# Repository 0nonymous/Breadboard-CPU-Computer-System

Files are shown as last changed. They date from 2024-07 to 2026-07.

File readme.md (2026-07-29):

# 8-Bit Microcoded Breadboard CPU

## Overview

The CPU

This project is a fully microcoded 8-bit CPU designed from scratch and implemented using 100+ 74LS-series ICs across 40+ breadboards.

The system includes:

- Custom 8-bit CISC-style instruction set (0x00–0x45 implemented)
- 8-bit data bus
- 16-bit address bus (64KB address space)
- Fully horizontal microcoded control unit (48-bit control word)
- 6 × AT28C16 EEPROM control store
- Memory-mapped I/O
- 6522 VIA interface (32 GPIO)
- Dual-port shared memory VGA subsystem
- Custom Python two-pass assembler and ROM flashing pipeline
- Working assembly programs including Snake

This is the third architectural iteration. Earlier versions exposed architectural limitations. The current version runs reliably at approximately ~0.25 MHz.

---

## Assembly Syntax

The assembler uses suffix symbols to indicate addressing modes:

- `$` = Immediate
- `@` = Absolute
- `#` = Indirect (pointer-based)
- `&` = Absolute + X offset
- No suffix = Implied

Example:
```
lda $10
lda @2000
lda #3000
lda &4000
inx
```

---

## Complete Instruction Encoding Table

```
0x00  lda $
0x01  lda @
0x02  lda #
0x03  lda &

0x04  ldx $
0x05  ldx @
0x06  ldx #
0x07  ldx &

0x08  inx
0x09  dex
0x0A  txa
0x0B  tax

0x0C  add $
0x0D  add @
0x0E  add #
0x0F  add &

0x10  sub $
0x11  sub @
0x12  sub #
0x13  sub &

0x14  adc $
0x15  adc @
0x16  adc #
0x17  adc &

0x18  sbc $
0x19  sbc @
0x1A  sbc #
0x1B  sbc &

0x1C  and $
0x1D  and @
0x1E  and #
0x1F  and &

0x20  orr $
0x21  orr @
0x22  orr #
0x23  orr &

0x24  shr
0x25  shl
0x26  ror
0x27  rol

0x28  sta @
0x29  sta #
0x2A  sta &

0x2B  stx @
0x2C  stx #
0x2D  stx &

0x2E  pla
0x2F  pha
0x30  plx
0x31  phx
0x32  plf
0x33  phf

0x34  xla
0x35  xlx

0x36  jsr @
0x37  rsr

0x38  clf
0x39  msk
0x3A  umk

0x3B  jmp @
0x3C  beq @
0x3D  bne @
0x3E  bmi @
0x3F  bpl @
0x40  bcs @
0x41  bcc @

0x42  ila
0x43  ilx
0x44  isa
0x45  isx
```

---

## CPU Architecture

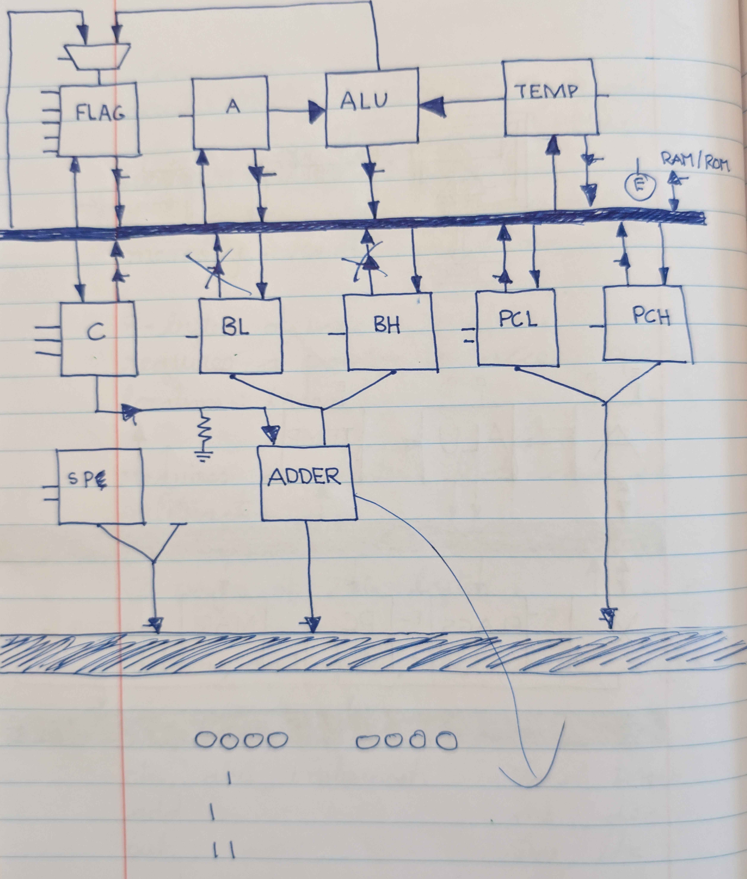
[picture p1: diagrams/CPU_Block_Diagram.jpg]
Block Diagrams


### Registers

- A — 8-bit accumulator
- B — 8-bit helper register
- X — 8-bit index register
- SP — 8-bit stack pointer (descending from 0xFF)
- PC — 16-bit program counter
- MAR — 16-bit memory address register
- IR — 8-bit instruction register
- Flags (3-bit):
  - Zero
  - Carry
  - Negative

---

## Buses and Datapath

- 8-bit internal data bus
- 16-bit address bus
- Shared bus architecture with gated register in/out signals
- MAR handles memory addressing
- PC high/low bytes independently gated

---

## ALU Implementation

The ALU is implemented using discrete TTL logic:

- 74LS283 — Addition core
- 74LS86 — 2's Complement
- 74LS08 — AND
- 74LS32 — OR
- Shift/rotate implemented via combinational wiring and arithmetic reuse
- Flag updates controlled via microcode signals (C SET, SZ SET, etc.)

---

## Microcoded Control Unit

Control Signals

The CPU uses a horizontal microcode architecture.

- Microinstruction width: 48 bits
- Control store: 6 × AT28C16 EEPROMs
- Microaddress width: 11 bits
- Microaddress formation:
  opcode[7:0] || microstep[2:0]
- Maximum microsteps per instruction: 7 (+ fetch cycle)

The microstep counter increments sequentially and overflows to reset.

Conditional branches do not alter microcode sequencing.  
Instead, discrete logic gates PC load signals based on flag conditions (Z, C, S).

Each microinstruction directly drives register enables, ALU operations, bus drivers, PC control, memory read/write, and flag updates.

---

## Memory Map

Total address space: 64KB

Current configuration includes:

- 2KB ROM
- 6522 VIA (32 GPIO)
- Memory-mapped I/O
- ~512B dual-port shared RAM (VGA subsystem)

Stack resides in a dedicated page and grows downward.

---

## VGA Subsystem

The CPU integrates with a separate VGA driver module.

Features:

- Text mode output
- 25 columns × 16 rows
- Hardware-assisted scrolling
- Dual-port shared memory interface between CPU and VGA driver
- Polling-based communication

The CPU writes character data into shared dual-port memory.  
The VGA module independently reads this memory to generate video timing and pixel output.

VGA signal generation approach was inspired by Ben Eater’s methodology and adapted for this architecture.

---

## Toolchain

Custom Python-based programming pipeline:

Two-pass assembler:
- Pass 1: label resolution
- Pass 2: opcode and operand encoding

Outputs a hex array representation of machine code.

A secondary Python script converts the output into binary format for ROM flashing via XGPro.

---

## Programs Written

- Instruction verification programs
- Fibonacci sequence
- Calculator utilities
- Keypad-driven applications
- VGA name/text rendering
- Snake (fully playable)

---

## Hardware Engineering and Debugging

Major issue encountered:
- Race condition causing unintended PC double-increment due to propagation delay

Debugging involved:

- Oscilloscope-based timing analysis
- Star power distribution layout
- Extensive decoupling capacitors
- Signal integrity stabilization

System runs reliably at approximately ~1 MHz.  
Estimated current draw: ~1.2–1.6A under load.

---

## Design Influences

- Instruction set loosely inspired by 6502 concepts
- Breadboard methodology and VGA experimentation influenced by Ben Eater
- Control logic, ISA structure, microcode, and integration independently designed

---

## Future Work

- Implement machine code monitor
- Potential RISC-style redesign
- FPGA implementation exploration
- Pipelining experimentation

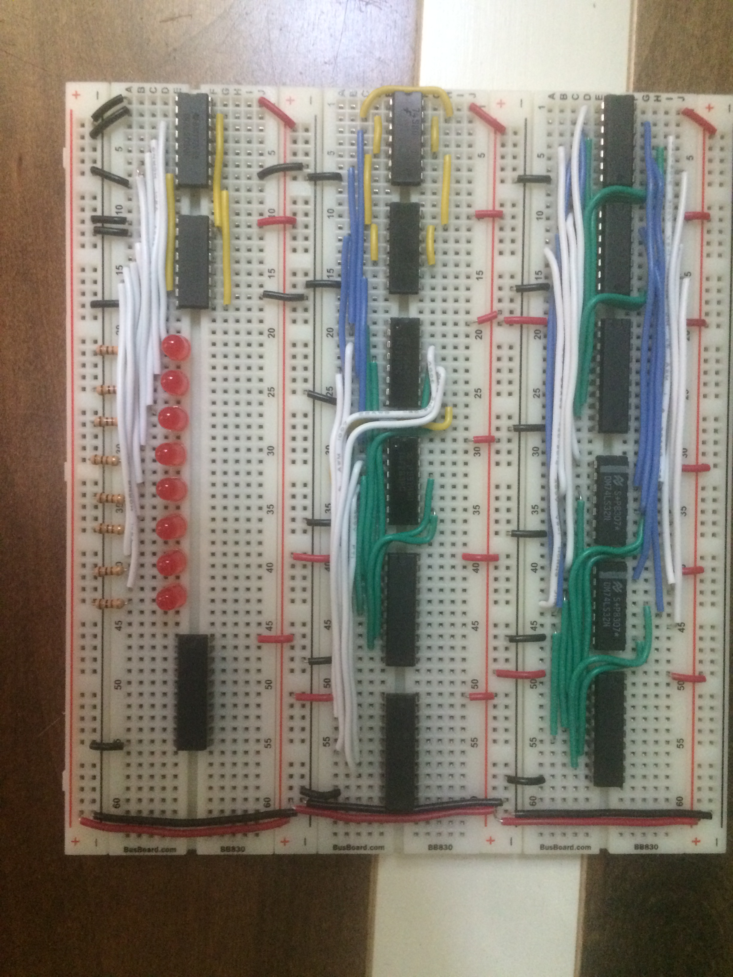
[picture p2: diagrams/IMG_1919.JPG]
A Register and ALU

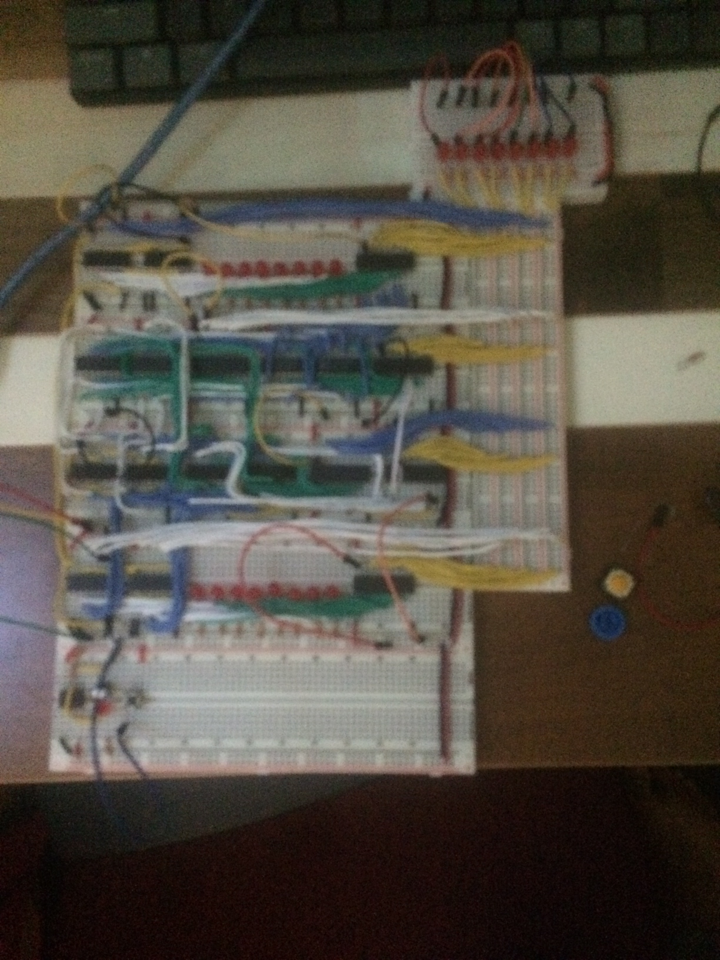
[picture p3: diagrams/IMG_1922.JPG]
A Registers, B Register, ALU, Data Bus, and Clock

Power Distribution
Decoupling Capacitors

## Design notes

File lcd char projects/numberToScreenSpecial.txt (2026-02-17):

; keypad = port b

; port initialization - set port b to half input and half output
  lda $0f
  sta @fee3

; port initialization - set port a to full output
  lda $ff
  sta @fee2

; functions: initalize screen
; functions: shift data
; functions: send to screen
; variables: index
; addresses: fef3 ddra, fef2 ddrb 
; addresses: fef1 ra, fef0 rb

; create some space: 0801, 0802, 0803, 0804 msb to lsb for digit 1; 0806, 0807, 0808, 0809
; pointer 0800 val of 01
  lda $00
  sta @0800

; set ports to output
  lda $ff
  sta @fef2
  sta @fef3

; initalize
  lda $38
  sta @fef1
  lda $02
  sta @fef0
  lda $00
  sta @fef0

; set parameters
  lda $0f
  sta @fef1
  lda $02
  sta @fef0
  lda $00
  sta @fef0

; increment lcd
  lda $06 ;26
  sta @fef1
  lda $02
  sta @fef0
  lda $00
  sta @fef0

; main loop
mainLoop:
  jsr @readKeypad
  jsr @encodeKeypad

; experimental: check if new key is pressed
  pha  ; save a copy of 'A'
  sub @fee0  ; check how it compares to a previous state
  pla  ; return 'A' to its original state
  sta @fee0
  beq @theTrueNextStep

ifUnique:
  pha  
  sub $10
  pla  
  beq @theTrueNextStep

ifReadyToPrint:
; save an incremenet
  ldx @0800
  sta &0801
  inx  
  stx @0800
  jsr @printer

theNextStep:
  lda @0800
  tax  
  sub $04
  beq @recall
  txa  
  sub $09
  beq @operate
  jmp @theTrueNextStep

recall:
  ldx @0800
  inx  
  stx @0800
  lda $fb
  jsr @printer
  jmp @theTrueNextStep

operate:
  ldx @0800
  inx  
  stx @0800
  lda $0d
  jsr @printer
  add $00

  ldx $03
  jsr @addDigit
  dex  
  jsr @addDigit
  dex  
  jsr @addDigit
  dex  
  jsr @addDigit

  lda @0801
  jsr @printer
  lda @0802
  jsr @printer
  lda @0803
  jsr @printer
  lda @0804
  jsr @printer

theTrueNextStep:
  jmp @mainLoop

printer:
  pha  
  add $30  ; offset to ASCII
  phx  
  pha  
  jsr @print
  pla  
  plx  
  pla  
  rsr  

; read keypad function - return value in a register
readKeypad:
; push everything to stack
  phx  
  phf  

; create an iterator
  lda $01

readKeypadLoop:
  tax  
  sta @fee1
  sub @fee1
  bne @readKeypadBreak
  txa  
  sub $08
  beq @readKeypadBreak
  txa  
  shl  
  jmp @readKeypadLoop

readKeypadBreak:
  lda @fee1

; pull everything from stack
  plf  
  plx  
  rsr  

encodeKeypad:
  phx  
  phf  

  ldx $00 ; create an iterator

encodeKeypadLoop:
  pha  ; preserve value in a register
  sub &encodingArray
  pla  
  beq @encodeKeypadBreak
  pha  
  inx  
  txa  
  sub $10
  pla  
  bne @encodeKeypadLoop

encodeKeypadBreak:
  txa  
  plf  
  plx  
  rsr  

print:
  ldx $03
  xla  
  sta @fef1
  lda $03
  sta @fef0
  lda $00
  sta @fef0 
  rsr  

addDigit:
; take number from 0801 + x where x is preserved
; use flags
  pha  

  lda &0801
  adc &0806

  sub $0a
  bpl @greaterThan9
  jmp @lessThan10

greaterThan9:
  sta &0801
  lda $ff
  add $01
  jmp @addDigitConverge

lessThan10:
  add $0a
  sta &0801
  add $00
  jmp @addDigitConverge

addDigitConverge:
  pla  
  rsr  

encodingArray:
  byt $28
  byt $11
  byt $21
  byt $41

  byt $12
  byt $22
  byt $42
  byt $14

  byt $24
  byt $44
  byt $81
  byt $82

  byt $84
  byt $88
  byt $18
  byt $48

  end

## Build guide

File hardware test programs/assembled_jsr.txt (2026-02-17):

[0x3b,0x1,0x5,0x0,0x0,0x0,0x0,0x0,0x0,0x0,0x0,0x0,0x0,0x0,0x0,0x0,0x0,0x0,0x0,0x0,0x0,0x0,0x0,0x0,0x0,0x0,0x0,0x0,0x0,0x0,0x0,0x0,0x0,0x0,0x0,0x0,0x0,0x0,0x0,0x0,0x0,0x0,0x0,0x0,0x0,0x0,0x0,0x0,0x0,0x0,0x0,0x0,0x0,0x0,0x0,0x0,0x0,0x0,0x0,0x0,0x0,0x0,0x0,0x0,0x0,0x0,0x0,0x0,0x0,0x0,0x0,0x0,0x0,0x0,0x0,0x0,0x0,0x0,0x0,0x0,0x0,0x0,0x0,0x0,0x0,0x0,0x0,0x0,0x0,0x0,0x0,0x0,0x0,0x0,0x0,0x0,0x0,0x0,0x0,0x0,0x0,0x0,0x0,0x0,0x0,0x0,0x0,0x0,0x0,0x0,0x0,0x0,0x0,0x0,0x0,0x0,0x0,0x0,0x0,0x0,0x0,0x0,0x0,0x0,0x0,0x0,0x0,0x0,0x0,0x0,0x0,0x0,0x0,0x0,0x0,0x0,0x0,0x0,0x0,0x0,0x0,0x0,0x0,0x0,0x0,0x0,0x0,0x0,0x0,0x0,0x0,0x0,0x0,0x0,0x0,0x0,0x0,0x0,0x0,0x0,0x0,0x0,0x0,0x0,0x0,0x0,0x0,0x0,0x0,0x0,0x0,0x0,0x0,0x0,0x0,0x0,0x0,0x0,0x0,0x0,0x0,0x0,0x0,0x0,0x0,0x0,0x0,0x0,0x0,0x0,0x0,0x0,0x0,0x0,0x0,0x0,0x0,0x0,0x0,0x0,0x0,0x0,0x0,0x0,0x0,0x0,0x0,0x0,0x0,0x0,0x0,0x0,0x0,0x0,0x0,0x0,0x0,0x0,0x0,0x0,0x0,0x0,0x0,0x0,0x0,0x0,0x0,0x0,0x0,0x0,0x0,0x0,0x0,0x0,0x0,0x0,0x0,0x0,0x0,0x0,0x0,0x0,0x0,0x0,0x0,0x0,0x0,0x0,0x0,0x0,0x0,0x0,0x0,0x0,0x0,0x0,0x0,0x0,0x0,0x0,0x0,0x0,0x0,0x0,0x0,0x0,0x0,0x0,0x0,0x0,0x0,0x0,0x0,0x0,0x0,0x0,0x0,0x0,0x0,0x0,0x0,0x0,0x0,0x0,0x0,0x0,0x0,0x0,0x0,0x0,0x0,0x0,0x0,0x0,0x0,0x0,0x0,0x0,0x0,0x0,0x0,0x0,0x0,0x0,0x0,0x0,0x0,0x0,0x0,0x0,0x0,0x0,0x0,0x0,0x0,0x0,0x0,0x0,0x0,0x0,0x0,0x0,0x0,0x0,0x0,0x0,0x0,0x0,0x0,0x0,0x0,0x0,0x0,0x0,0x0,0x0,0x0,0x0,0x0,0x0,0x0,0x0,0x0,0x0,0x0,0x0,0x0,0x0,0x0,0x0,0x0,0x0,0x0,0x0,0x0,0x0,0x0,0x0,0x0,0x0,0x0,0x0,0x0,0x0,0x0,0x0,0x0,0x0,0x0,0x0,0x0,0x0,0x0,0x0,0x0,0x0,0x0,0x0,0x0,0x0,0x0,0x0,0x0,0x0,0x0,0x0,0x0,0x0,0x0,0x0,0x0,0x0,0x0,0x0,0x0,0x0,0x0,0x0,0x0,0x0,0x0,0x0,0x0,0x0,0x0,0x0,0x0,0x0,0x0,0x0,0x0,0x0,0x0,0x0,0x0,0x0,0x0,0x0,0x0,0x0,0x0,0x0,0x0,0x0,0x0,0x0,0x0,0x0,0x0,0x0,0x0,0x0,0x0,0x0,0x0,0x0,0x0,0x0,0x0,0x0,0x0,0x0,0x0,0x0,0x0,0x0,0x0,0x0,0x0,0x0,0x0,0x0,0x0,0x0,0x0,0x0,0x0,0x0,0x0,0x0,0x0,0x0,0x0,0x0,0x0,0x0,0x0,0x0,0x0,0x0,0x0,0x0,0x0,0x0,0x0,0x0,0x0,0x0,0x0,0x0,0x0,0x0,0x0,0x0,0x0,0x0,0x0,0x0,0x0,0x0,0x0,0x0,0x0,0x0,0x0,0x0,0x0,0x0,0x0,0x0,0x0,0x0,0x0,0x0,0x0,0x0,0x0,0x0,0x0,0x0,0x0,0x0,0x0,0x0,0x0,0x0,0x0,0x0,0x0,0x0,0x0,0x0,0x0,0x0,0x0,0x0,0x0,0x0,0x0,0x0,0x0,0x0,0x0,0x0,0x0,0x0,0x0,0x0,0x0,0x0,0x0,0x0,0x0,0x0,0x0,0x0,0x0,0x0,0x0,0x0,0x0,0x0,0x0,0x0,0x0,0x0,0x0,0x0,0x0,0x0,0x0,0x0,0x0,0x0,0x0,0x0,0x0,0x0,0x0,0x0,0x0,0x0,0x0,0x0,0x0,0x0,0x0,0x0,0x0,0x0,0x0,0x0,0x0,0x0,0x0,0x0,0x0,0x0,0x0,0x0,0x0,0x0,0x0,0x0,0x0,0x0,0x0,0x0,0x0,0x0,0x0,0x0,0x0,0x0,0x0,0x0,0x0,0x0,0x0,0x0,0x0,0x0,0x0,0x0,0x0,0x0,0x0,0x0,0x0,0x0,0x0,0x0,0x0,0x0,0x0,0x0,0x0,0x0,0x0,0x0,0x0,0x0,0x0,0x0,0x0,0x0,0x0,0x0,0x0,0x0,0x0,0x0,0x0,0x0,0x0,0x0,0x0,0x0,0x0,0x0,0x0,0x0,0x0,0x0,0x0,0x0,0x0,0x0,0x0,0x0,0x0,0x0,0x0,0x0,0x0,0x0,0x0,0x0,0x0,0x0,0x0,0x0,0x0,0x0,0x0,0x0,0x0,0x0,0x0,0x0,0x0,0x0,0x0,0x0,0x0,0x0,0x0,0x0,0x0,0x0,0x0,0x0,0x0,0x0,0x0,0x0,0x0,0x0,0x0,0x0,0x0,0x0,0x0,0x0,0x0,0x0,0x0,0x0,0x0,0x0,0x0,0x0,0x0,0x0,0x0,0x0,0x0,0x0,0x0,0x0,0x0,0x0,0x0,0x0,0x0,0x0,0x0,0x0,0x0,0x0,0x0,0x0,0x0,0x0,0x0,0x0,0x0,0x0,0x0,0x0,0x0,0x0,0x0,0x0,0x0,0x0,0x0,0x0,0x0,0x0,0x0,0x0,0x0,0x0,0x0,0x0,0x0,0x0,0x0,0x0,0x0,0x0,0x0,0x0,0x0,0x0,0x0,0x0,0x0,0x0,0x0,0x0,0x0,0x0,0x0,0x0,0x0,0x0,0x0,0x0,0x0,0x0,0x0,0x0,0x0,0x0,0x0,0x0,0x0,0x0,0x0,0x0,0x0,0x0,0x0,0x0,0x0,0x0,0x0,0x0,0x0,0x0,0x0,0x0,0x0,0x0,0x0,0x0,0x0,0x0,0x0,0x0,0x0,0x0,0x0,0x0,0x0,0x0,0x0,0x0,0x0,0x0,0x0,0x0,0x0,0x0,0x0,0x0,0x0,0x0,0x0,0x0,0x0,0x0,0x0,0x0,0x0,0x0,0x0,0x0,0x0,0x0,0x0,0x0,0x0,0x0,0x0,0x0,0x0,0x0,0x0,0x0,0x0,0x0,0x0,0x0,0x0,0x0,0x0,0x0,0x0,0x0,0x0,0x0,0x0,0x0,0x0,0x0,0x0,0x0,0x0,0x0,0x0,0x0,0x0,0x0,0x0,0x0,0x0,0x0,0x0,0x0,0x0,0x0,0x0,0x0,0x0,0x0,0x0,0x0,0x0,0x0,0x0,0x0,0x0,0x0,0x0,0x0,0x0,0x0,0x0,0x0,0x0,0x0,0x0,0x0,0x0,0x0,0x0,0x0,0x0,0x0,0x0,0x0,0x0,0x0,0x0,0x0,0x0,0x0,0x0,0x0,0x0,0x0,0x0,0x0,0x0,0x0,0x0,0x0,0x0,0x0,0x0,0x0,0x0,0x0,0x0,0x0,0x0,0x0,0x0,0x0,0x0,0x0,0x0,0x0,0x0,0x0,0x0,0x0,0x0,0x0,0x0,0x0,0x0,0x0,0x0,0x0,0x0,0x0,0x0,0x0,0x0,0x0,0x0,0x0,0x0,0x0,0x0,0x0,0x0,0x0,0x0,0x0,0x0,0x0,0x0,0x0,0x0,0x0,0x0,0x0,0x0,0x0,0x0,0x0,0x0,0x0,0x0,0x0,0x0,0x0,0x0,0x0,0x0,0x0,0x0,0x0,0x0,0x0,0x0,0x0,0x0,0x0,0x0,0x0,0x0,0x0,0x0,0x0,0x0,0x0,0x0,0x0,0x0,0x0,0x0,0x0,0x0,0x0,0x0,0x0,0x0,0x0,0x0,0x0,0x0,0x0,0x0,0x0,0x0,0x0,0x0,0x0,0x0,0x0,0x0,0x0,0x0,0x0,0x0,0x0,0x0,0x0,0x0,0x0,0x0,0x0,0x0,0x0,0x0,0x0,0x0,0x0,0x0,0x0,0x0,0x0,0x0,0x0,0x0,0x0,0x0,0x0,0x0,0x0,0x0,0x0,0x0,0x0,0x0,0x0,0x0,0x0,0x0,0x0,0x0,0x0,0x0,0x0,0x0,0x0,0x0,0x0,0x0,0x0,0x0,0x0,0x0,0x0,0x0,0x0,0x0,0x0,0x0,0x0,0x0,0x0,0x0,0x0,0x0,0x0,0x0,0x0,0x0,0x0,0x0,0x0,0x0,0x0,0x0,0x0,0x0,0x0,0x0,0x0,0x0,0x0,0x0,0x0,0x0,0x0,0x0,0x0,0x0,0x0,0x0,0x0,0x0,0x0,0x0,0x0,0x0,0x0,0x0,0x0,0x0,0x0,0x0,0x0,0x0,0x0,0x0,0x0,0x0,0x0,0x0,0x0,0x0,0x0,0x0,0x0,0x0,0x0,0x0,0x0,0x0,0x0,0x0,0x0,0x0,0x0,0x0,0x0,0x0,0x0,0x0,0x0,0x0,0x0,0x0,0x0,0x0,0x0,0x0,0x0,0x0,0x0,0x0,0x0,0x0,0x0,0x0,0x0,0x0,0x0,0x0,0x0,0x0,0x0,0x0,0x0,0x0,0x0,0x0,0x0,0x0,0x0,0x0,0x0,0x0,0x0,0x0,0x0,0x0,0x0,0x0,0x0,0x0,0x0,0x0,0x0,0x0,0x0,0x0,0x0,0x0,0x0,0x0,0x0,0x0,0x0,0x0,0x0,0x0,0x0,0x0,0x0,0x0,0x0,0x0,0x0,0x0,0x0,0x0,0x0,0x0,0x0,0x0,0x0,0x0,0x0,0x0,0x0,0x0,0x0,0x0,0x0,0x0,0x0,0x0,0x0,0x0,0x0,0x0,0x0,0x0,0x0,0x0,0x0,0x0,0x0,0x0,0x0,0x0,0x0,0x0,0x0,0x0,0x0,0x0,0x0,0x0,0x0,0x0,0x0,0x0,0x0,0x0,0x0,0x0,0x36,0xa,0x6,0x3b,0x1,0x5,0x0,0x0,0x0,0x0,0x0,0x0,0x0,0x0,0x0,0x0,0x0,0x0,0x0,0x0,0x0,0x0,0x0,0x0,0x0,0x0,0x0,0x0,0x0,0x0,0x0,0x0,0x0,0x0,0x0,0x0,0x0,0x0,0x0,0x0,0x0,0x0,0x0,0x0,0x0,0x0,0x0,0x0,0x0,0x0,0x0,0x0,0x0,0x0,0x0,0x0,0x0,0x0,0x0,0x0,0x0,0x0,0x0,0x0,0x0,0x0,0x0,0x0,0x0,0x0,0x0,0x0,0x0,0x0,0x0,0x0,0x0,0x0,0x0,0x0,0x0,0x0,0x0,0x0,0x0,0x0,0x0,0x0,0x0,0x0,0x0,0x0,0x0,0x0,0x0,0x0,0x0,0x0,0x0,0x0,0x0,0x0,0x0,0x0,0x0,0x0,0x0,0x0,0x0,0x0,0x0,0x0,0x0,0x0,0x0,0x0,0x0,0x0,0x0,0x0,0x0,0x0,0x0,0x0,0x0,0x0,0x0,0x0,0x0,0x0,0x0,0x0,0x0,0x0,0x0,0x0,0x0,0x0,0x0,0x0,0x0,0x0,0x0,0x0,0x0,0x0,0x0,0x0,0x0,0x0,0x0,0x0,0x0,0x0,0x0,0x0,0x0,0x0,0x0,0x0,0x0,0x0,0x0,0x0,0x0,0x0,0x0,0x0,0x0,0x0,0x0,0x0,0x0,0x0,0x0,0x0,0x0,0x0,0x0,0x0,0x0,0x0,0x0,0x0,0x0,0x0,0x0,0x0,0x0,0x0,0x0,0x0,0x0,0x0,0x0,0x0,0x0,0x0,0x0,0x0,0x0,0x0,0x0,0x0,0x0,0x0,0x0,0x0,0x0,0x0,0x0,0x0,0x0,0x0,0x0,0x0,0x0,0x0,0x0,0x0,0x0,0x0,0x0,0x0,0x0,0x0,0x0,0x0,0x0,0x0,0x0,0x0,0x0,0x0,0x0,0x0,0x0,0x0,0x0,0x0,0x0,0x0,0x0,0x0,0x0,0x0,0x0,0x0,0x0,0x0,0x0,0x0,0x0,0x0,0x0,0x0,0x0,0x0,0x0,0x0,0x0,0x0,0x0,0x0,0x0,0x37,0x0,0x0,0x0,0x0,0x0,0x0,0x0,0x0,0x0,0x0,0x0,0x0,0x0,0x0,0x0,0x0,0x0,0x0,0x0,0x0,0x0,0x0,0x0,0x0,0x0,0x0,0x0,0x0,0x0,0x0,0x0,0x0,0x0,0x0,0x0,0x0,0x0,0x0,0x0,0x0,0x0,0x0,0x0,0x0,0x0,0x0,0x0,0x0,0x0,0x0,0x0,0x0,0x0,0x0,0x0,0x0,0x0,0x0,0x0,0x0,0x0,0x0,0x0,0x0,0x0,0x0,0x0,0x0,0x0,0x0,0x0,0x0,0x0,0x0,0x0,0x0,0x0,0x0,0x0,0x0,0x0,0x0,0x0,0x0,0x0,0x0,0x0,0x0,0x0,0x0,0x0,0x0,0x0,0x0,0x0,0x0,0x0,0x0,0x0,0x0,0x0,0x0,0x0,0x0,0x0,0x0,0x0,0x0,0x0,0x0,0x0,0x0,0x0,0x0,0x0,0x0,0x0,0x0,0x0,0x0,0x0,0x0,0x0,0x0,0x0,0x0,0x0,0x0,0x0,0x0,0x0,0x0,0x0,0x0,0x0,0x0,0x0,0x0,0x0,0x0,0x0,0x0,0x0,0x0,0x0,0x0,0x0,0x0,0x0,0x0,0x0,0x0,0x0,0x0,0x0,0x0,0x0,0x0,0x0,0x0,0x0,0x0,0x0,0x0,0x0,0x0,0x0,0x0,0x0,0x0,0x0,0x0,0x0,0x0,0x0,0x0,0x0,0x0,0x0,0x0,0x0,0x0,0x0,0x0,0x0,0x0,0x0,0x0,0x0,0x0,0x0,0x0,0x0,0x0,0x0,0x0,0x0,0x0,0x0,0x0,0x0,0x0,0x0,0x0,0x0,0x0,0x0,0x0,0x0,0x0,0x0,0x0,0x0,0x0,0x0,0x0,0x0,0x0,0x0,0x0,0x0,0x0,0x0,0x0,0x0,0x0,0x0,0x0,0x0,0x0,0x0,0x0,0x0,0x0,0x0,0x0,0x0,0x0,0x0,0x0,0x0,0x0,0x0,0x0,0x0,0x0,0x0,0x0,0x0,0x0,0x0,0x0,0x0,0x0,0x0,0x0,0x0,0x0,0x0,0x0,0x0,0x0,0x0,0x0,0x0,0x0,0x0,0x0,0x0,0x0,0x0,0x0,0x0,0x0,0x0,0x0,0x0,0x0,0x0,0x0,0x0,0x0,0x0,0x0,0x0,0x0,0x0,0x0,0x0,0x0,0x0,0x0,0x0,0x0,0x0,0x0,0x0,0x0,0x0,0x0,0x0,0x0,0x0,0x0,0x0,0x0,0x0,0x0,0x0,0x0,0x0,0x0,0x0,0x0,0x0,0x0,0x0,0x0,0x0,0x0,0x0,0x0,0x0,0x0,0x0,0x0,0x0,0x0,0x0,0x0,0x0,0x0,0x0,0x0,0x0,0x0,0x0,0x0,0x0,0x0,0x0,0x0,0x0,0x0,0x0,0x0,0x0,0x0,0x0,0x0,0x0,0x0,0x0,0x0,0x0,0x0,0x0,0x0,0x0,0x0,0x0,0x0,0x0,0x0,0x0,0x0,0x0,0x0,0x0,0x0,0x0,0x0,0x0,0x0,0x0,0x0,0x0,0x0,0x0,0x0,0x0,0x0,0x0,0x0,0x0,0x0,0x0,0x0,0x0,0x0,0x0,0x0,0x0,0x0,0x0,0x0,0x0,0x0,0x0,0x0,0x0,0x0,0x0,0x0,0x0,0x0,0x0,0x0,0x0,0x0,0x0,0x0,0x0,0x0,0x0,0x0,0x0,0x0,0x0,0x0,0x0,0x0,0x0,0x0,0x0,0x0,0x0,0x0,0x0,0x0,0x0,0x0,0x0,0x0,0x0,0x0,0x0,0x0,0x0,0x0,0x0,0x0,0x0,0x0,0x0,0x0,0x0,0x0,0x0,0x0,0x0,0x0,0x0,0x0,0x0,0x0,0x0,0x0,0x0,0x0,0x0,0x0,0x0,0x0,0x0,0x0,0x0,0x0,0x0,0x0,0x0,0x0,0x0,0x0,0x0,0x0,0x0,0x0,0x0,0x0,0x0,0x0,0x0,0x0,0x0,0x0,0x0,0x0,0x0,0x0,0x0,0x0,0x0,0x0,0x0,0x0,0x0,0x0,0x0,0x0,0x0,]

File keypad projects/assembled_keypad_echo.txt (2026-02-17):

[0x0,0xff,0x28,0xf2,0xfe,0x0,0x3,0x4,0x23,0x28,0xf0,0xfe,0x2b,0xf0,0xfe,0x28,0xf0,0xfe,0x2b,0xf0,0xfe,0x28,0xf0,0xfe,0x2b,0xf0,0xfe,0x28,0xf0,0xfe,0x0,0x2,0x4,0x22,0x28,0xf0,0xfe,0x2b,0xf0,0xfe,0x28,0xf0,0xfe,0x2b,0xf0,0xfe,0x28,0xf0,0xfe,0x0,0x8,0x4,0x28,0x28,0xf0,0xfe,0x2b,0xf0,0xfe,0x28,0xf0,0xfe,0x0,0x0,0x4,0x20,0x28,0xf0,0xfe,0x2b,0xf0,0xfe,0x28,0xf0,0xfe,0x0,0xc,0x4,0x2c,0x28,0xf0,0xfe,0x2b,0xf0,0xfe,0x28,0xf0,0xfe,0x0,0x0,0x4,0x20,0x28,0xf0,0xfe,0x2b,0xf0,0xfe,0x28,0xf0,0xfe,0x0,0x2,0x4,0x22,0x28,0xf0,0xfe,0x2b,0xf0,0xfe,0x28,0xf0,0xfe,0x0,0x0,0x4,0x20,0x28,0xf0,0xfe,0x2b,0xf0,0xfe,0x28,0xf0,0xfe,0x0,0x6,0x4,0x26,0x28,0xf0,0xfe,0x2b,0xf0,0xfe,0x28,0xf0,0xfe,0x0,0x14,0x4,0x34,0x28,0xf0,0xfe,0x2b,0xf0,0xfe,0x28,0xf0,0xfe,0x0,0x18,0x4,0x38,0x28,0xf0,0xfe,0x2b,0xf0,0xfe,0x28,0xf0,0xfe,0x3b,0xa6,0x0,0x0,0x0,0x0,0x0,0x0,0x0,0x0,0x0,0x0,0x0,0x0,0x0,0x0,0x0,0x0,0x0,0x0,0x0,0x0,0x0,0x0,0x0,0x0,0x0,0x0,0x0,0x0,0x0,0x0,0x0,0x0,0x0,0x0,0x0,0x0,0x0,0x0,0x0,0x0,0x0,0x0,0x0,0x0,0x0,0x0,0x0,0x0,0x0,0x0,0x0,0x0,0x0,0x0,0x0,0x0,0x0,0x0,0x0,0x0,0x0,0x0,0x0,0x0,0x0,0x0,0x0,0x0,0x0,0x0,0x0,0x0,0x0,0x0,0x0,0x0,0x0,0x0,0x0,0x0,0x0,0x0,0x0,0x0,0x0,0x0,0x0,0x0,0x0,0x0,0x0,0x0,0x0,0x0,0x0,0x0,0x0,0x0,0x0,0x0,0x0,0x0,0x0,0x0,0x0,0x0,0x0,0x0,0x0,0x0,0x0,0x0,0x0,0x0,0x0,0x0,0x0,0x0,0x0,0x0,0x0,0x0,0x0,0x0,0x0,0x0,0x0,0x0,0x0,0x0,0x0,0x0,0x0,0x0,0x0,0x0,0x0,0x0,0x0,0x0,0x0,0x0,0x0,0x0,0x0,0x0,0x0,0x0,0x0,0x0,0x0,0x0,0x0,0x0,0x0,0x0,0x0,0x0,0x0,0x0,0x0,0x0,0x0,0x0,0x0,0x0,0x0,0x0,0x0,0x0,0x0,0x0,0x0,0x0,0x0,0x0,0x0,0x0,0x0,0x0,0x0,0x0,0x0,0x0,0x0,0x0,0x0,0x0,0x0,0x0,0x0,0x0,0x0,0x0,0x0,0x0,0x0,0x0,0x0,0x0,0x0,0x0,0x0,0x0,0x0,0x0,0x0,0x0,0x0,0x0,0x0,0x0,0x0,0x0,0x0,0x0,0x0,0x0,0x0,0x0,0x0,0x0,0x0,0x0,0x0,0x0,0x0,0x0,0x0,0x0,0x0,0x0,0x0,0x0,0x0,0x0,0x0,0x0,0x0,0x0,0x0,0x0,0x0,0x0,0x0,0x0,0x0,0x0,0x0,0x0,0x0,0x0,0x0,0x0,0x0,0x0,0x0,0x0,0x0,0x0,0x0,0x0,0x0,0x0,0x0,0x0,0x0,0x0,0x0,0x0,0x0,0x0,0x0,0x0,0x0,0x0,0x0,0x0,0x0,0x0,0x0,0x0,0x0,0x0,0x0,0x0,0x0,0x0,0x0,0x0,0x0,0x0,0x0,0x0,0x0,0x0,0x0,0x0,0x0,0x0,0x0,0x0,0x0,0x0,0x0,0x0,0x0,0x0,0x0,0x0,0x0,0x0,0x0,0x0,0x0,0x0,0x0,0x0,0x0,0x0,0x0,0x0,0x0,0x0,0x0,0x0,0x0,0x0,0x0,0x0,0x0,0x0,0x0,0x0,0x0,0x0,0x0,0x0,0x0,0x0,0x0,0x0,0x0,0x0,0x0,0x0,0x0,0x0,0x0,0x0,0x0,0x0,0x0,0x0,0x0,0x0,0x0,0x0,0x0,0x0,0x0,0x0,0x0,0x0,0x0,0x0,0x0,0x0,0x0,0x0,0x0,0x0,0x0,0x0,0x0,0x0,0x0,0x0,0x0,0x0,0x0,0x0,0x0,0x0,0x0,0x0,0x0,0x0,0x0,0x0,0x0,0x0,0x0,0x0,0x0,0x0,0x0,0x0,0x0,0x0,0x0,0x0,0x0,0x0,0x0,0x0,0x0,0x0,0x0,0x0,0x0,0x0,0x0,0x0,0x0,0x0,0x0,0x0,0x0,0x0,0x0,0x0,0x0,0x0,0x0,0x0,0x0,0x0,0x0,0x0,0x0,0x0,0x0,0x0,0x0,0x0,0x0,0x0,0x0,0x0,0x0,0x0,0x0,0x0,0x0,0x0,0x0,0x0,0x0,0x0,0x0,0x0,0x0,0x0,0x0,0x0,0x0,0x0,0x0,0x0,0x0,0x0,0x0,0x0,0x0,0x0,0x0,0x0,0x0,0x0,0x0,0x0,0x0,0x0,0x0,0x0,0x0,0x0,0x0,0x0,0x0,0x0,0x0,0x0,0x0,0x0,0x0,0x0,0x0,0x0,0x0,0x0,0x0,0x0,0x0,0x0,0x0,0x0,0x0,0x0,0x0,0x0,0x0,0x0,0x0,0x0,0x0,0x0,0x0,0x0,0x0,0x0,0x0,0x0,0x0,0x0,0x0,0x0,0x0,0x0,0x0,0x0,0x0,0x0,0x0,0x0,0x0,0x0,0x0,0x0,0x0,0x0,0x0,0x0,0x0,0x0,0x0,0x0,0x0,0x0,0x0,0x0,0x0,0x0,0x0,0x0,0x0,0x0,0x0,0x0,0x0,0x0,0x0,0x0,0x0,0x0,0x0,0x0,0x0,0x0,0x0,0x0,0x0,0x0,0x0,0x0,0x0,0x0,0x0,0x0,0x0,0x0,0x0,0x0,0x0,0x0,0x0,0x0,0x0,0x0,0x0,0x0,0x0,0x0,0x0,0x0,0x0,0x0,0x0,0x0,0x0,0x0,0x0,0x0,0x0,0x0,0x0,0x0,0x0,0x0,0x0,0x0,0x0,0x0,0x0,0x0,0x0,0x0,0x0,0x0,0x0,0x0,0x0,0x0,0x0,0x0,0x0,0x0,0x0,0x0,0x0,0x0,0x0,0x0,0x0,0x0,0x0,0x0,0x0,0x0,0x0,0x0,0x0,0x0,0x0,0x0,0x0,0x0,0x0,0x0,0x0,0x0,0x0,0x0,0x0,0x0,0x0,0x0,0x0,0x0,0x0,0x0,0x0,0x0,0x0,0x0,0x0,0x0,0x0,0x0,0x0,0x0,0x0,0x0,0x0,0x0,0x0,0x0,0x0,0x0,0x0,0x0,0x0,0x0,0x0,0x0,0x0,0x0,0x0,0x0,0x0,0x0,0x0,0x0,0x0,0x0,0x0,0x0,0x0,0x0,0x0,0x0,0x0,0x0,0x0,0x0,0x0,0x0,0x0,0x0,0x0,0x0,0x0,0x0,0x0,0x0,0x0,0x0,0x0,0x0,0x0,0x0,0x0,0x0,0x0,0x0,0x0,0x0,0x0,0x0,0x0,0x0,0x0,0x0,0x0,0x0,0x0,0x0,0x0,0x0,0x0,0x0,0x0,0x0,0x0,0x0,0x0,0x0,0x0,0x0,0x0,0x0,0x0,0x0,0x0,0x0,0x0,0x0,0x0,0x0,0x0,0x0,0x0,0x0,0x0,0x0,0x0,0x0,0x0,0x0,0x0,0x0,0x0,0x0,0x0,0x0,0x0,0x0,0x0,0x0,0x0,0x0,0x0,0x0,0x0,0x0,0x0,0x0,0x0,0x0,0x0,0x0,0x0,0x0,0x0,0x0,0x0,0x0,0x0,0x0,0x0,0x0,0x0,0x0,0x0,0x0,0x0,0x0,0x0,0x0,0x0,0x0,0x0,0x0,0x0,0x0,0x0,0x0,0x0,0x0,0x0,0x0,0x0,0x0,0x0,0x0,0x0,0x0,0x0,0x0,0x0,0x0,0x0,0x0,0x0,0x0,0x0,0x0,0x0,0x0,0x0,0x0,0x0,0x0,0x0,0x0,0x0,0x0,0x0,0x0,0x0,0x0,0x0,0x0,0x0,0x0,0x0,0x0,0x0,0x0,0x0,0x0,0x0,0x0,0x0,0x0,0x0,0x0,0x0,0x0,0x0,0x0,0x0,0x0,0x0,0x0,0x0,0x0,0x0,0x0,0x0,0x0,0x0,0x0,0x0,0x0,0x0,0x0,0x0,0x0,0x0,0x0,0x0,0x0,0x0,0x0,0x0,0x0,0x0,0x0,0x0,0x0,0x0,0x0,0x0,0x0,0x0,0x0,0x0,0x0,0x0,0x0,0x0,0x0,0x0,0x0,0x0,0x0,0x0,0x0,0x0,0x0,0x0,0x0,0x0,0x0,0x0,0x0,0x0,0x0,0x0,0x0,0x0,0x0,0x0,0x0,0x0,0x0,0x0,0x0,0x0,0x0,0x0,0x0,0x0,0x0,0x0,0x0,0x0,0x0,0x0,0x0,0x0,0x0,0x0,0x0,0x0,0x0,0x0,0x0,0x0,0x0,0x0,0x0,0x0,0x0,0x0,0x0,0x0,0x0,0x0,0x0,0x0,0x0,0x0,0x0,0x0,0x0,0x0,0x0,0x0,0x0,0x0,0x0,0x0,0x0,0x0,0x0,0x0,0x0,0x0,0x0,0x0,0x0,0x0,0x0,0x0,0x0,0x0,0x0,0x0,0x0,0x0,0x0,0x0,0x0,0x0,0x0,0x0,0x0,0x0,0x0,0x0,0x0,0x0,0x0,0x0,0x0,0x0,0x0,0x0,0x0,0x0,0x0,0x0,0x0,0x0,0x0,0x0,0x0,0x0,0x0,0x0,0x0,0x0,0x0,0x0,0x0,0x0,0x0,0x0,0x0,0x0,0x0,0x0,0x0,0x0,0x0,0x0,0x0,0x0,0x0,0x0,0x0,0x0,0x0,0x0,0x0,0x0,0x0,0x0,0x0,0x0,0x0,0x0,0x0,0x0,0x0,0x0,0x0,0x0,0x0,0x0,0x0,0x0,0x0,0x0,0x0,0x0,0x0,0x0,0x0,0x0,0x0,0x0,0x0,0x0,0x0,0x0,0x0,0x0,0x0,0x0,0x0,0x0,0x0,0x0,0x0,0x0,0x0,0x0,0x0,0x0,0x0,0x0,0x0,0x0,0x0,0x0,0x0,0x0,0x0,0x0,0x0,0x0,0x0,0x0,0x0,0x0,0x0,0x0,0x0,0x0,0x0,0x0,0x0,0x0,0x0,0x0,0x0,0x0,0x0,0x0,0x0,0x0,0x0,0x0,0x0,0x0,0x0,0x0,0x0,0x0,0x0,0x0,0x0,0x0,0x0,0x0,0x0,0x0,0x0,0x0,0x0,0x0,0x0,0x0,0x0,0x0,0x0,0x0,0x0,0x0,0x0,0x0,0x0,0x0,0x0,0x0,0x0,0x0,0x0,0x0,0x0,0x0,0x0,0x0,0x0,0x0,0x0,0x0,0x0,0x0,0x0,0x0,0x0,0x0,0x0,0x0,0x0,0x0,0x0,0x0,0x0,0x0,0x0,0x0,0x0,0x0,0x0,0x0,0x0,0x0,0x0,0x0,0x0,0x0,0x0,0x0,0x0,0x0,0x0,0x0,0x0,0x0,0x0,0x0,0x0,0x0,0x0,0x0,0x0,0x0,0x0,0x0,0x0,0x0,0x0,0x0,0x0,0x0,0x0,0x0,0x0,0x0,0x0,0x0,0x0,0x0,0x0,0x0,0x0,0x0,0x0,0x0,0x0,0x0,0x0,0x0,0x0,0x0,0x0,0x0,0x0,0x0,0x0,0x0,0x0,0x0,0x0,0x0,0x0,0x0,0x0,0x0,0x0,0x0,0x0,0x0,0x0,0x0,0x0,0x0,0x0,0x0,0x0,0x0,0x0,0x0,0x0,0x0,0x0,0x0,0x0,0x0,0x0,0x0,0x0,0x0,0x0,0x0,0x0,0x0,0x0,0x0,0x0,0x0,0x0,0x0,0x0,0x0,0x0,0x0,0x0,0x0,0x0,0x0,0x0,0x0,0x0,0x0,0x0,0x0,0x0,0x0,0x0,0x0,0x0,0x0,0x0,0x0,0x0,0x0,0x0,0x0,0x0,0x0,0x0,0x0,0x0,0x0,0x0,0x0,0x0,0x0,0x0,0x0,0x0,0x0,0x0,0x0,0x0,0x0,0x0,0x0,0x0,0x0,0x0,0x0,0x0,0x0,0x0,0x0,0x0,0x0,0x0,0x0,0x0,0x0,0x0,0x0,0x0,0x0,0x0,0x0,0x0,0x0,0x0,0x0,0x0,0x0,0x0,0x0,0x0,0x0,0x0,0x0,0x0,0x0,0x0,0x0,0x0,0x0,0x0,0x0,0x0,0x0,0x0,0x0,0x0,0x0,0x0,0x0,0x0,0x0,0x0,0x0,0x0,0x0,0x0,0x0,0x0,0x0,0x0,0x0,0x0,0x0,0x0,0x0,0x0,0x0,0x0,0x0,0x0,0x0,0x0,0x0,0x0,0x0,0x0,0x0,0x0,0x0,0x0,0x0,0x0,0x0,0x0,0x0,0x0,0x0,0x0,0x0,0x0,0x0,0x0,0x0,0x0,0x0,0x0,0x0,0x0,0x0,0x0,0x0,0x0,0x0,0x0,0x0,0x0,0x0,0x0,0x0,0x0,0x0,0x0,0x0,0x0,0x0,0x0,0x0,0x0,0x0,0x0,0x0,0x0,0x0,0x0,0x0,0x0,0x0,0x0,0x0,0x0,0x0,0x0,0x0,0x0,0x0,0x0,0x0,0x0,0x0,0x0,0x0,0x0,0x0,0x0,0x0,0x0,0x0,0x0,0x0,0x0,0x0,0x0,0x0,0x0,0x0,0x0,0x0,0x0,0x0,0x0,0x0,0x0,0x0,0x0,0x0,0x0,0x0,0x0,0x0,0x0,0x0,0x0,0x0,0x0,0x0,0x0,0x0,0x0,0x0,0x0,0x0,0x0,0x0,0x0,0x0,0x0,0x0,0x0,0x0,0x0,0x0,0x0,0x0,0x0,0x0,0x0,0x0,0x0,0x0,0x0,0x0,0x0,0x0,0x0,0x0,0x0,0x0,0x0,0x0,0x0,0x0,0x0,0x0,0x0,0x0,0x0,0x0,0x0,0x0,0x0,0x0,0x0,0x0,0x0,0x0,0x0,0x0,0x0,0x0,0x0,0x0,0x0,0x0,0x0,0x0,0x0,0x0,0x0,0x0,0x0,0x0,0x0,0x0,0x0,0x0,0x0,0x0,0x0,0x0,0x0,0x0,0x0,0x0,0x0,0x0,0x0,0x0,0x0,0x0,0x0,0x0,0x0,0x0,0x0,0x0,0x0,0x0,0x0,0x0,0x0,0x0,0x0,0x0,0x0,0x0,0x0,0x0,0x0,0x0,0x0,0x0,0x0,0x0,0x0,0x0,0x0,0x0,0x0,0x0,0x0,0x0,0x0,0x0,0x0,0x0,0x0,0x0,0x0,0x0,0x0,0x0,0x0,0x0,0x0,0x0,0x0,0x0,0x0,0x0,0x0,0x0,0x0,0x0,0x0,0x0,0x0,0x0,0x0,0x0,0x0,0x0,0x0,0x0,0x0,0x0,0x0,0x0,0x0,0x0,0x0,0x0,0x0,0x0,0x0,0x0,0x0,0x0,0x0,0x0,0x0,0x0,0x0,0x0,0x0,0x0,0x0,0x0,0x0,0x0,0x0,0x0,0x0,0x0,0x0,0x0,0x0,0x0,0x0,0x0,0x0,0x0,0x0,0x0,0x0,0x0,0x0,0x0,0x0,0x0,0x0,0x0,0x0,0x0,0x0,0x0,0x0,0x0,0x0,0x0,0x0,0x0,0x0,0x0,0x0,0x0,0x0,0x0,0x0,0x0,0x0,0x0,0x0,0x0,0x0,0x0,0x0,0x0,0x0,0x0,0x0,0x0,0x0,0x0,0x0,0x0,0x0,0x0,0x0,0x0,0x0,0x0,0x0,0x0,0x0,0x0,0x0,0x0,0x0,0x0,0x0,0x0,0x0,0x0,0x0,0x0,0x0,0x0,0x0,0x0,0x0,0x0,0x0,0x0,0x0,0x0,0x0,0x0,0x0,0x0,0x0,0x0,0x0,0x0,0x0,0x0,0x0,0x0,0x0,0x0,0x0,0x0,0x0,0x0,0x0,0x0,0x0,0x0,0x0,0x0,0x0,0x0,0x0,0x0,0x0,0x0,0x0,0x0,0x0,0x0,0x0,0x0,0x0,0x0,0x0,0x0,0x0,0x0,0x0,0x0,0x0,0x0,0x0,0x0,0x0,0x0,0x0,0x0,0x0,0x0,0x0,0x0,0x0,0x0,0x0,0x0,0x0,0x0,0x0,0x0,0x0,0x0,0x0,0x0,0x0,0x0,0x0,0x0,0x0,0x0,0x0,0x0,0x0,0x0,0x0,0x0,0x0,0x0,0x0,0x0,0x0,0x0,0x0,0x0,0x0,0x0,0x0,0x0,0x0,0x0,0x0,0x0,0x0,0x0,0x0,0x0,0x0,0x0,0x0,0x0,0x0,0x0,0x0,0x0,0x0,0x0,0x0,]

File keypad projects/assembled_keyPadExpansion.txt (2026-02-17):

[0x0,0xf,0x28,0xe3,0xfe,0x0,0xff,0x28,0xe2,0xfe,0x36,0x16,0x0,0x36,0x35,0x0,0x28,0xe0,0xfe,0x3b,0xa,0x0,0x31,0x33,0x0,0x1,0xb,0x28,0xe1,0xfe,0x11,0xe1,0xfe,0x3d,0x2f,0x0,0xa,0x10,0x8,0x3c,0x2f,0x0,0xa,0x25,0x3b,0x1a,0x0,0x1,0xe1,0xfe,0x30,0x30,0x37,0x31,0x33,0x4,0x0,0x2f,0x13,0x4e,0x0,0x2e,0x3c,0x4a,0x0,0x2f,0x8,0xa,0x10,0x10,0x2e,0x3d,0x39,0x0,0xa,0x32,0x30,0x37,40,17,33,65,18,34,66,20,36,68,129,130,132,136,24,72,0x0,0x0,0x0,0x0,0x0,0x0,0x0,0x0,0x0,0x0,0x0,0x0,0x0,0x0,0x0,0x0,0x0,0x0,0x0,0x0,0x0,0x0,0x0,0x0,0x0,0x0,0x0,0x0,0x0,0x0,0x0,0x0,0x0,0x0,0x0,0x0,0x0,0x0,0x0,0x0,0x0,0x0,0x0,0x0,0x0,0x0,0x0,0x0,0x0,0x0,0x0,0x0,0x0,0x0,0x0,0x0,0x0,0x0,0x0,0x0,0x0,0x0,0x0,0x0,0x0,0x0,0x0,0x0,0x0,0x0,0x0,0x0,0x0,0x0,0x0,0x0,0x0,0x0,0x0,0x0,0x0,0x0,0x0,0x0,0x0,0x0,0x0,0x0,0x0,0x0,0x0,0x0,0x0,0x0,0x0,0x0,0x0,0x0,0x0,0x0,0x0,0x0,0x0,0x0,0x0,0x0,0x0,0x0,0x0,0x0,0x0,0x0,0x0,0x0,0x0,0x0,0x0,0x0,0x0,0x0,0x0,0x0,0x0,0x0,0x0,0x0,0x0,0x0,0x0,0x0,0x0,0x0,0x0,0x0,0x0,0x0,0x0,0x0,0x0,0x0,0x0,0x0,0x0,0x0,0x0,0x0,0x0,0x0,0x0,0x0,0x0,0x0,0x0,0x0,0x0,0x0,0x0,0x0,0x0,0x0,0x0,0x0,0x0,0x0,0x0,0x0,0x0,0x0,0x0,0x0,0x0,0x0,0x0,0x0,0x0,0x0,0x0,0x0,0x0,0x0,0x0,0x0,0x0,0x0,0x0,0x0,0x0,0x0,0x0,0x0,0x0,0x0,0x0,0x0,0x0,0x0,0x0,0x0,0x0,0x0,0x0,0x0,0x0,0x0,0x0,0x0,0x0,0x0,0x0,0x0,0x0,0x0,0x0,0x0,0x0,0x0,0x0,0x0,0x0,0x0,0x0,0x0,0x0,0x0,0x0,0x0,0x0,0x0,0x0,0x0,0x0,0x0,0x0,0x0,0x0,0x0,0x0,0x0,0x0,0x0,0x0,0x0,0x0,0x0,0x0,0x0,0x0,0x0,0x0,0x0,0x0,0x0,0x0,0x0,0x0,0x0,0x0,0x0,0x0,0x0,0x0,0x0,0x0,0x0,0x0,0x0,0x0,0x0,0x0,0x0,0x0,0x0,0x0,0x0,0x0,0x0,0x0,0x0,0x0,0x0,0x0,0x0,0x0,0x0,0x0,0x0,0x0,0x0,0x0,0x0,0x0,0x0,0x0,0x0,0x0,0x0,0x0,0x0,0x0,0x0,0x0,0x0,0x0,0x0,0x0,0x0,0x0,0x0,0x0,0x0,0x0,0x0,0x0,0x0,0x0,0x0,0x0,0x0,0x0,0x0,0x0,0x0,0x0,0x0,0x0,0x0,0x0,0x0,0x0,0x0,0x0,0x0,0x0,0x0,0x0,0x0,0x0,0x0,0x0,0x0,0x0,0x0,0x0,0x0,0x0,0x0,0x0,0x0,0x0,0x0,0x0,0x0,0x0,0x0,0x0,0x0,0x0,0x0,0x0,0x0,0x0,0x0,0x0,0x0,0x0,0x0,0x0,0x0,0x0,0x0,0x0,0x0,0x0,0x0,0x0,0x0,0x0,0x0,0x0,0x0,0x0,0x0,0x0,0x0,0x0,0x0,0x0,0x0,0x0,0x0,0x0,0x0,0x0,0x0,0x0,0x0,0x0,0x0,0x0,0x0,0x0,0x0,0x0,0x0,0x0,0x0,0x0,0x0,0x0,0x0,0x0,0x0,0x0,0x0,0x0,0x0,0x0,0x0,0x0,0x0,0x0,0x0,0x0,0x0,0x0,0x0,0x0,0x0,0x0,0x0,0x0,0x0,0x0,0x0,0x0,0x0,0x0,0x0,0x0,0x0,0x0,0x0,0x0,0x0,0x0,0x0,0x0,0x0,0x0,0x0,0x0,0x0,0x0,0x0,0x0,0x0,0x0,0x0,0x0,0x0,0x0,0x0,0x0,0x0,0x0,0x0,0x0,0x0,0x0,0x0,0x0,0x0,0x0,0x0,0x0,0x0,0x0,0x0,0x0,0x0,0x0,0x0,0x0,0x0,0x0,0x0,0x0,0x0,0x0,0x0,0x0,0x0,0x0,0x0,0x0,0x0,0x0,0x0,0x0,0x0,0x0,0x0,0x0,0x0,0x0,0x0,0x0,0x0,0x0,0x0,0x0,0x0,0x0,0x0,0x0,0x0,0x0,0x0,0x0,0x0,0x0,0x0,0x0,0x0,0x0,0x0,0x0,0x0,0x0,0x0,0x0,0x0,0x0,0x0,0x0,0x0,0x0,0x0,0x0,0x0,0x0,0x0,0x0,0x0,0x0,0x0,0x0,0x0,0x0,0x0,0x0,0x0,0x0,0x0,0x0,0x0,0x0,0x0,0x0,0x0,0x0,0x0,0x0,0x0,0x0,0x0,0x0,0x0,0x0,0x0,0x0,0x0,0x0,0x0,0x0,0x0,0x0,0x0,0x0,0x0,0x0,0x0,0x0,0x0,0x0,0x0,0x0,0x0,0x0,0x0,0x0,0x0,0x0,0x0,0x0,0x0,0x0,0x0,0x0,0x0,0x0,0x0,0x0,0x0,0x0,0x0,0x0,0x0,0x0,0x0,0x0,0x0,0x0,0x0,0x0,0x0,0x0,0x0,0x0,0x0,0x0,0x0,0x0,0x0,0x0,0x0,0x0,0x0,0x0,0x0,0x0,0x0,0x0,0x0,0x0,0x0,0x0,0x0,0x0,0x0,0x0,0x0,0x0,0x0,0x0,0x0,0x0,0x0,0x0,0x0,0x0,0x0,0x0,0x0,0x0,0x0,0x0,0x0,0x0,0x0,0x0,0x0,0x0,0x0,0x0,0x0,0x0,0x0,0x0,0x0,0x0,0x0,0x0,0x0,0x0,0x0,0x0,0x0,0x0,0x0,0x0,0x0,0x0,0x0,0x0,0x0,0x0,0x0,0x0,0x0,0x0,0x0,0x0,0x0,0x0,0x0,0x0,0x0,0x0,0x0,0x0,0x0,0x0,0x0,0x0,0x0,0x0,0x0,0x0,0x0,0x0,0x0,0x0,0x0,0x0,0x0,0x0,0x0,0x0,0x0,0x0,0x0,0x0,0x0,0x0,0x0,0x0,0x0,0x0,0x0,0x0,0x0,0x0,0x0,0x0,0x0,0x0,0x0,0x0,0x0,0x0,0x0,0x0,0x0,0x0,0x0,0x0,0x0,0x0,0x0,0x0,0x0,0x0,0x0,0x0,0x0,0x0,0x0,0x0,0x0,0x0,0x0,0x0,0x0,0x0,0x0,0x0,0x0,0x0,0x0,0x0,0x0,0x0,0x0,0x0,0x0,0x0,0x0,0x0,0x0,0x0,0x0,0x0,0x0,0x0,0x0,0x0,0x0,0x0,0x0,0x0,0x0,0x0,0x0,0x0,0x0,0x0,0x0,0x0,0x0,0x0,0x0,0x0,0x0,0x0,0x0,0x0,0x0,0x0,0x0,0x0,0x0,0x0,0x0,0x0,0x0,0x0,0x0,0x0,0x0,0x0,0x0,0x0,0x0,0x0,0x0,0x0,0x0,0x0,0x0,0x0,0x0,0x0,0x0,0x0,0x0,0x0,0x0,0x0,0x0,0x0,0x0,0x0,0x0,0x0,0x0,0x0,0x0,0x0,0x0,0x0,0x0,0x0,0x0,0x0,0x0,0x0,0x0,0x0,0x0,0x0,0x0,0x0,0x0,0x0,0x0,0x0,0x0,0x0,0x0,0x0,0x0,0x0,0x0,0x0,0x0,0x0,0x0,0x0,0x0,0x0,0x0,0x0,0x0,0x0,0x0,0x0,0x0,0x0,0x0,0x0,0x0,0x0,0x0,0x0,0x0,0x0,0x0,0x0,0x0,0x0,0x0,0x0,0x0,0x0,0x0,0x0,0x0,0x0,0x0,0x0,0x0,0x0,0x0,0x0,0x0,0x0,0x0,0x0,0x0,0x0,0x0,0x0,0x0,0x0,0x0,0x0,0x0,0x0,0x0,0x0,0x0,0x0,0x0,0x0,0x0,0x0,0x0,0x0,0x0,0x0,0x0,0x0,0x0,0x0,0x0,0x0,0x0,0x0,0x0,0x0,0x0,0x0,0x0,0x0,0x0,0x0,0x0,0x0,0x0,0x0,0x0,0x0,0x0,0x0,0x0,0x0,0x0,0x0,0x0,0x0,0x0,0x0,0x0,0x0,0x0,0x0,0x0,0x0,0x0,0x0,0x0,0x0,0x0,0x0,0x0,0x0,0x0,0x0,0x0,0x0,0x0,0x0,0x0,0x0,0x0,0x0,0x0,0x0,0x0,0x0,0x0,0x0,0x0,0x0,0x0,0x0,0x0,0x0,0x0,0x0,0x0,0x0,0x0,0x0,0x0,0x0,0x0,0x0,0x0,0x0,0x0,0x0,0x0,0x0,0x0,0x0,0x0,0x0,0x0,0x0,0x0,0x0,0x0,0x0,0x0,0x0,0x0,0x0,0x0,0x0,0x0,0x0,0x0,0x0,0x0,0x0,0x0,0x0,0x0,0x0,0x0,0x0,0x0,0x0,0x0,0x0,0x0,0x0,0x0,0x0,0x0,0x0,0x0,0x0,0x0,0x0,0x0,0x0,0x0,0x0,0x0,0x0,0x0,0x0,0x0,0x0,0x0,0x0,0x0,0x0,0x0,0x0,0x0,0x0,0x0,0x0,0x0,0x0,0x0,0x0,0x0,0x0,0x0,0x0,0x0,0x0,0x0,0x0,0x0,0x0,0x0,0x0,0x0,0x0,0x0,0x0,0x0,0x0,0x0,0x0,0x0,0x0,0x0,0x0,0x0,0x0,0x0,0x0,0x0,0x0,0x0,0x0,0x0,0x0,0x0,0x0,0x0,0x0,0x0,0x0,0x0,0x0,0x0,0x0,0x0,0x0,0x0,0x0,0x0,0x0,0x0,0x0,0x0,0x0,0x0,0x0,0x0,0x0,0x0,0x0,0x0,0x0,0x0,0x0,0x0,0x0,0x0,0x0,0x0,0x0,0x0,0x0,0x0,0x0,0x0,0x0,0x0,0x0,0x0,0x0,0x0,0x0,0x0,0x0,0x0,0x0,0x0,0x0,0x0,0x0,0x0,0x0,0x0,0x0,0x0,0x0,0x0,0x0,0x0,0x0,0x0,0x0,0x0,0x0,0x0,0x0,0x0,0x0,0x0,0x0,0x0,0x0,0x0,0x0,0x0,0x0,0x0,0x0,0x0,0x0,0x0,0x0,0x0,0x0,0x0,0x0,0x0,0x0,0x0,0x0,0x0,0x0,0x0,0x0,0x0,0x0,0x0,0x0,0x0,0x0,0x0,0x0,0x0,0x0,0x0,0x0,0x0,0x0,0x0,0x0,0x0,0x0,0x0,0x0,0x0,0x0,0x0,0x0,0x0,0x0,0x0,0x0,0x0,0x0,0x0,0x0,0x0,0x0,0x0,0x0,0x0,0x0,0x0,0x0,0x0,0x0,0x0,0x0,0x0,0x0,0x0,0x0,0x0,0x0,0x0,0x0,0x0,0x0,0x0,0x0,0x0,0x0,0x0,0x0,0x0,0x0,0x0,0x0,0x0,0x0,0x0,0x0,0x0,0x0,0x0,0x0,0x0,0x0,0x0,0x0,0x0,0x0,0x0,0x0,0x0,0x0,0x0,0x0,0x0,0x0,0x0,0x0,0x0,0x0,0x0,0x0,0x0,0x0,0x0,0x0,0x0,0x0,0x0,0x0,0x0,0x0,0x0,0x0,0x0,0x0,0x0,0x0,0x0,0x0,0x0,0x0,0x0,0x0,0x0,0x0,0x0,0x0,0x0,0x0,0x0,0x0,0x0,0x0,0x0,0x0,0x0,0x0,0x0,0x0,0x0,0x0,0x0,0x0,0x0,0x0,0x0,0x0,0x0,0x0,0x0,0x0,0x0,0x0,0x0,0x0,0x0,0x0,0x0,0x0,0x0,0x0,0x0,0x0,0x0,0x0,0x0,0x0,0x0,0x0,0x0,0x0,0x0,0x0,0x0,0x0,0x0,0x0,0x0,0x0,0x0,0x0,0x0,0x0,0x0,0x0,0x0,0x0,0x0,0x0,0x0,0x0,0x0,0x0,0x0,0x0,0x0,0x0,0x0,0x0,0x0,0x0,0x0,0x0,0x0,0x0,0x0,0x0,0x0,0x0,0x0,0x0,0x0,0x0,0x0,0x0,0x0,0x0,0x0,0x0,0x0,0x0,0x0,0x0,0x0,0x0,0x0,0x0,0x0,0x0,0x0,0x0,0x0,0x0,0x0,0x0,0x0,0x0,0x0,0x0,0x0,0x0,0x0,0x0,0x0,0x0,0x0,0x0,0x0,0x0,0x0,0x0,0x0,0x0,0x0,0x0,0x0,0x0,0x0,0x0,0x0,0x0,0x0,0x0,0x0,0x0,0x0,0x0,0x0,0x0,0x0,0x0,0x0,0x0,0x0,0x0,0x0,0x0,0x0,0x0,0x0,0x0,0x0,0x0,0x0,0x0,0x0,0x0,0x0,0x0,0x0,0x0,0x0,0x0,0x0,0x0,0x0,0x0,0x0,0x0,0x0,0x0,0x0,0x0,0x0,0x0,0x0,0x0,0x0,0x0,0x0,0x0,0x0,0x0,0x0,0x0,0x0,0x0,0x0,0x0,0x0,0x0,0x0,0x0,0x0,0x0,0x0,0x0,0x0,0x0,0x0,0x0,0x0,0x0,0x0,0x0,0x0,0x0,0x0,0x0,0x0,0x0,0x0,0x0,0x0,0x0,0x0,0x0,0x0,0x0,0x0,0x0,0x0,0x0,0x0,0x0,0x0,0x0,0x0,0x0,0x0,0x0,0x0,0x0,0x0,0x0,0x0,0x0,0x0,0x0,0x0,0x0,0x0,0x0,0x0,0x0,0x0,0x0,0x0,0x0,0x0,0x0,0x0,0x0,0x0,0x0,0x0,0x0,0x0,0x0,0x0,0x0,0x0,0x0,0x0,0x0,0x0,0x0,0x0,0x0,0x0,0x0,0x0,0x0,0x0,0x0,0x0,0x0,0x0,0x0,0x0,0x0,0x0,0x0,0x0,0x0,0x0,0x0,0x0,0x0,0x0,0x0,0x0,0x0,0x0,0x0,0x0,0x0,0x0,0x0,0x0,0x0,0x0,0x0,0x0,0x0,0x0,0x0,0x0,0x0,0x0,0x0,0x0,0x0,0x0,0x0,0x0,0x0,0x0,0x0,0x0,0x0,0x0,0x0,0x0,0x0,0x0,0x0,0x0,0x0,0x0,0x0,0x0,0x0,0x0,0x0,0x0,0x0,0x0,0x0,0x0,0x0,0x0,0x0,0x0,0x0,0x0,0x0,0x0,0x0,0x0,0x0,0x0,0x0,0x0,0x0,0x0,0x0,0x0,0x0,0x0,0x0,0x0,0x0,0x0,0x0,0x0,0x0,0x0,0x0,0x0,0x0,0x0,0x0,0x0,0x0,0x0,0x0,0x0,0x0,0x0,0x0,0x0,0x0,0x0,0x0,0x0,0x0,0x0,0x0,0x0,0x0,0x0,0x0,0x0,0x0,0x0,0x0,0x0,0x0,0x0,0x0,0x0,0x0,0x0,0x0,0x0,0x0,0x0,0x0,0x0,0x0,0x0,0x0,0x0,0x0,0x0,0x0,0x0,0x0,0x0,0x0,0x0,0x0,0x0,0x0,0x0,0x0,0x0,0x0,0x0,0x0,0x0,0x0,0x0,0x0,0x0,0x0,0x0,0x0,0x0,0x0,0x0,0x0,0x0,0x0,0x0,0x0,0x0,0x0,0x0,0x0,0x0,0x0,0x0,0x0,0x0,0x0,0x0,0x0,0x0,0x0,0x0,0x0,0x0,0x0,0x0,0x0,0x0,0x0,0x0,0x0,0x0,0x0,0x0,0x0,0x0,0x0,0x0,0x0,0x0,0x0,0x0,0x0,0x0,0x0,0x0,0x0,0x0,0x0,0x0,0x0,0x0,0x0,0x0,0x0,0x0,0x0,0x0,0x0,0x0,0x0,0x0,0x0,0x0,0x0,0x0,0x0,0x0,0x0,0x0,0x0,0x0,0x0,0x0,0x0,0x0,0x0,0x0,0x0,0x0,0x0,0x0,0x0,0x0,0x0,0x0,0x0,0x0,0x0,0x0,0x0,0x0,0x0,0x0,0x0,0x0,0x0,0x0,0x0,0x0,0x0,0x0,0x0,0x0,0x0,0x0,0x0,0x0,0x0,0x0,0x0,0x0,0x0,0x0,0x0,0x0,0x0,0x0,0x0,0x0,0x0,0x0,0x0,0x0,0x0,0x0,0x0,0x0,0x0,0x0,0x0,0x0,0x0,0x0,0x0,0x0,0x0,0x0,0x0,0x0,0x0,0x0,0x0,0x0,0x0,0x0,0x0,0x0,0x0,0x0,0x0,0x0,0x0,0x0,0x0,0x0,0x0,0x0,0x0,0x0,0x0,0x0,0x0,0x0,0x0,0x0,0x0,0x0,]

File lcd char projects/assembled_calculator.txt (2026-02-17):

[0x0,0xf,0x28,0xe3,0xfe,0x0,0xff,0x28,0xe2,0xfe,0x0,0xff,0x28,0xf2,0xfe,0x28,0xf3,0xfe,0x0,0x38,0x28,0xf1,0xfe,0x0,0x2,0x28,0xf0,0xfe,0x0,0x0,0x28,0xf0,0xfe,0x0,0xf,0x28,0xf1,0xfe,0x0,0x2,0x28,0xf0,0xfe,0x0,0x0,0x28,0xf0,0xfe,0x0,0x6,0x28,0xf1,0xfe,0x0,0x2,0x28,0xf0,0xfe,0x0,0x0,0x28,0xf0,0xfe,0x0,0x0,0x28,0xfd,0x0,0x28,0xfd,0x0,0x28,0xfd,0x0,0x28,0xfd,0x0,0x36,0x74,0x0,0x36,0x93,0x0,0x36,0xbd,0x0,0x2f,0x11,0xe0,0xfe,0x2e,0x28,0xe0,0xfe,0x3c,0x71,0x0,0x2f,0x10,0x10,0x2e,0x3c,0x71,0x0,0xc,0x30,0x31,0x2f,0x36,0xac,0x0,0x2e,0x30,0x3b,0x4d,0x0,0x31,0x33,0x0,0x1,0xb,0x28,0xe1,0xfe,0x11,0xe1,0xfe,0x3d,0x8d,0x0,0xa,0x10,0x8,0x3c,0x8d,0x0,0xa,0x25,0x3b,0x78,0x0,0x1,0xe1,0xfe,0x30,0x30,0x37,0x31,0x33,0x4,0x0,0x2f,0x13,0xbd,0x0,0x2e,0x3c,0xa8,0x0,0x2f,0x8,0xa,0x10,0x10,0x2e,0x3d,0x97,0x0,0xa,0x32,0x30,0x37,0x4,0x3,0x34,0x28,0xf1,0xfe,0x0,0x3,0x28,0xf0,0xfe,0x0,0x0,0x28,0xf0,0xfe,0x37,40,17,33,65,18,34,66,20,36,68,129,130,132,136,24,72,0x31,0x33,0x2f,0x10,0xa,0xb,0x2e,0x3e,0xca,0x0,0x3,0xcd,0x0,0x32,0x30,0x37,43,45,42,47,61,46,0x2f,0x31,0x33,0x1,0xfd,0x0,0xd,0xfd,0x0,0x28,0xfd,0x0,0x1,0xfd,0x0,0x15,0xfd,0x0,0x28,0xfd,0x0,0x32,0x30,0x2e,0x2f,0x31,0x33,0x1,0xfd,0x0,0x11,0xfd,0x0,0x28,0xfd,0x0,0x1,0xfd,0x0,0x19,0xfd,0x0,0x28,0xfd,0x0,0x32,0x30,0x2e,0x0,0x0,0x0,0x0,0x0,0x0,0x0,0x0,0x0,0x0,0x0,0x0,0x0,0x0,0x0,0x0,0x0,0x0,0x0,0x0,0x0,0x0,0x0,0x0,0x0,0x0,0x0,0x0,0x0,0x0,0x0,0x0,0x0,0x0,0x0,0x0,0x0,0x0,0x0,0x0,0x0,0x0,0x0,0x0,0x0,0x0,0x0,0x0,0x0,0x0,0x0,0x0,0x0,0x0,0x0,0x0,0x0,0x0,0x0,0x0,0x0,0x0,0x0,0x0,0x0,0x0,0x0,0x0,0x0,0x0,0x0,0x0,0x0,0x0,0x0,0x0,0x0,0x0,0x0,0x0,0x0,0x0,0x0,0x0,0x0,0x0,0x0,0x0,0x0,0x0,0x0,0x0,0x0,0x0,0x0,0x0,0x0,0x0,0x0,0x0,0x0,0x0,0x0,0x0,0x0,0x0,0x0,0x0,0x0,0x0,0x0,0x0,0x0,0x0,0x0,0x0,0x0,0x0,0x0,0x0,0x0,0x0,0x0,0x0,0x0,0x0,0x0,0x0,0x0,0x0,0x0,0x0,0x0,0x0,0x0,0x0,0x0,0x0,0x0,0x0,0x0,0x0,0x0,0x0,0x0,0x0,0x0,0x0,0x0,0x0,0x0,0x0,0x0,0x0,0x0,0x0,0x0,0x0,0x0,0x0,0x0,0x0,0x0,0x0,0x0,0x0,0x0,0x0,0x0,0x0,0x0,0x0,0x0,0x0,0x0,0x0,0x0,0x0,0x0,0x0,0x0,0x0,0x0,0x0,0x0,0x0,0x0,0x0,0x0,0x0,0x0,0x0,0x0,0x0,0x0,0x0,0x0,0x0,0x0,0x0,0x0,0x0,0x0,0x0,0x0,0x0,0x0,0x0,0x0,0x0,0x0,0x0,0x0,0x0,0x0,0x0,0x0,0x0,0x0,0x0,0x0,0x0,0x0,0x0,0x0,0x0,0x0,0x0,0x0,0x0,0x0,0x0,0x0,0x0,0x0,0x0,0x0,0x0,0x0,0x0,0x0,0x0,0x0,0x0,0x0,0x0,0x0,0x0,0x0,0x0,0x0,0x0,0x0,0x0,0x0,0x0,0x0,0x0,0x0,0x0,0x0,0x0,0x0,0x0,0x0,0x0,0x0,0x0,0x0,0x0,0x0,0x0,0x0,0x0,0x0,0x0,0x0,0x0,0x0,0x0,0x0,0x0,0x0,0x0,0x0,0x0,0x0,0x0,0x0,0x0,0x0,0x0,0x0,0x0,0x0,0x0,0x0,0x0,0x0,0x0,0x0,0x0,0x0,0x0,0x0,0x0,0x0,0x0,0x0,0x0,0x0,0x0,0x0,0x0,0x0,0x0,0x0,0x0,0x0,0x0,0x0,0x0,0x0,0x0,0x0,0x0,0x0,0x0,0x0,0x0,0x0,0x0,0x0,0x0,0x0,0x0,0x0,0x0,0x0,0x0,0x0,0x0,0x0,0x0,0x0,0x0,0x0,0x0,0x0,0x0,0x0,0x0,0x0,0x0,0x0,0x0,0x0,0x0,0x0,0x0,0x0,0x0,0x0,0x0,0x0,0x0,0x0,0x0,0x0,0x0,0x0,0x0,0x0,0x0,0x0,0x0,0x0,0x0,0x0,0x0,0x0,0x0,0x0,0x0,0x0,0x0,0x0,0x0,0x0,0x0,0x0,0x0,0x0,0x0,0x0,0x0,0x0,0x0,0x0,0x0,0x0,0x0,0x0,0x0,0x0,0x0,0x0,0x0,0x0,0x0,0x0,0x0,0x0,0x0,0x0,0x0,0x0,0x0,0x0,0x0,0x0,0x0,0x0,0x0,0x0,0x0,0x0,0x0,0x0,0x0,0x0,0x0,0x0,0x0,0x0,0x0,0x0,0x0,0x0,0x0,0x0,0x0,0x0,0x0,0x0,0x0,0x0,0x0,0x0,0x0,0x0,0x0,0x0,0x0,0x0,0x0,0x0,0x0,0x0,0x0,0x0,0x0,0x0,0x0,0x0,0x0,0x0,0x0,0x0,0x0,0x0,0x0,0x0,0x0,0x0,0x0,0x0,0x0,0x0,0x0,0x0,0x0,0x0,0x0,0x0,0x0,0x0,0x0,0x0,0x0,0x0,0x0,0x0,0x0,0x0,0x0,0x0,0x0,0x0,0x0,0x0,0x0,0x0,0x0,0x0,0x0,0x0,0x0,0x0,0x0,0x0,0x0,0x0,0x0,0x0,0x0,0x0,0x0,0x0,0x0,0x0,0x0,0x0,0x0,0x0,0x0,0x0,0x0,0x0,0x0,0x0,0x0,0x0,0x0,0x0,0x0,0x0,0x0,0x0,0x0,0x0,0x0,0x0,0x0,0x0,0x0,0x0,0x0,0x0,0x0,0x0,0x0,0x0,0x0,0x0,0x0,0x0,0x0,0x0,0x0,0x0,0x0,0x0,0x0,0x0,0x0,0x0,0x0,0x0,0x0,0x0,0x0,0x0,0x0,0x0,0x0,0x0,0x0,0x0,0x0,0x0,0x0,0x0,0x0,0x0,0x0,0x0,0x0,0x0,0x0,0x0,0x0,0x0,0x0,0x0,0x0,0x0,0x0,0x0,0x0,0x0,0x0,0x0,0x0,0x0,0x0,0x0,0x0,0x0,0x0,0x0,0x0,0x0,0x0,0x0,0x0,0x0,0x0,0x0,0x0,0x0,0x0,0x0,0x0,0x0,0x0,0x0,0x0,0x0,0x0,0x0,0x0,0x0,0x0,0x0,0x0,0x0,0x0,0x0,0x0,0x0,0x0,0x0,0x0,0x0,0x0,0x0,0x0,0x0,0x0,0x0,0x0,0x0,0x0,0x0,0x0,0x0,0x0,0x0,0x0,0x0,0x0,0x0,0x0,0x0,0x0,0x0,0x0,0x0,0x0,0x0,0x0,0x0,0x0,0x0,0x0,0x0,0x0,0x0,0x0,0x0,0x0,0x0,0x0,0x0,0x0,0x0,0x0,0x0,0x0,0x0,0x0,0x0,0x0,0x0,0x0,0x0,0x0,0x0,0x0,0x0,0x0,0x0,0x0,0x0,0x0,0x0,0x0,0x0,0x0,0x0,0x0,0x0,0x0,0x0,0x0,0x0,0x0,0x0,0x0,0x0,0x0,0x0,0x0,0x0,0x0,0x0,0x0,0x0,0x0,0x0,0x0,0x0,0x0,0x0,0x0,0x0,0x0,0x0,0x0,0x0,0x0,0x0,0x0,0x0,0x0,0x0,0x0,0x0,0x0,0x0,0x0,0x0,0x0,0x0,0x0,0x0,0x0,0x0,0x0,0x0,0x0,0x0,0x0,0x0,0x0,0x0,0x0,0x0,0x0,0x0,0x0,0x0,0x0,0x0,0x0,0x0,0x0,0x0,0x0,0x0,0x0,0x0,0x0,0x0,0x0,0x0,0x0,0x0,0x0,0x0,0x0,0x0,0x0,0x0,0x0,0x0,0x0,0x0,0x0,0x0,0x0,0x0,0x0,0x0,0x0,0x0,0x0,0x0,0x0,0x0,0x0,0x0,0x0,0x0,0x0,0x0,0x0,0x0,0x0,0x0,0x0,0x0,0x0,0x0,0x0,0x0,0x0,0x0,0x0,0x0,0x0,0x0,0x0,0x0,0x0,0x0,0x0,0x0,0x0,0x0,0x0,0x0,0x0,0x0,0x0,0x0,0x0,0x0,0x0,0x0,0x0,0x0,0x0,0x0,0x0,0x0,0x0,0x0,0x0,0x0,0x0,0x0,0x0,0x0,0x0,0x0,0x0,0x0,0x0,0x0,0x0,0x0,0x0,0x0,0x0,0x0,0x0,0x0,0x0,0x0,0x0,0x0,0x0,0x0,0x0,0x0,0x0,0x0,0x0,0x0,0x0,0x0,0x0,0x0,0x0,0x0,0x0,0x0,0x0,0x0,0x0,0x0,0x0,0x0,0x0,0x0,0x0,0x0,0x0,0x0,0x0,0x0,0x0,0x0,0x0,0x0,0x0,0x0,0x0,0x0,0x0,0x0,0x0,0x0,0x0,0x0,0x0,0x0,0x0,0x0,0x0,0x0,0x0,0x0,0x0,0x0,0x0,0x0,0x0,0x0,0x0,0x0,0x0,0x0,0x0,0x0,0x0,0x0,0x0,0x0,0x0,0x0,0x0,0x0,0x0,0x0,0x0,0x0,0x0,0x0,0x0,0x0,0x0,0x0,0x0,0x0,0x0,0x0,0x0,0x0,0x0,0x0,0x0,0x0,0x0,0x0,0x0,0x0,0x0,0x0,0x0,0x0,0x0,0x0,0x0,0x0,0x0,0x0,0x0,0x0,0x0,0x0,0x0,0x0,0x0,0x0,0x0,0x0,0x0,0x0,0x0,0x0,0x0,0x0,0x0,0x0,0x0,0x0,0x0,0x0,0x0,0x0,0x0,0x0,0x0,0x0,0x0,0x0,0x0,0x0,0x0,0x0,0x0,0x0,0x0,0x0,0x0,0x0,0x0,0x0,0x0,0x0,0x0,0x0,0x0,0x0,0x0,0x0,0x0,0x0,0x0,0x0,0x0,0x0,0x0,0x0,0x0,0x0,0x0,0x0,0x0,0x0,0x0,0x0,0x0,0x0,0x0,0x0,0x0,0x0,0x0,0x0,0x0,0x0,0x0,0x0,0x0,0x0,0x0,0x0,0x0,0x0,0x0,0x0,0x0,0x0,0x0,0x0,0x0,0x0,0x0,0x0,0x0,0x0,0x0,0x0,0x0,0x0,0x0,0x0,0x0,0x0,0x0,0x0,0x0,0x0,0x0,0x0,0x0,0x0,0x0,0x0,0x0,0x0,0x0,0x0,0x0,0x0,0x0,0x0,0x0,0x0,0x0,0x0,0x0,0x0,0x0,0x0,0x0,0x0,0x0,0x0,0x0,0x0,0x0,0x0,0x0,0x0,0x0,0x0,0x0,0x0,0x0,0x0,0x0,0x0,0x0,0x0,0x0,0x0,0x0,0x0,0x0,0x0,0x0,0x0,0x0,0x0,0x0,0x0,0x0,0x0,0x0,0x0,0x0,0x0,0x0,0x0,0x0,0x0,0x0,0x0,0x0,0x0,0x0,0x0,0x0,0x0,0x0,0x0,0x0,0x0,0x0,0x0,0x0,0x0,0x0,0x0,0x0,0x0,0x0,0x0,0x0,0x0,0x0,0x0,0x0,0x0,0x0,0x0,0x0,0x0,0x0,0x0,0x0,0x0,0x0,0x0,0x0,0x0,0x0,0x0,0x0,0x0,0x0,0x0,0x0,0x0,0x0,0x0,0x0,0x0,0x0,0x0,0x0,0x0,0x0,0x0,0x0,0x0,0x0,0x0,0x0,0x0,0x0,0x0,0x0,0x0,0x0,0x0,0x0,0x0,0x0,0x0,0x0,0x0,0x0,0x0,0x0,0x0,0x0,0x0,0x0,0x0,0x0,0x0,0x0,0x0,0x0,0x0,0x0,0x0,0x0,0x0,0x0,0x0,0x0,0x0,0x0,0x0,0x0,0x0,0x0,0x0,0x0,0x0,0x0,0x0,0x0,0x0,0x0,0x0,0x0,0x0,0x0,0x0,0x0,0x0,0x0,0x0,0x0,0x0,0x0,0x0,0x0,0x0,0x0,0x0,0x0,0x0,0x0,0x0,0x0,0x0,0x0,0x0,0x0,0x0,0x0,0x0,0x0,0x0,0x0,0x0,0x0,0x0,0x0,0x0,0x0,0x0,0x0,0x0,0x0,0x0,0x0,0x0,0x0,0x0,0x0,0x0,0x0,0x0,0x0,0x0,0x0,0x0,0x0,0x0,0x0,0x0,0x0,0x0,0x0,0x0,0x0,0x0,0x0,0x0,0x0,0x0,0x0,0x0,0x0,0x0,0x0,0x0,0x0,0x0,0x0,0x0,0x0,0x0,0x0,0x0,0x0,0x0,0x0,0x0,0x0,0x0,0x0,0x0,0x0,0x0,0x0,0x0,0x0,0x0,0x0,0x0,0x0,0x0,0x0,0x0,0x0,0x0,0x0,0x0,0x0,0x0,0x0,0x0,0x0,0x0,0x0,0x0,0x0,0x0,0x0,0x0,0x0,0x0,0x0,0x0,0x0,0x0,0x0,0x0,0x0,0x0,0x0,0x0,0x0,0x0,0x0,0x0,0x0,0x0,0x0,0x0,0x0,0x0,0x0,0x0,0x0,0x0,0x0,0x0,0x0,0x0,0x0,0x0,0x0,0x0,0x0,0x0,0x0,0x0,0x0,0x0,0x0,0x0,0x0,0x0,0x0,0x0,0x0,0x0,0x0,0x0,0x0,0x0,0x0,0x0,0x0,0x0,0x0,0x0,0x0,0x0,0x0,0x0,0x0,0x0,0x0,0x0,0x0,0x0,0x0,0x0,0x0,0x0,0x0,0x0,0x0,0x0,0x0,0x0,0x0,0x0,0x0,0x0,0x0,0x0,0x0,0x0,0x0,0x0,0x0,0x0,0x0,0x0,0x0,0x0,0x0,0x0,0x0,0x0,0x0,0x0,0x0,0x0,0x0,0x0,0x0,0x0,0x0,0x0,0x0,0x0,0x0,0x0,0x0,0x0,0x0,0x0,0x0,0x0,0x0,0x0,0x0,0x0,0x0,0x0,0x0,0x0,0x0,0x0,0x0,0x0,0x0,0x0,0x0,0x0,0x0,0x0,0x0,0x0,0x0,0x0,0x0,0x0,0x0,0x0,0x0,0x0,0x0,0x0,0x0,0x0,0x0,0x0,0x0,0x0,0x0,0x0,0x0,0x0,0x0,0x0,0x0,0x0,0x0,0x0,0x0,0x0,0x0,0x0,0x0,0x0,0x0,0x0,0x0,0x0,0x0,0x0,0x0,0x0,0x0,0x0,0x0,0x0,0x0,0x0,0x0,0x0,0x0,0x0,0x0,0x0,0x0,0x0,0x0,0x0,0x0,0x0,0x0,0x0,0x0,0x0,0x0,0x0,0x0,0x0,0x0,0x0,0x0,0x0,0x0,0x0,0x0,0x0,0x0,0x0,0x0,0x0,0x0,0x0,0x0,0x0,0x0,0x0,0x0,0x0,0x0,0x0,0x0,0x0,0x0,0x0,0x0,0x0,0x0,0x0,0x0,0x0,0x0,0x0,0x0,0x0,0x0,0x0,0x0,0x0,0x0,0x0,0x0,0x0,0x0,0x0,0x0,0x0,0x0,0x0,0x0,0x0,0x0,0x0,0x0,0x0,0x0,0x0,0x0,0x0,0x0,0x0,0x0,0x0,0x0,0x0,0x0,0x0,0x0,0x0,0x0,0x0,0x0,0x0,0x0,0x0,0x0,0x0,0x0,0x0,0x0,0x0,0x0,0x0,0x0,0x0,0x0,0x0,0x0,0x0,0x0,0x0,0x0,0x0,0x0,0x0,0x0,0x0,0x0,0x0,0x0,0x0,0x0,0x0,0x0,0x0,0x0,0x0,0x0,0x0,0x0,0x0,0x0,0x0,0x0,0x0,0x0,0x0,0x0,0x0,0x0,0x0,0x0,0x0,0x0,0x0,0x0,0x0,0x0,0x0,0x0,0x0,0x0,0x0,0x0,0x0,0x0,0x0,0x0,0x0,0x0,0x0,0x0,0x0,0x0,0x0,0x0,0x0,0x0,0x0,0x0,0x0,0x0,0x0,0x0,0x0,0x0,0x0,0x0,0x0,0x0,0x0,0x0,0x0,0x0,0x0,0x0,0x0,0x0,0x0,0x0,0x0,0x0,0x0,0x0,0x0,0x0,0x0,]

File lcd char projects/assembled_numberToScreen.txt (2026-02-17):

[0x0,0xf,0x28,0xe3,0xfe,0x0,0xff,0x28,0xe2,0xfe,0x0,0xff,0x28,0xf2,0xfe,0x28,0xf3,0xfe,0x0,0x38,0x28,0xf1,0xfe,0x0,0x2,0x28,0xf0,0xfe,0x0,0x0,0x28,0xf0,0xfe,0x0,0xf,0x28,0xf1,0xfe,0x0,0x2,0x28,0xf0,0xfe,0x0,0x0,0x28,0xf0,0xfe,0x0,0x6,0x28,0xf1,0xfe,0x0,0x2,0x28,0xf0,0xfe,0x0,0x0,0x28,0xf0,0xfe,0x36,0x63,0x0,0x36,0x82,0x0,0x2f,0x11,0xe0,0xfe,0x2e,0x28,0xe0,0xfe,0x3c,0x60,0x0,0x2f,0x10,0x10,0x2e,0x3c,0x60,0x0,0xc,0x30,0x31,0x2f,0x36,0x9b,0x0,0x2e,0x30,0x3b,0x3f,0x0,0x31,0x33,0x0,0x1,0xb,0x28,0xe1,0xfe,0x11,0xe1,0xfe,0x3d,0x7c,0x0,0xa,0x10,0x8,0x3c,0x7c,0x0,0xa,0x25,0x3b,0x67,0x0,0x1,0xe1,0xfe,0x30,0x30,0x37,0x31,0x33,0x4,0x0,0x2f,0x13,0xac,0x0,0x2e,0x3c,0x97,0x0,0x2f,0x8,0xa,0x10,0x10,0x2e,0x3d,0x86,0x0,0xa,0x32,0x30,0x37,0x4,0x3,0x34,0x28,0xf1,0xfe,0x0,0x3,0x28,0xf0,0xfe,0x0,0x0,0x28,0xf0,0xfe,0x37,40,17,33,65,18,34,66,20,36,68,129,130,132,136,24,72,0x0,0x0,0x0,0x0,0x0,0x0,0x0,0x0,0x0,0x0,0x0,0x0,0x0,0x0,0x0,0x0,0x0,0x0,0x0,0x0,0x0,0x0,0x0,0x0,0x0,0x0,0x0,0x0,0x0,0x0,0x0,0x0,0x0,0x0,0x0,0x0,0x0,0x0,0x0,0x0,0x0,0x0,0x0,0x0,0x0,0x0,0x0,0x0,0x0,0x0,0x0,0x0,0x0,0x0,0x0,0x0,0x0,0x0,0x0,0x0,0x0,0x0,0x0,0x0,0x0,0x0,0x0,0x0,0x0,0x0,0x0,0x0,0x0,0x0,0x0,0x0,0x0,0x0,0x0,0x0,0x0,0x0,0x0,0x0,0x0,0x0,0x0,0x0,0x0,0x0,0x0,0x0,0x0,0x0,0x0,0x0,0x0,0x0,0x0,0x0,0x0,0x0,0x0,0x0,0x0,0x0,0x0,0x0,0x0,0x0,0x0,0x0,0x0,0x0,0x0,0x0,0x0,0x0,0x0,0x0,0x0,0x0,0x0,0x0,0x0,0x0,0x0,0x0,0x0,0x0,0x0,0x0,0x0,0x0,0x0,0x0,0x0,0x0,0x0,0x0,0x0,0x0,0x0,0x0,0x0,0x0,0x0,0x0,0x0,0x0,0x0,0x0,0x0,0x0,0x0,0x0,0x0,0x0,0x0,0x0,0x0,0x0,0x0,0x0,0x0,0x0,0x0,0x0,0x0,0x0,0x0,0x0,0x0,0x0,0x0,0x0,0x0,0x0,0x0,0x0,0x0,0x0,0x0,0x0,0x0,0x0,0x0,0x0,0x0,0x0,0x0,0x0,0x0,0x0,0x0,0x0,0x0,0x0,0x0,0x0,0x0,0x0,0x0,0x0,0x0,0x0,0x0,0x0,0x0,0x0,0x0,0x0,0x0,0x0,0x0,0x0,0x0,0x0,0x0,0x0,0x0,0x0,0x0,0x0,0x0,0x0,0x0,0x0,0x0,0x0,0x0,0x0,0x0,0x0,0x0,0x0,0x0,0x0,0x0,0x0,0x0,0x0,0x0,0x0,0x0,0x0,0x0,0x0,0x0,0x0,0x0,0x0,0x0,0x0,0x0,0x0,0x0,0x0,0x0,0x0,0x0,0x0,0x0,0x0,0x0,0x0,0x0,0x0,0x0,0x0,0x0,0x0,0x0,0x0,0x0,0x0,0x0,0x0,0x0,0x0,0x0,0x0,0x0,0x0,0x0,0x0,0x0,0x0,0x0,0x0,0x0,0x0,0x0,0x0,0x0,0x0,0x0,0x0,0x0,0x0,0x0,0x0,0x0,0x0,0x0,0x0,0x0,0x0,0x0,0x0,0x0,0x0,0x0,0x0,0x0,0x0,0x0,0x0,0x0,0x0,0x0,0x0,0x0,0x0,0x0,0x0,0x0,0x0,0x0,0x0,0x0,0x0,0x0,0x0,0x0,0x0,0x0,0x0,0x0,0x0,0x0,0x0,0x0,0x0,0x0,0x0,0x0,0x0,0x0,0x0,0x0,0x0,0x0,0x0,0x0,0x0,0x0,0x0,0x0,0x0,0x0,0x0,0x0,0x0,0x0,0x0,0x0,0x0,0x0,0x0,0x0,0x0,0x0,0x0,0x0,0x0,0x0,0x0,0x0,0x0,0x0,0x0,0x0,0x0,0x0,0x0,0x0,0x0,0x0,0x0,0x0,0x0,0x0,0x0,0x0,0x0,0x0,0x0,0x0,0x0,0x0,0x0,0x0,0x0,0x0,0x0,0x0,0x0,0x0,0x0,0x0,0x0,0x0,0x0,0x0,0x0,0x0,0x0,0x0,0x0,0x0,0x0,0x0,0x0,0x0,0x0,0x0,0x0,0x0,0x0,0x0,0x0,0x0,0x0,0x0,0x0,0x0,0x0,0x0,0x0,0x0,0x0,0x0,0x0,0x0,0x0,0x0,0x0,0x0,0x0,0x0,0x0,0x0,0x0,0x0,0x0,0x0,0x0,0x0,0x0,0x0,0x0,0x0,0x0,0x0,0x0,0x0,0x0,0x0,0x0,0x0,0x0,0x0,0x0,0x0,0x0,0x0,0x0,0x0,0x0,0x0,0x0,0x0,0x0,0x0,0x0,0x0,0x0,0x0,0x0,0x0,0x0,0x0,0x0,0x0,0x0,0x0,0x0,0x0,0x0,0x0,0x0,0x0,0x0,0x0,0x0,0x0,0x0,0x0,0x0,0x0,0x0,0x0,0x0,0x0,0x0,0x0,0x0,0x0,0x0,0x0,0x0,0x0,0x0,0x0,0x0,0x0,0x0,0x0,0x0,0x0,0x0,0x0,0x0,0x0,0x0,0x0,0x0,0x0,0x0,0x0,0x0,0x0,0x0,0x0,0x0,0x0,0x0,0x0,0x0,0x0,0x0,0x0,0x0,0x0,0x0,0x0,0x0,0x0,0x0,0x0,0x0,0x0,0x0,0x0,0x0,0x0,0x0,0x0,0x0,0x0,0x0,0x0,0x0,0x0,0x0,0x0,0x0,0x0,0x0,0x0,0x0,0x0,0x0,0x0,0x0,0x0,0x0,0x0,0x0,0x0,0x0,0x0,0x0,0x0,0x0,0x0,0x0,0x0,0x0,0x0,0x0,0x0,0x0,0x0,0x0,0x0,0x0,0x0,0x0,0x0,0x0,0x0,0x0,0x0,0x0,0x0,0x0,0x0,0x0,0x0,0x0,0x0,0x0,0x0,0x0,0x0,0x0,0x0,0x0,0x0,0x0,0x0,0x0,0x0,0x0,0x0,0x0,0x0,0x0,0x0,0x0,0x0,0x0,0x0,0x0,0x0,0x0,0x0,0x0,0x0,0x0,0x0,0x0,0x0,0x0,0x0,0x0,0x0,0x0,0x0,0x0,0x0,0x0,0x0,0x0,0x0,0x0,0x0,0x0,0x0,0x0,0x0,0x0,0x0,0x0,0x0,0x0,0x0,0x0,0x0,0x0,0x0,0x0,0x0,0x0,0x0,0x0,0x0,0x0,0x0,0x0,0x0,0x0,0x0,0x0,0x0,0x0,0x0,0x0,0x0,0x0,0x0,0x0,0x0,0x0,0x0,0x0,0x0,0x0,0x0,0x0,0x0,0x0,0x0,0x0,0x0,0x0,0x0,0x0,0x0,0x0,0x0,0x0,0x0,0x0,0x0,0x0,0x0,0x0,0x0,0x0,0x0,0x0,0x0,0x0,0x0,0x0,0x0,0x0,0x0,0x0,0x0,0x0,0x0,0x0,0x0,0x0,0x0,0x0,0x0,0x0,0x0,0x0,0x0,0x0,0x0,0x0,0x0,0x0,0x0,0x0,0x0,0x0,0x0,0x0,0x0,0x0,0x0,0x0,0x0,0x0,0x0,0x0,0x0,0x0,0x0,0x0,0x0,0x0,0x0,0x0,0x0,0x0,0x0,0x0,0x0,0x0,0x0,0x0,0x0,0x0,0x0,0x0,0x0,0x0,0x0,0x0,0x0,0x0,0x0,0x0,0x0,0x0,0x0,0x0,0x0,0x0,0x0,0x0,0x0,0x0,0x0,0x0,0x0,0x0,0x0,0x0,0x0,0x0,0x0,0x0,0x0,0x0,0x0,0x0,0x0,0x0,0x0,0x0,0x0,0x0,0x0,0x0,0x0,0x0,0x0,0x0,0x0,0x0,0x0,0x0,0x0,0x0,0x0,0x0,0x0,0x0,0x0,0x0,0x0,0x0,0x0,0x0,0x0,0x0,0x0,0x0,0x0,0x0,0x0,0x0,0x0,0x0,0x0,0x0,0x0,0x0,0x0,0x0,0x0,0x0,0x0,0x0,0x0,0x0,0x0,0x0,0x0,0x0,0x0,0x0,0x0,0x0,0x0,0x0,0x0,0x0,0x0,0x0,0x0,0x0,0x0,0x0,0x0,0x0,0x0,0x0,0x0,0x0,0x0,0x0,0x0,0x0,0x0,0x0,0x0,0x0,0x0,0x0,0x0,0x0,0x0,0x0,0x0,0x0,0x0,0x0,0x0,0x0,0x0,0x0,0x0,0x0,0x0,0x0,0x0,0x0,0x0,0x0,0x0,0x0,0x0,0x0,0x0,0x0,0x0,0x0,0x0,0x0,0x0,0x0,0x0,0x0,0x0,0x0,0x0,0x0,0x0,0x0,0x0,0x0,0x0,0x0,0x0,0x0,0x0,0x0,0x0,0x0,0x0,0x0,0x0,0x0,0x0,0x0,0x0,0x0,0x0,0x0,0x0,0x0,0x0,0x0,0x0,0x0,0x0,0x0,0x0,0x0,0x0,0x0,0x0,0x0,0x0,0x0,0x0,0x0,0x0,0x0,0x0,0x0,0x0,0x0,0x0,0x0,0x0,0x0,0x0,0x0,0x0,0x0,0x0,0x0,0x0,0x0,0x0,0x0,0x0,0x0,0x0,0x0,0x0,0x0,0x0,0x0,0x0,0x0,0x0,0x0,0x0,0x0,0x0,0x0,0x0,0x0,0x0,0x0,0x0,0x0,0x0,0x0,0x0,0x0,0x0,0x0,0x0,0x0,0x0,0x0,0x0,0x0,0x0,0x0,0x0,0x0,0x0,0x0,0x0,0x0,0x0,0x0,0x0,0x0,0x0,0x0,0x0,0x0,0x0,0x0,0x0,0x0,0x0,0x0,0x0,0x0,0x0,0x0,0x0,0x0,0x0,0x0,0x0,0x0,0x0,0x0,0x0,0x0,0x0,0x0,0x0,0x0,0x0,0x0,0x0,0x0,0x0,0x0,0x0,0x0,0x0,0x0,0x0,0x0,0x0,0x0,0x0,0x0,0x0,0x0,0x0,0x0,0x0,0x0,0x0,0x0,0x0,0x0,0x0,0x0,0x0,0x0,0x0,0x0,0x0,0x0,0x0,0x0,0x0,0x0,0x0,0x0,0x0,0x0,0x0,0x0,0x0,0x0,0x0,0x0,0x0,0x0,0x0,0x0,0x0,0x0,0x0,0x0,0x0,0x0,0x0,0x0,0x0,0x0,0x0,0x0,0x0,0x0,0x0,0x0,0x0,0x0,0x0,0x0,0x0,0x0,0x0,0x0,0x0,0x0,0x0,0x0,0x0,0x0,0x0,0x0,0x0,0x0,0x0,0x0,0x0,0x0,0x0,0x0,0x0,0x0,0x0,0x0,0x0,0x0,0x0,0x0,0x0,0x0,0x0,0x0,0x0,0x0,0x0,0x0,0x0,0x0,0x0,0x0,0x0,0x0,0x0,0x0,0x0,0x0,0x0,0x0,0x0,0x0,0x0,0x0,0x0,0x0,0x0,0x0,0x0,0x0,0x0,0x0,0x0,0x0,0x0,0x0,0x0,0x0,0x0,0x0,0x0,0x0,0x0,0x0,0x0,0x0,0x0,0x0,0x0,0x0,0x0,0x0,0x0,0x0,0x0,0x0,0x0,0x0,0x0,0x0,0x0,0x0,0x0,0x0,0x0,0x0,0x0,0x0,0x0,0x0,0x0,0x0,0x0,0x0,0x0,0x0,0x0,0x0,0x0,0x0,0x0,0x0,0x0,0x0,0x0,0x0,0x0,0x0,0x0,0x0,0x0,0x0,0x0,0x0,0x0,0x0,0x0,0x0,0x0,0x0,0x0,0x0,0x0,0x0,0x0,0x0,0x0,0x0,0x0,0x0,0x0,0x0,0x0,0x0,0x0,0x0,0x0,0x0,0x0,0x0,0x0,0x0,0x0,0x0,0x0,0x0,0x0,0x0,0x0,0x0,0x0,0x0,0x0,0x0,0x0,0x0,0x0,0x0,0x0,0x0,0x0,0x0,0x0,0x0,0x0,0x0,0x0,0x0,0x0,0x0,0x0,0x0,0x0,0x0,0x0,0x0,0x0,0x0,0x0,0x0,0x0,0x0,0x0,0x0,0x0,0x0,0x0,0x0,0x0,0x0,0x0,0x0,0x0,0x0,0x0,0x0,0x0,0x0,0x0,0x0,0x0,0x0,0x0,0x0,0x0,0x0,0x0,0x0,0x0,0x0,0x0,0x0,0x0,0x0,0x0,0x0,0x0,0x0,0x0,0x0,0x0,0x0,0x0,0x0,0x0,0x0,0x0,0x0,0x0,0x0,0x0,0x0,0x0,0x0,0x0,0x0,0x0,0x0,0x0,0x0,0x0,0x0,0x0,0x0,0x0,0x0,0x0,0x0,0x0,0x0,0x0,0x0,0x0,0x0,0x0,0x0,0x0,0x0,0x0,0x0,0x0,0x0,0x0,0x0,0x0,0x0,0x0,0x0,0x0,0x0,0x0,0x0,0x0,0x0,0x0,0x0,0x0,0x0,0x0,0x0,0x0,0x0,0x0,0x0,0x0,0x0,0x0,0x0,0x0,0x0,0x0,0x0,0x0,0x0,0x0,0x0,0x0,0x0,0x0,0x0,0x0,0x0,0x0,0x0,0x0,0x0,0x0,0x0,0x0,0x0,0x0,0x0,0x0,0x0,0x0,0x0,0x0,0x0,0x0,0x0,0x0,0x0,0x0,0x0,0x0,0x0,0x0,0x0,0x0,0x0,0x0,0x0,0x0,0x0,0x0,0x0,0x0,0x0,0x0,0x0,0x0,0x0,0x0,0x0,0x0,0x0,0x0,0x0,0x0,0x0,0x0,0x0,0x0,0x0,0x0,0x0,0x0,0x0,0x0,0x0,0x0,0x0,0x0,0x0,0x0,0x0,0x0,0x0,0x0,0x0,0x0,0x0,0x0,0x0,0x0,0x0,0x0,0x0,0x0,0x0,0x0,0x0,0x0,0x0,0x0,0x0,0x0,0x0,0x0,0x0,0x0,0x0,0x0,0x0,0x0,0x0,0x0,0x0,0x0,0x0,0x0,0x0,0x0,0x0,0x0,0x0,0x0,0x0,0x0,0x0,0x0,0x0,0x0,0x0,0x0,0x0,0x0,0x0,0x0,0x0,0x0,0x0,0x0,0x0,0x0,0x0,0x0,0x0,0x0,0x0,0x0,0x0,0x0,0x0,0x0,0x0,0x0,0x0,0x0,0x0,0x0,0x0,0x0,0x0,0x0,0x0,0x0,0x0,0x0,0x0,0x0,0x0,0x0,0x0,0x0,0x0,0x0,0x0,0x0,0x0,0x0,0x0,0x0,0x0,0x0,0x0,0x0,0x0,0x0,0x0,0x0,0x0,0x0,0x0,0x0,0x0,0x0,0x0,0x0,0x0,0x0,0x0,0x0,0x0,0x0,0x0,0x0,0x0,0x0,0x0,0x0,0x0,0x0,0x0,0x0,0x0,0x0,0x0,0x0,0x0,0x0,0x0,0x0,0x0,0x0,0x0,0x0,0x0,0x0,0x0,0x0,0x0,0x0,0x0,0x0,0x0,0x0,0x0,0x0,0x0,0x0,0x0,0x0,0x0,0x0,0x0,0x0,0x0,0x0,0x0,0x0,0x0,0x0,0x0,0x0,0x0,0x0,0x0,0x0,0x0,0x0,0x0,0x0,0x0,0x0,0x0,0x0,0x0,0x0,0x0,0x0,0x0,0x0,0x0,0x0,0x0,0x0,0x0,0x0,0x0,0x0,0x0,0x0,0x0,0x0,0x0,0x0,0x0,0x0,0x0,0x0,0x0,0x0,0x0,0x0,0x0,0x0,0x0,0x0,0x0,0x0,0x0,0x0,0x0,0x0,0x0,0x0,0x0,0x0,0x0,0x0,0x0,0x0,0x0,0x0,0x0,0x0,0x0,0x0,0x0,0x0,0x0,0x0,0x0,0x0,0x0,0x0,0x0,0x0,0x0,0x0,0x0,0x0,0x0,0x0,0x0,0x0,0x0,0x0,0x0,0x0,0x0,0x0,0x0,0x0,0x0,0x0,0x0,0x0,0x0,0x0,0x0,0x0,0x0,0x0,0x0,0x0,0x0,0x0,0x0,0x0,0x0,0x0,0x0,0x0,0x0,0x0,0x0,0x0,0x0,0x0,0x0,0x0,0x0,0x0,0x0,0x0,0x0,0x0,0x0,0x0,0x0,0x0,0x0,0x0,0x0,0x0,0x0,0x0,0x0,0x0,0x0,0x0,0x0,0x0,0x0,0x0,0x0,0x0,0x0,0x0,0x0,0x0,0x0,0x0,0x0,0x0,0x0,0x0,0x0,0x0,0x0,0x0,0x0,0x0,0x0,0x0,0x0,]

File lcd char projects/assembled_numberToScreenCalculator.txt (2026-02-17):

[0x0,0xf,0x28,0xe3,0xfe,0x0,0xff,0x28,0xe2,0xfe,0x0,0x0,0x28,0x0,0x8,0x28,0xa,0x8,0x28,0xb,0x8,0x0,0xff,0x28,0xf2,0xfe,0x28,0xf3,0xfe,0x0,0x38,0x28,0xf1,0xfe,0x0,0x2,0x28,0xf0,0xfe,0x0,0x0,0x28,0xf0,0xfe,0x0,0xf,0x28,0xf1,0xfe,0x0,0x2,0x28,0xf0,0xfe,0x0,0x0,0x28,0xf0,0xfe,0x0,0x6,0x28,0xf1,0xfe,0x0,0x2,0x28,0xf0,0xfe,0x0,0x0,0x28,0xf0,0xfe,0x36,0xb3,0x0,0x36,0xd2,0x0,0x2f,0x11,0xe0,0xfe,0x2e,0x28,0xe0,0xfe,0x3c,0xa4,0x0,0x2f,0x10,0x10,0x2e,0x3c,0xa4,0x0,0x2f,0x10,0xa,0x2e,0x3c,0x78,0x0,0x2f,0x10,0xb,0x2e,0x3c,0x78,0x0,0x2f,0x10,0xc,0x2e,0x3c,0x78,0x0,0x2f,0x5,0xb,0x8,0x2f,0xa,0x10,0x4,0x2e,0x3c,0xa4,0x0,0x8,0x2b,0xb,0x8,0x36,0xa7,0x0,0x5,0x0,0x8,0x2f,0x3,0x2,0x8,0x2a,0x1,0x8,0x3,0x3,0x8,0x2a,0x2,0x8,0x3,0x4,0x8,0x2a,0x3,0x8,0x2e,0x2a,0x4,0x8,0x3b,0x4a,0x0,0x2f,0xc,0x30,0x31,0x2f,0x36,0xeb,0x0,0x2e,0x30,0x2e,0x37,0x31,0x33,0x0,0x1,0xb,0x28,0xe1,0xfe,0x11,0xe1,0xfe,0x3d,0xcc,0x0,0xa,0x10,0x8,0x3c,0xcc,0x0,0xa,0x25,0x3b,0xb7,0x0,0x1,0xe1,0xfe,0x32,0x30,0x37,0x31,0x33,0x4,0x0,0x2f,0x13,0x21,0x1,0x2e,0x3c,0xe7,0x0,0x2f,0x8,0xa,0x10,0x10,0x2e,0x3d,0xd6,0x0,0xa,0x32,0x30,0x37,0x4,0x3,0x34,0x28,0xf1,0xfe,0x0,0x3,0x28,0xf0,0xfe,0x0,0x0,0x28,0xf0,0xfe,0x37,0x2f,0x3,0x1,0x8,0x17,0x6,0x8,0x10,0xa,0x3f,0xb,0x1,0x3b,0x15,0x1,0x2a,0x1,0x8,0x0,0xff,0xc,0x1,0x3b,0x1f,0x1,0xc,0xa,0x2a,0x1,0x8,0xc,0x0,0x3b,0x1f,0x1,0x2e,0x37,40,17,33,65,18,34,66,20,36,68,129,130,132,136,24,72,0x0,0x0,0x0,0x0,0x0,0x0,0x0,0x0,0x0,0x0,0x0,0x0,0x0,0x0,0x0,0x0,0x0,0x0,0x0,0x0,0x0,0x0,0x0,0x0,0x0,0x0,0x0,0x0,0x0,0x0,0x0,0x0,0x0,0x0,0x0,0x0,0x0,0x0,0x0,0x0,0x0,0x0,0x0,0x0,0x0,0x0,0x0,0x0,0x0,0x0,0x0,0x0,0x0,0x0,0x0,0x0,0x0,0x0,0x0,0x0,0x0,0x0,0x0,0x0,0x0,0x0,0x0,0x0,0x0,0x0,0x0,0x0,0x0,0x0,0x0,0x0,0x0,0x0,0x0,0x0,0x0,0x0,0x0,0x0,0x0,0x0,0x0,0x0,0x0,0x0,0x0,0x0,0x0,0x0,0x0,0x0,0x0,0x0,0x0,0x0,0x0,0x0,0x0,0x0,0x0,0x0,0x0,0x0,0x0,0x0,0x0,0x0,0x0,0x0,0x0,0x0,0x0,0x0,0x0,0x0,0x0,0x0,0x0,0x0,0x0,0x0,0x0,0x0,0x0,0x0,0x0,0x0,0x0,0x0,0x0,0x0,0x0,0x0,0x0,0x0,0x0,0x0,0x0,0x0,0x0,0x0,0x0,0x0,0x0,0x0,0x0,0x0,0x0,0x0,0x0,0x0,0x0,0x0,0x0,0x0,0x0,0x0,0x0,0x0,0x0,0x0,0x0,0x0,0x0,0x0,0x0,0x0,0x0,0x0,0x0,0x0,0x0,0x0,0x0,0x0,0x0,0x0,0x0,0x0,0x0,0x0,0x0,0x0,0x0,0x0,0x0,0x0,0x0,0x0,0x0,0x0,0x0,0x0,0x0,0x0,0x0,0x0,0x0,0x0,0x0,0x0,0x0,0x0,0x0,0x0,0x0,0x0,0x0,0x0,0x0,0x0,0x0,0x0,0x0,0x0,0x0,0x0,0x0,0x0,0x0,0x0,0x0,0x0,0x0,0x0,0x0,0x0,0x0,0x0,0x0,0x0,0x0,0x0,0x0,0x0,0x0,0x0,0x0,0x0,0x0,0x0,0x0,0x0,0x0,0x0,0x0,0x0,0x0,0x0,0x0,0x0,0x0,0x0,0x0,0x0,0x0,0x0,0x0,0x0,0x0,0x0,0x0,0x0,0x0,0x0,0x0,0x0,0x0,0x0,0x0,0x0,0x0,0x0,0x0,0x0,0x0,0x0,0x0,0x0,0x0,0x0,0x0,0x0,0x0,0x0,0x0,0x0,0x0,0x0,0x0,0x0,0x0,0x0,0x0,0x0,0x0,0x0,0x0,0x0,0x0,0x0,0x0,0x0,0x0,0x0,0x0,0x0,0x0,0x0,0x0,0x0,0x0,0x0,0x0,0x0,0x0,0x0,0x0,0x0,0x0,0x0,0x0,0x0,0x0,0x0,0x0,0x0,0x0,0x0,0x0,0x0,0x0,0x0,0x0,0x0,0x0,0x0,0x0,0x0,0x0,0x0,0x0,0x0,0x0,0x0,0x0,0x0,0x0,0x0,0x0,0x0,0x0,0x0,0x0,0x0,0x0,0x0,0x0,0x0,0x0,0x0,0x0,0x0,0x0,0x0,0x0,0x0,0x0,0x0,0x0,0x0,0x0,0x0,0x0,0x0,0x0,0x0,0x0,0x0,0x0,0x0,0x0,0x0,0x0,0x0,0x0,0x0,0x0,0x0,0x0,0x0,0x0,0x0,0x0,0x0,0x0,0x0,0x0,0x0,0x0,0x0,0x0,0x0,0x0,0x0,0x0,0x0,0x0,0x0,0x0,0x0,0x0,0x0,0x0,0x0,0x0,0x0,0x0,0x0,0x0,0x0,0x0,0x0,0x0,0x0,0x0,0x0,0x0,0x0,0x0,0x0,0x0,0x0,0x0,0x0,0x0,0x0,0x0,0x0,0x0,0x0,0x0,0x0,0x0,0x0,0x0,0x0,0x0,0x0,0x0,0x0,0x0,0x0,0x0,0x0,0x0,0x0,0x0,0x0,0x0,0x0,0x0,0x0,0x0,0x0,0x0,0x0,0x0,0x0,0x0,0x0,0x0,0x0,0x0,0x0,0x0,0x0,0x0,0x0,0x0,0x0,0x0,0x0,0x0,0x0,0x0,0x0,0x0,0x0,0x0,0x0,0x0,0x0,0x0,0x0,0x0,0x0,0x0,0x0,0x0,0x0,0x0,0x0,0x0,0x0,0x0,0x0,0x0,0x0,0x0,0x0,0x0,0x0,0x0,0x0,0x0,0x0,0x0,0x0,0x0,0x0,0x0,0x0,0x0,0x0,0x0,0x0,0x0,0x0,0x0,0x0,0x0,0x0,0x0,0x0,0x0,0x0,0x0,0x0,0x0,0x0,0x0,0x0,0x0,0x0,0x0,0x0,0x0,0x0,0x0,0x0,0x0,0x0,0x0,0x0,0x0,0x0,0x0,0x0,0x0,0x0,0x0,0x0,0x0,0x0,0x0,0x0,0x0,0x0,0x0,0x0,0x0,0x0,0x0,0x0,0x0,0x0,0x0,0x0,0x0,0x0,0x0,0x0,0x0,0x0,0x0,0x0,0x0,0x0,0x0,0x0,0x0,0x0,0x0,0x0,0x0,0x0,0x0,0x0,0x0,0x0,0x0,0x0,0x0,0x0,0x0,0x0,0x0,0x0,0x0,0x0,0x0,0x0,0x0,0x0,0x0,0x0,0x0,0x0,0x0,0x0,0x0,0x0,0x0,0x0,0x0,0x0,0x0,0x0,0x0,0x0,0x0,0x0,0x0,0x0,0x0,0x0,0x0,0x0,0x0,0x0,0x0,0x0,0x0,0x0,0x0,0x0,0x0,0x0,0x0,0x0,0x0,0x0,0x0,0x0,0x0,0x0,0x0,0x0,0x0,0x0,0x0,0x0,0x0,0x0,0x0,0x0,0x0,0x0,0x0,0x0,0x0,0x0,0x0,0x0,0x0,0x0,0x0,0x0,0x0,0x0,0x0,0x0,0x0,0x0,0x0,0x0,0x0,0x0,0x0,0x0,0x0,0x0,0x0,0x0,0x0,0x0,0x0,0x0,0x0,0x0,0x0,0x0,0x0,0x0,0x0,0x0,0x0,0x0,0x0,0x0,0x0,0x0,0x0,0x0,0x0,0x0,0x0,0x0,0x0,0x0,0x0,0x0,0x0,0x0,0x0,0x0,0x0,0x0,0x0,0x0,0x0,0x0,0x0,0x0,0x0,0x0,0x0,0x0,0x0,0x0,0x0,0x0,0x0,0x0,0x0,0x0,0x0,0x0,0x0,0x0,0x0,0x0,0x0,0x0,0x0,0x0,0x0,0x0,0x0,0x0,0x0,0x0,0x0,0x0,0x0,0x0,0x0,0x0,0x0,0x0,0x0,0x0,0x0,0x0,0x0,0x0,0x0,0x0,0x0,0x0,0x0,0x0,0x0,0x0,0x0,0x0,0x0,0x0,0x0,0x0,0x0,0x0,0x0,0x0,0x0,0x0,0x0,0x0,0x0,0x0,0x0,0x0,0x0,0x0,0x0,0x0,0x0,0x0,0x0,0x0,0x0,0x0,0x0,0x0,0x0,0x0,0x0,0x0,0x0,0x0,0x0,0x0,0x0,0x0,0x0,0x0,0x0,0x0,0x0,0x0,0x0,0x0,0x0,0x0,0x0,0x0,0x0,0x0,0x0,0x0,0x0,0x0,0x0,0x0,0x0,0x0,0x0,0x0,0x0,0x0,0x0,0x0,0x0,0x0,0x0,0x0,0x0,0x0,0x0,0x0,0x0,0x0,0x0,0x0,0x0,0x0,0x0,0x0,0x0,0x0,0x0,0x0,0x0,0x0,0x0,0x0,0x0,0x0,0x0,0x0,0x0,0x0,0x0,0x0,0x0,0x0,0x0,0x0,0x0,0x0,0x0,0x0,0x0,0x0,0x0,0x0,0x0,0x0,0x0,0x0,0x0,0x0,0x0,0x0,0x0,0x0,0x0,0x0,0x0,0x0,0x0,0x0,0x0,0x0,0x0,0x0,0x0,0x0,0x0,0x0,0x0,0x0,0x0,0x0,0x0,0x0,0x0,0x0,0x0,0x0,0x0,0x0,0x0,0x0,0x0,0x0,0x0,0x0,0x0,0x0,0x0,0x0,0x0,0x0,0x0,0x0,0x0,0x0,0x0,0x0,0x0,0x0,0x0,0x0,0x0,0x0,0x0,0x0,0x0,0x0,0x0,0x0,0x0,0x0,0x0,0x0,0x0,0x0,0x0,0x0,0x0,0x0,0x0,0x0,0x0,0x0,0x0,0x0,0x0,0x0,0x0,0x0,0x0,0x0,0x0,0x0,0x0,0x0,0x0,0x0,0x0,0x0,0x0,0x0,0x0,0x0,0x0,0x0,0x0,0x0,0x0,0x0,0x0,0x0,0x0,0x0,0x0,0x0,0x0,0x0,0x0,0x0,0x0,0x0,0x0,0x0,0x0,0x0,0x0,0x0,0x0,0x0,0x0,0x0,0x0,0x0,0x0,0x0,0x0,0x0,0x0,0x0,0x0,0x0,0x0,0x0,0x0,0x0,0x0,0x0,0x0,0x0,0x0,0x0,0x0,0x0,0x0,0x0,0x0,0x0,0x0,0x0,0x0,0x0,0x0,0x0,0x0,0x0,0x0,0x0,0x0,0x0,0x0,0x0,0x0,0x0,0x0,0x0,0x0,0x0,0x0,0x0,0x0,0x0,0x0,0x0,0x0,0x0,0x0,0x0,0x0,0x0,0x0,0x0,0x0,0x0,0x0,0x0,0x0,0x0,0x0,0x0,0x0,0x0,0x0,0x0,0x0,0x0,0x0,0x0,0x0,0x0,0x0,0x0,0x0,0x0,0x0,0x0,0x0,0x0,0x0,0x0,0x0,0x0,0x0,0x0,0x0,0x0,0x0,0x0,0x0,0x0,0x0,0x0,0x0,0x0,0x0,0x0,0x0,0x0,0x0,0x0,0x0,0x0,0x0,0x0,0x0,0x0,0x0,0x0,0x0,0x0,0x0,0x0,0x0,0x0,0x0,0x0,0x0,0x0,0x0,0x0,0x0,0x0,0x0,0x0,0x0,0x0,0x0,0x0,0x0,0x0,0x0,0x0,0x0,0x0,0x0,0x0,0x0,0x0,0x0,0x0,0x0,0x0,0x0,0x0,0x0,0x0,0x0,0x0,0x0,0x0,0x0,0x0,0x0,0x0,0x0,0x0,0x0,0x0,0x0,0x0,0x0,0x0,0x0,0x0,0x0,0x0,0x0,0x0,0x0,0x0,0x0,0x0,0x0,0x0,0x0,0x0,0x0,0x0,0x0,0x0,0x0,0x0,0x0,0x0,0x0,0x0,0x0,0x0,0x0,0x0,0x0,0x0,0x0,0x0,0x0,0x0,0x0,0x0,0x0,0x0,0x0,0x0,0x0,0x0,0x0,0x0,0x0,0x0,0x0,0x0,0x0,0x0,0x0,0x0,0x0,0x0,0x0,0x0,0x0,0x0,0x0,0x0,0x0,0x0,0x0,0x0,0x0,0x0,0x0,0x0,0x0,0x0,0x0,0x0,0x0,0x0,0x0,0x0,0x0,0x0,0x0,0x0,0x0,0x0,0x0,0x0,0x0,0x0,0x0,0x0,0x0,0x0,0x0,0x0,0x0,0x0,0x0,0x0,0x0,0x0,0x0,0x0,0x0,0x0,0x0,0x0,0x0,0x0,0x0,0x0,0x0,0x0,0x0,0x0,0x0,0x0,0x0,0x0,0x0,0x0,0x0,0x0,0x0,0x0,0x0,0x0,0x0,0x0,0x0,0x0,0x0,0x0,0x0,0x0,0x0,0x0,0x0,0x0,0x0,0x0,0x0,0x0,0x0,0x0,0x0,0x0,0x0,0x0,0x0,0x0,0x0,0x0,0x0,0x0,0x0,0x0,0x0,0x0,0x0,0x0,0x0,0x0,0x0,0x0,0x0,0x0,0x0,0x0,0x0,0x0,0x0,0x0,0x0,0x0,0x0,0x0,0x0,0x0,0x0,0x0,0x0,0x0,0x0,0x0,0x0,0x0,0x0,0x0,0x0,0x0,0x0,0x0,0x0,0x0,0x0,0x0,0x0,0x0,0x0,0x0,0x0,0x0,0x0,0x0,0x0,0x0,0x0,0x0,0x0,0x0,0x0,0x0,0x0,0x0,0x0,0x0,0x0,0x0,0x0,0x0,0x0,0x0,0x0,0x0,0x0,0x0,0x0,0x0,0x0,0x0,0x0,0x0,0x0,0x0,0x0,0x0,0x0,0x0,0x0,0x0,0x0,0x0,0x0,0x0,0x0,0x0,0x0,0x0,0x0,0x0,0x0,0x0,0x0,0x0,0x0,0x0,0x0,0x0,0x0,0x0,0x0,0x0,0x0,0x0,0x0,0x0,0x0,0x0,0x0,0x0,0x0,0x0,0x0,0x0,0x0,0x0,0x0,0x0,0x0,0x0,0x0,0x0,0x0,0x0,0x0,0x0,0x0,0x0,0x0,0x0,0x0,0x0,0x0,0x0,0x0,0x0,0x0,0x0,0x0,0x0,0x0,0x0,0x0,0x0,0x0,0x0,0x0,0x0,0x0,0x0,0x0,0x0,0x0,0x0,0x0,0x0,0x0,0x0,0x0,0x0,0x0,0x0,0x0,0x0,0x0,0x0,0x0,0x0,0x0,0x0,0x0,0x0,0x0,0x0,0x0,0x0,0x0,0x0,0x0,0x0,0x0,0x0,0x0,0x0,0x0,0x0,0x0,0x0,0x0,0x0,0x0,0x0,0x0,0x0,0x0,0x0,0x0,0x0,0x0,0x0,0x0,0x0,0x0,0x0,0x0,0x0,0x0,0x0,0x0,0x0,0x0,0x0,0x0,0x0,0x0,0x0,0x0,0x0,0x0,0x0,0x0,0x0,0x0,0x0,0x0,0x0,0x0,0x0,0x0,0x0,0x0,0x0,0x0,0x0,0x0,0x0,0x0,0x0,0x0,0x0,0x0,0x0,0x0,0x0,0x0,0x0,0x0,0x0,0x0,0x0,0x0,0x0,0x0,0x0,0x0,0x0,0x0,0x0,0x0,0x0,0x0,0x0,0x0,0x0,0x0,0x0,0x0,0x0,0x0,0x0,0x0,0x0,0x0,0x0,0x0,0x0,0x0,0x0,0x0,0x0,0x0,0x0,0x0,0x0,0x0,0x0,0x0,0x0,0x0,0x0,0x0,0x0,0x0,0x0,0x0,0x0,0x0,0x0,0x0,0x0,0x0,0x0,0x0,0x0,0x0,0x0,0x0,0x0,0x0,0x0,0x0,0x0,0x0,0x0,0x0,0x0,0x0,0x0,0x0,0x0,0x0,0x0,0x0,0x0,0x0,0x0,0x0,0x0,0x0,0x0,0x0,0x0,0x0,0x0,0x0,0x0,0x0,0x0,0x0,0x0,0x0,0x0,0x0,0x0,0x0,0x0,0x0,0x0,0x0,0x0,0x0,0x0,0x0,0x0,0x0,0x0,0x0,0x0,0x0,0x0,0x0,0x0,0x0,0x0,0x0,0x0,0x0,0x0,0x0,0x0,0x0,0x0,0x0,0x0,0x0,0x0,0x0,0x0,0x0,0x0,0x0,0x0,0x0,0x0,0x0,]

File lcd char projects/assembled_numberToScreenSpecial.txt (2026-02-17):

[0x0,0xf,0x28,0xe3,0xfe,0x0,0xff,0x28,0xe2,0xfe,0x0,0x0,0x28,0x0,0x8,0x0,0xff,0x28,0xf2,0xfe,0x28,0xf3,0xfe,0x0,0x38,0x28,0xf1,0xfe,0x0,0x2,0x28,0xf0,0xfe,0x0,0x0,0x28,0xf0,0xfe,0x0,0xf,0x28,0xf1,0xfe,0x0,0x2,0x28,0xf0,0xfe,0x0,0x0,0x28,0xf0,0xfe,0x0,0x6,0x28,0xf1,0xfe,0x0,0x2,0x28,0xf0,0xfe,0x0,0x0,0x28,0xf0,0xfe,0x36,0xd0,0x0,0x36,0xef,0x0,0x2f,0x11,0xe0,0xfe,0x2e,0x28,0xe0,0xfe,0x3c,0xc1,0x0,0x2f,0x10,0x10,0x2e,0x3c,0xc1,0x0,0x5,0x0,0x8,0x2a,0x1,0x8,0x8,0x2b,0x0,0x8,0x36,0xc4,0x0,0x1,0x0,0x8,0xb,0x10,0x4,0x3c,0x7b,0x0,0xa,0x10,0x9,0x3c,0x8a,0x0,0x3b,0xc1,0x0,0x5,0x0,0x8,0x8,0x2b,0x0,0x8,0x0,0xfb,0x36,0xc4,0x0,0x3b,0xc1,0x0,0x5,0x0,0x8,0x8,0x2b,0x0,0x8,0x0,0xd,0x36,0xc4,0x0,0xc,0x0,0x4,0x3,0x36,0x19,0x1,0x9,0x36,0x19,0x1,0x9,0x36,0x19,0x1,0x9,0x36,0x19,0x1,0x1,0x1,0x8,0x36,0xc4,0x0,0x1,0x2,0x8,0x36,0xc4,0x0,0x1,0x3,0x8,0x36,0xc4,0x0,0x1,0x4,0x8,0x36,0xc4,0x0,0x3b,0x44,0x0,0x2f,0xc,0x30,0x31,0x2f,0x36,0x8,0x1,0x2e,0x30,0x2e,0x37,0x31,0x33,0x0,0x1,0xb,0x28,0xe1,0xfe,0x11,0xe1,0xfe,0x3d,0xe9,0x0,0xa,0x10,0x8,0x3c,0xe9,0x0,0xa,0x25,0x3b,0xd4,0x0,0x1,0xe1,0xfe,0x32,0x30,0x37,0x31,0x33,0x4,0x0,0x2f,0x13,0x3e,0x1,0x2e,0x3c,0x4,0x1,0x2f,0x8,0xa,0x10,0x10,0x2e,0x3d,0xf3,0x0,0xa,0x32,0x30,0x37,0x4,0x3,0x34,0x28,0xf1,0xfe,0x0,0x3,0x28,0xf0,0xfe,0x0,0x0,0x28,0xf0,0xfe,0x37,0x2f,0x3,0x1,0x8,0x17,0x6,0x8,0x10,0xa,0x3f,0x28,0x1,0x3b,0x32,0x1,0x2a,0x1,0x8,0x0,0xff,0xc,0x1,0x3b,0x3c,0x1,0xc,0xa,0x2a,0x1,0x8,0xc,0x0,0x3b,0x3c,0x1,0x2e,0x37,40,17,33,65,18,34,66,20,36,68,129,130,132,136,24,72,0x0,0x0,0x0,0x0,0x0,0x0,0x0,0x0,0x0,0x0,0x0,0x0,0x0,0x0,0x0,0x0,0x0,0x0,0x0,0x0,0x0,0x0,0x0,0x0,0x0,0x0,0x0,0x0,0x0,0x0,0x0,0x0,0x0,0x0,0x0,0x0,0x0,0x0,0x0,0x0,0x0,0x0,0x0,0x0,0x0,0x0,0x0,0x0,0x0,0x0,0x0,0x0,0x0,0x0,0x0,0x0,0x0,0x0,0x0,0x0,0x0,0x0,0x0,0x0,0x0,0x0,0x0,0x0,0x0,0x0,0x0,0x0,0x0,0x0,0x0,0x0,0x0,0x0,0x0,0x0,0x0,0x0,0x0,0x0,0x0,0x0,0x0,0x0,0x0,0x0,0x0,0x0,0x0,0x0,0x0,0x0,0x0,0x0,0x0,0x0,0x0,0x0,0x0,0x0,0x0,0x0,0x0,0x0,0x0,0x0,0x0,0x0,0x0,0x0,0x0,0x0,0x0,0x0,0x0,0x0,0x0,0x0,0x0,0x0,0x0,0x0,0x0,0x0,0x0,0x0,0x0,0x0,0x0,0x0,0x0,0x0,0x0,0x0,0x0,0x0,0x0,0x0,0x0,0x0,0x0,0x0,0x0,0x0,0x0,0x0,0x0,0x0,0x0,0x0,0x0,0x0,0x0,0x0,0x0,0x0,0x0,0x0,0x0,0x0,0x0,0x0,0x0,0x0,0x0,0x0,0x0,0x0,0x0,0x0,0x0,0x0,0x0,0x0,0x0,0x0,0x0,0x0,0x0,0x0,0x0,0x0,0x0,0x0,0x0,0x0,0x0,0x0,0x0,0x0,0x0,0x0,0x0,0x0,0x0,0x0,0x0,0x0,0x0,0x0,0x0,0x0,0x0,0x0,0x0,0x0,0x0,0x0,0x0,0x0,0x0,0x0,0x0,0x0,0x0,0x0,0x0,0x0,0x0,0x0,0x0,0x0,0x0,0x0,0x0,0x0,0x0,0x0,0x0,0x0,0x0,0x0,0x0,0x0,0x0,0x0,0x0,0x0,0x0,0x0,0x0,0x0,0x0,0x0,0x0,0x0,0x0,0x0,0x0,0x0,0x0,0x0,0x0,0x0,0x0,0x0,0x0,0x0,0x0,0x0,0x0,0x0,0x0,0x0,0x0,0x0,0x0,0x0,0x0,0x0,0x0,0x0,0x0,0x0,0x0,0x0,0x0,0x0,0x0,0x0,0x0,0x0,0x0,0x0,0x0,0x0,0x0,0x0,0x0,0x0,0x0,0x0,0x0,0x0,0x0,0x0,0x0,0x0,0x0,0x0,0x0,0x0,0x0,0x0,0x0,0x0,0x0,0x0,0x0,0x0,0x0,0x0,0x0,0x0,0x0,0x0,0x0,0x0,0x0,0x0,0x0,0x0,0x0,0x0,0x0,0x0,0x0,0x0,0x0,0x0,0x0,0x0,0x0,0x0,0x0,0x0,0x0,0x0,0x0,0x0,0x0,0x0,0x0,0x0,0x0,0x0,0x0,0x0,0x0,0x0,0x0,0x0,0x0,0x0,0x0,0x0,0x0,0x0,0x0,0x0,0x0,0x0,0x0,0x0,0x0,0x0,0x0,0x0,0x0,0x0,0x0,0x0,0x0,0x0,0x0,0x0,0x0,0x0,0x0,0x0,0x0,0x0,0x0,0x0,0x0,0x0,0x0,0x0,0x0,0x0,0x0,0x0,0x0,0x0,0x0,0x0,0x0,0x0,0x0,0x0,0x0,0x0,0x0,0x0,0x0,0x0,0x0,0x0,0x0,0x0,0x0,0x0,0x0,0x0,0x0,0x0,0x0,0x0,0x0,0x0,0x0,0x0,0x0,0x0,0x0,0x0,0x0,0x0,0x0,0x0,0x0,0x0,0x0,0x0,0x0,0x0,0x0,0x0,0x0,0x0,0x0,0x0,0x0,0x0,0x0,0x0,0x0,0x0,0x0,0x0,0x0,0x0,0x0,0x0,0x0,0x0,0x0,0x0,0x0,0x0,0x0,0x0,0x0,0x0,0x0,0x0,0x0,0x0,0x0,0x0,0x0,0x0,0x0,0x0,0x0,0x0,0x0,0x0,0x0,0x0,0x0,0x0,0x0,0x0,0x0,0x0,0x0,0x0,0x0,0x0,0x0,0x0,0x0,0x0,0x0,0x0,0x0,0x0,0x0,0x0,0x0,0x0,0x0,0x0,0x0,0x0,0x0,0x0,0x0,0x0,0x0,0x0,0x0,0x0,0x0,0x0,0x0,0x0,0x0,0x0,0x0,0x0,0x0,0x0,0x0,0x0,0x0,0x0,0x0,0x0,0x0,0x0,0x0,0x0,0x0,0x0,0x0,0x0,0x0,0x0,0x0,0x0,0x0,0x0,0x0,0x0,0x0,0x0,0x0,0x0,0x0,0x0,0x0,0x0,0x0,0x0,0x0,0x0,0x0,0x0,0x0,0x0,0x0,0x0,0x0,0x0,0x0,0x0,0x0,0x0,0x0,0x0,0x0,0x0,0x0,0x0,0x0,0x0,0x0,0x0,0x0,0x0,0x0,0x0,0x0,0x0,0x0,0x0,0x0,0x0,0x0,0x0,0x0,0x0,0x0,0x0,0x0,0x0,0x0,0x0,0x0,0x0,0x0,0x0,0x0,0x0,0x0,0x0,0x0,0x0,0x0,0x0,0x0,0x0,0x0,0x0,0x0,0x0,0x0,0x0,0x0,0x0,0x0,0x0,0x0,0x0,0x0,0x0,0x0,0x0,0x0,0x0,0x0,0x0,0x0,0x0,0x0,0x0,0x0,0x0,0x0,0x0,0x0,0x0,0x0,0x0,0x0,0x0,0x0,0x0,0x0,0x0,0x0,0x0,0x0,0x0,0x0,0x0,0x0,0x0,0x0,0x0,0x0,0x0,0x0,0x0,0x0,0x0,0x0,0x0,0x0,0x0,0x0,0x0,0x0,0x0,0x0,0x0,0x0,0x0,0x0,0x0,0x0,0x0,0x0,0x0,0x0,0x0,0x0,0x0,0x0,0x0,0x0,0x0,0x0,0x0,0x0,0x0,0x0,0x0,0x0,0x0,0x0,0x0,0x0,0x0,0x0,0x0,0x0,0x0,0x0,0x0,0x0,0x0,0x0,0x0,0x0,0x0,0x0,0x0,0x0,0x0,0x0,0x0,0x0,0x0,0x0,0x0,0x0,0x0,0x0,0x0,0x0,0x0,0x0,0x0,0x0,0x0,0x0,0x0,0x0,0x0,0x0,0x0,0x0,0x0,0x0,0x0,0x0,0x0,0x0,0x0,0x0,0x0,0x0,0x0,0x0,0x0,0x0,0x0,0x0,0x0,0x0,0x0,0x0,0x0,0x0,0x0,0x0,0x0,0x0,0x0,0x0,0x0,0x0,0x0,0x0,0x0,0x0,0x0,0x0,0x0,0x0,0x0,0x0,0x0,0x0,0x0,0x0,0x0,0x0,0x0,0x0,0x0,0x0,0x0,0x0,0x0,0x0,0x0,0x0,0x0,0x0,0x0,0x0,0x0,0x0,0x0,0x0,0x0,0x0,0x0,0x0,0x0,0x0,0x0,0x0,0x0,0x0,0x0,0x0,0x0,0x0,0x0,0x0,0x0,0x0,0x0,0x0,0x0,0x0,0x0,0x0,0x0,0x0,0x0,0x0,0x0,0x0,0x0,0x0,0x0,0x0,0x0,0x0,0x0,0x0,0x0,0x0,0x0,0x0,0x0,0x0,0x0,0x0,0x0,0x0,0x0,0x0,0x0,0x0,0x0,0x0,0x0,0x0,0x0,0x0,0x0,0x0,0x0,0x0,0x0,0x0,0x0,0x0,0x0,0x0,0x0,0x0,0x0,0x0,0x0,0x0,0x0,0x0,0x0,0x0,0x0,0x0,0x0,0x0,0x0,0x0,0x0,0x0,0x0,0x0,0x0,0x0,0x0,0x0,0x0,0x0,0x0,0x0,0x0,0x0,0x0,0x0,0x0,0x0,0x0,0x0,0x0,0x0,0x0,0x0,0x0,0x0,0x0,0x0,0x0,0x0,0x0,0x0,0x0,0x0,0x0,0x0,0x0,0x0,0x0,0x0,0x0,0x0,0x0,0x0,0x0,0x0,0x0,0x0,0x0,0x0,0x0,0x0,0x0,0x0,0x0,0x0,0x0,0x0,0x0,0x0,0x0,0x0,0x0,0x0,0x0,0x0,0x0,0x0,0x0,0x0,0x0,0x0,0x0,0x0,0x0,0x0,0x0,0x0,0x0,0x0,0x0,0x0,0x0,0x0,0x0,0x0,0x0,0x0,0x0,0x0,0x0,0x0,0x0,0x0,0x0,0x0,0x0,0x0,0x0,0x0,0x0,0x0,0x0,0x0,0x0,0x0,0x0,0x0,0x0,0x0,0x0,0x0,0x0,0x0,0x0,0x0,0x0,0x0,0x0,0x0,0x0,0x0,0x0,0x0,0x0,0x0,0x0,0x0,0x0,0x0,0x0,0x0,0x0,0x0,0x0,0x0,0x0,0x0,0x0,0x0,0x0,0x0,0x0,0x0,0x0,0x0,0x0,0x0,0x0,0x0,0x0,0x0,0x0,0x0,0x0,0x0,0x0,0x0,0x0,0x0,0x0,0x0,0x0,0x0,0x0,0x0,0x0,0x0,0x0,0x0,0x0,0x0,0x0,0x0,0x0,0x0,0x0,0x0,0x0,0x0,0x0,0x0,0x0,0x0,0x0,0x0,0x0,0x0,0x0,0x0,0x0,0x0,0x0,0x0,0x0,0x0,0x0,0x0,0x0,0x0,0x0,0x0,0x0,0x0,0x0,0x0,0x0,0x0,0x0,0x0,0x0,0x0,0x0,0x0,0x0,0x0,0x0,0x0,0x0,0x0,0x0,0x0,0x0,0x0,0x0,0x0,0x0,0x0,0x0,0x0,0x0,0x0,0x0,0x0,0x0,0x0,0x0,0x0,0x0,0x0,0x0,0x0,0x0,0x0,0x0,0x0,0x0,0x0,0x0,0x0,0x0,0x0,0x0,0x0,0x0,0x0,0x0,0x0,0x0,0x0,0x0,0x0,0x0,0x0,0x0,0x0,0x0,0x0,0x0,0x0,0x0,0x0,0x0,0x0,0x0,0x0,0x0,0x0,0x0,0x0,0x0,0x0,0x0,0x0,0x0,0x0,0x0,0x0,0x0,0x0,0x0,0x0,0x0,0x0,0x0,0x0,0x0,0x0,0x0,0x0,0x0,0x0,0x0,0x0,0x0,0x0,0x0,0x0,0x0,0x0,0x0,0x0,0x0,0x0,0x0,0x0,0x0,0x0,0x0,0x0,0x0,0x0,0x0,0x0,0x0,0x0,0x0,0x0,0x0,0x0,0x0,0x0,0x0,0x0,0x0,0x0,0x0,0x0,0x0,0x0,0x0,0x0,0x0,0x0,0x0,0x0,0x0,0x0,0x0,0x0,0x0,0x0,0x0,0x0,0x0,0x0,0x0,0x0,0x0,0x0,0x0,0x0,0x0,0x0,0x0,0x0,0x0,0x0,0x0,0x0,0x0,0x0,0x0,0x0,0x0,0x0,0x0,0x0,0x0,0x0,0x0,0x0,0x0,0x0,0x0,0x0,0x0,0x0,0x0,0x0,0x0,0x0,0x0,0x0,0x0,0x0,0x0,0x0,0x0,0x0,0x0,0x0,0x0,0x0,0x0,0x0,0x0,0x0,0x0,0x0,0x0,0x0,0x0,0x0,0x0,0x0,0x0,0x0,0x0,0x0,0x0,0x0,0x0,0x0,0x0,0x0,0x0,0x0,0x0,0x0,0x0,0x0,0x0,0x0,0x0,0x0,0x0,0x0,0x0,0x0,0x0,0x0,0x0,0x0,0x0,0x0,0x0,0x0,0x0,0x0,0x0,0x0,0x0,0x0,0x0,0x0,0x0,0x0,0x0,0x0,0x0,0x0,0x0,0x0,0x0,0x0,0x0,0x0,0x0,0x0,0x0,0x0,0x0,0x0,0x0,0x0,0x0,0x0,0x0,0x0,0x0,0x0,0x0,0x0,0x0,0x0,0x0,0x0,0x0,0x0,0x0,0x0,0x0,0x0,0x0,0x0,0x0,0x0,0x0,0x0,0x0,0x0,0x0,0x0,0x0,0x0,0x0,0x0,0x0,0x0,0x0,0x0,0x0,0x0,0x0,0x0,0x0,0x0,0x0,0x0,0x0,0x0,0x0,0x0,0x0,0x0,0x0,0x0,0x0,0x0,0x0,0x0,0x0,0x0,0x0,0x0,0x0,0x0,0x0,0x0,0x0,0x0,0x0,0x0,0x0,0x0,0x0,0x0,0x0,0x0,0x0,0x0,0x0,0x0,0x0,0x0,0x0,0x0,0x0,0x0,0x0,0x0,0x0,0x0,0x0,0x0,0x0,0x0,0x0,0x0,0x0,0x0,0x0,0x0,0x0,0x0,0x0,0x0,0x0,0x0,0x0,0x0,0x0,0x0,0x0,0x0,0x0,0x0,0x0,0x0,0x0,0x0,0x0,0x0,0x0,0x0,0x0,0x0,0x0,0x0,0x0,0x0,0x0,0x0,0x0,0x0,0x0,0x0,0x0,0x0,0x0,0x0,0x0,0x0,0x0,0x0,0x0,0x0,0x0,0x0,0x0,0x0,0x0,0x0,0x0,0x0,0x0,0x0,0x0,0x0,0x0,0x0,0x0,0x0,0x0,0x0,0x0,0x0,0x0,0x0,0x0,0x0,0x0,0x0,0x0,0x0,0x0,0x0,0x0,0x0,0x0,0x0,0x0,0x0,0x0,0x0,0x0,0x0,0x0,0x0,0x0,0x0,0x0,0x0,0x0,0x0,0x0,0x0,0x0,0x0,0x0,0x0,0x0,0x0,0x0,0x0,0x0,0x0,0x0,0x0,0x0,0x0,0x0,0x0,0x0,0x0,0x0,0x0,0x0,0x0,0x0,0x0,0x0,0x0,0x0,0x0,0x0,0x0,0x0,0x0,0x0,0x0,0x0,0x0,0x0,0x0,0x0,0x0,0x0,0x0,0x0,0x0,0x0,0x0,0x0,0x0,0x0,0x0,0x0,0x0,0x0,0x0,0x0,0x0,0x0,0x0,0x0,0x0,0x0,0x0,0x0,0x0,0x0,0x0,0x0,0x0,0x0,0x0,0x0,0x0,0x0,0x0,0x0,0x0,0x0,0x0,0x0,0x0,0x0,0x0,0x0,0x0,0x0,0x0,0x0,0x0,0x0,0x0,0x0,0x0,0x0,0x0,0x0,0x0,0x0,0x0,0x0,0x0,0x0,0x0,0x0,0x0,0x0,0x0,0x0,0x0,0x0,0x0,0x0,0x0,0x0,0x0,0x0,0x0,0x0,0x0,0x0,0x0,0x0,0x0,0x0,0x0,0x0,0x0,0x0,0x0,0x0,0x0,0x0,0x0,0x0,0x0,0x0,0x0,0x0,0x0,0x0,0x0,0x0,0x0,0x0,0x0,0x0,0x0,0x0,0x0,0x0,]

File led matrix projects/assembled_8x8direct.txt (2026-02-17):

[0x0,0xff,0x28,0xf2,0xfe,0x28,0xf3,0xfe,0x0,0x14,0x28,0xc,0x8,0x0,0x10,0x28,0xa,0x8,0x28,0x10,0x8,0x0,0x3,0x28,0xb,0x8,0x28,0x50,0x8,0x0,0x0,0x28,0x0,0x8,0x28,0x1,0x8,0x28,0x2,0x8,0x28,0x3,0x8,0x28,0x4,0x8,0x28,0x5,0x8,0x28,0x6,0x8,0x28,0x7,0x8,0x28,0x8,0x8,0x28,0xd,0x8,0x28,0xf,0x8,0x28,0x4f,0x8,0x28,0x7f,0x8,0x28,0x92,0x8,0x28,0x94,0x8,0x0,0x1,0x28,0x91,0x8,0x28,0x93,0x8,0x0,0x3,0x28,0xe,0x8,0x4,0x0,0x0,0x0,0x0,0x0,0x2a,0x10,0x8,0x2a,0x50,0x8,0xa,0xc,0x1,0xb,0x10,0x40,0x3d,0x5d,0x0,0x0,0xf,0x28,0xe3,0xfe,0x0,0xff,0x28,0xe2,0xfe,0x36,0x1e,0x2,0xb,0x10,0x21,0x3c,0x96,0x0,0xa,0x10,0x12,0x3c,0x9b,0x0,0xa,0x10,0x42,0x3c,0xa5,0x0,0xa,0x10,0x22,0x3c,0xa0,0x0,0x3b,0xad,0x0,0x0,0x0,0x3b,0xaa,0x0,0x0,0x1,0x3b,0xaa,0x0,0x0,0x2,0x3b,0xaa,0x0,0x0,0x3,0x3b,0xaa,0x0,0x28,0x90,0x8,0x1,0xc,0x8,0xc,0x1,0x28,0xc,0x8,0x1,0xc,0x8,0x10,0x15,0x3d,0xb8,0x1,0x28,0xc,0x8,0x1,0x90,0x8,0x11,0x8,0x8,0x1c,0x3,0x10,0x2,0x3c,0xd3,0x0,0x1,0x90,0x8,0x28,0x8,0x8,0x1,0x93,0x8,0x25,0x14,0x0,0x25,0x14,0x0,0x25,0x14,0x0,0x25,0x14,0x0,0x25,0x14,0x0,0x28,0x93,0x8,0x1,0x94,0x8,0xc,0x7,0x1c,0x7,0x28,0x94,0x8,0x1,0x8,0x8,0x10,0x0,0x3c,0x7,0x1,0x10,0x1,0x3c,0x14,0x1,0x10,0x1,0x3c,0x32,0x1,0x3b,0x3f,0x1,0x5,0xb,0x8,0x9,0xa,0x1c,0x7,0x28,0xb,0x8,0x3b,0x4b,0x1,0x1,0xa,0x8,0x25,0x14,0x0,0x25,0x14,0x0,0x25,0x14,0x0,0x25,0x14,0x0,0x25,0x14,0x0,0x25,0x14,0x0,0x25,0x14,0x0,0x28,0xa,0x8,0x3b,0x4b,0x1,0x5,0xb,0x8,0x8,0xa,0x1c,0x7,0x28,0xb,0x8,0x3b,0x4b,0x1,0x1,0xa,0x8,0x25,0x14,0x0,0x28,0xa,0x8,0x3b,0x4b,0x1,0x1,0xf,0x8,0xc,0x1,0x1c,0x3f,0x28,0xf,0x8,0x1,0xa,0x8,0x11,0x91,0x8,0x3d,0x7a,0x1,0x1,0xb,0x8,0x11,0x92,0x8,0x3d,0x7a,0x1,0x1,0x93,0x8,0x28,0x91,0x8,0x1,0x94,0x8,0x28,0x92,0x8,0x5,0xe,0x8,0x8,0x2b,0xe,0x8,0x5,0xf,0x8,0x1,0xa,0x8,0x2a,0x10,0x8,0x1,0xb,0x8,0x2a,0x50,0x8,0x1,0xf,0x8,0x11,0xe,0x8,0x1c,0x3f,0xb,0x0,0xff,0x13,0x10,0x8,0x2f,0x3,0x50,0x8,0xb,0x2e,0x1f,0x0,0x8,0x2a,0x0,0x8,0x5,0xb,0x8,0x1,0xa,0x8,0x1f,0x0,0x8,0x3d,0xc4,0x1,0x1,0xa,0x8,0x23,0x0,0x8,0x2a,0x0,0x8,0x36,0xe2,0x1,0x1,0x9,0x8,0x28,0xe0,0xfe,0x3b,0x78,0x0,0x1,0xf,0x8,0x11,0xe,0x8,0x1c,0x3f,0xb,0x3,0x10,0x8,0x2f,0x3,0x50,0x8,0xb,0x2e,0x23,0x0,0x8,0x2a,0x0,0x8,0x36,0xe2,0x1,0x3b,0xc4,0x1,0x2f,0x31,0x33,0x0,0xfe,0x4,0x0,0x28,0xf0,0xfe,0xc,0x0,0x27,0x14,0x0,0x2f,0xa,0x11,0x92,0x8,0x0,0x0,0x3d,0xfe,0x1,0x1,0x91,0x8,0x23,0x0,0x8,0x28,0xf1,0xfe,0x8,0xa,0x10,0x8,0x3d,0x15,0x2,0x0,0x0,0x28,0xf1,0xfe,0x2e,0x32,0x30,0x2e,0x37,0x0,0x0,0x28,0xf1,0xfe,0x2e,0x3b,0xe9,0x1,0x31,0x33,0x0,0x1,0xb,0x28,0xe1,0xfe,0x11,0xe1,0xfe,0x3d,0x37,0x2,0xa,0x10,0x8,0x3c,0x37,0x2,0xa,0x25,0x3b,0x22,0x2,0x1,0xe1,0xfe,0x32,0x30,0x37,0x0,0x0,0x0,0x0,0x0,0x0,0x0,0x0,0x0,0x0,0x0,0x0,0x0,0x0,0x0,0x0,0x0,0x0,0x0,0x0,0x0,0x0,0x0,0x0,0x0,0x0,0x0,0x0,0x0,0x0,0x0,0x0,0x0,0x0,0x0,0x0,0x0,0x0,0x0,0x0,0x0,0x0,0x0,0x0,0x0,0x0,0x0,0x0,0x0,0x0,0x0,0x0,0x0,0x0,0x0,0x0,0x0,0x0,0x0,0x0,0x0,0x0,0x0,0x0,0x0,0x0,0x0,0x0,0x0,0x0,0x0,0x0,0x0,0x0,0x0,0x0,0x0,0x0,0x0,0x0,0x0,0x0,0x0,0x0,0x0,0x0,0x0,0x0,0x0,0x0,0x0,0x0,0x0,0x0,0x0,0x0,0x0,0x0,0x0,0x0,0x0,0x0,0x0,0x0,0x0,0x0,0x0,0x0,0x0,0x0,0x0,0x0,0x0,0x0,0x0,0x0,0x0,0x0,0x0,0x0,0x0,0x0,0x0,0x0,0x0,0x0,0x0,0x0,0x0,0x0,0x0,0x0,0x0,0x0,0x0,0x0,0x0,0x0,0x0,0x0,0x0,0x0,0x0,0x0,0x0,0x0,0x0,0x0,0x0,0x0,0x0,0x0,0x0,0x0,0x0,0x0,0x0,0x0,0x0,0x0,0x0,0x0,0x0,0x0,0x0,0x0,0x0,0x0,0x0,0x0,0x0,0x0,0x0,0x0,0x0,0x0,0x0,0x0,0x0,0x0,0x0,0x0,0x0,0x0,0x0,0x0,0x0,0x0,0x0,0x0,0x0,0x0,0x0,0x0,0x0,0x0,0x0,0x0,0x0,0x0,0x0,0x0,0x0,0x0,0x0,0x0,0x0,0x0,0x0,0x0,0x0,0x0,0x0,0x0,0x0,0x0,0x0,0x0,0x0,0x0,0x0,0x0,0x0,0x0,0x0,0x0,0x0,0x0,0x0,0x0,0x0,0x0,0x0,0x0,0x0,0x0,0x0,0x0,0x0,0x0,0x0,0x0,0x0,0x0,0x0,0x0,0x0,0x0,0x0,0x0,0x0,0x0,0x0,0x0,0x0,0x0,0x0,0x0,0x0,0x0,0x0,0x0,0x0,0x0,0x0,0x0,0x0,0x0,0x0,0x0,0x0,0x0,0x0,0x0,0x0,0x0,0x0,0x0,0x0,0x0,0x0,0x0,0x0,0x0,0x0,0x0,0x0,0x0,0x0,0x0,0x0,0x0,0x0,0x0,0x0,0x0,0x0,0x0,0x0,0x0,0x0,0x0,0x0,0x0,0x0,0x0,0x0,0x0,0x0,0x0,0x0,0x0,0x0,0x0,0x0,0x0,0x0,0x0,0x0,0x0,0x0,0x0,0x0,0x0,0x0,0x0,0x0,0x0,0x0,0x0,0x0,0x0,0x0,0x0,0x0,0x0,0x0,0x0,0x0,0x0,0x0,0x0,0x0,0x0,0x0,0x0,0x0,0x0,0x0,0x0,0x0,0x0,0x0,0x0,0x0,0x0,0x0,0x0,0x0,0x0,0x0,0x0,0x0,0x0,0x0,0x0,0x0,0x0,0x0,0x0,0x0,0x0,0x0,0x0,0x0,0x0,0x0,0x0,0x0,0x0,0x0,0x0,0x0,0x0,0x0,0x0,0x0,0x0,0x0,0x0,0x0,0x0,0x0,0x0,0x0,0x0,0x0,0x0,0x0,0x0,0x0,0x0,0x0,0x0,0x0,0x0,0x0,0x0,0x0,0x0,0x0,0x0,0x0,0x0,0x0,0x0,0x0,0x0,0x0,0x0,0x0,0x0,0x0,0x0,0x0,0x0,0x0,0x0,0x0,0x0,0x0,0x0,0x0,0x0,0x0,0x0,0x0,0x0,0x0,0x0,0x0,0x0,0x0,0x0,0x0,0x0,0x0,0x0,0x0,0x0,0x0,0x0,0x0,0x0,0x0,0x0,0x0,0x0,0x0,0x0,0x0,0x0,0x0,0x0,0x0,0x0,0x0,0x0,0x0,0x0,0x0,0x0,0x0,0x0,0x0,0x0,0x0,0x0,0x0,0x0,0x0,0x0,0x0,0x0,0x0,0x0,0x0,0x0,0x0,0x0,0x0,0x0,0x0,0x0,0x0,0x0,0x0,0x0,0x0,0x0,0x0,0x0,0x0,0x0,0x0,0x0,0x0,0x0,0x0,0x0,0x0,0x0,0x0,0x0,0x0,0x0,0x0,0x0,0x0,0x0,0x0,0x0,0x0,0x0,0x0,0x0,0x0,0x0,0x0,0x0,0x0,0x0,0x0,0x0,0x0,0x0,0x0,0x0,0x0,0x0,0x0,0x0,0x0,0x0,0x0,0x0,0x0,0x0,0x0,0x0,0x0,0x0,0x0,0x0,0x0,0x0,0x0,0x0,0x0,0x0,0x0,0x0,0x0,0x0,0x0,0x0,0x0,0x0,0x0,0x0,0x0,0x0,0x0,0x0,0x0,0x0,0x0,0x0,0x0,0x0,0x0,0x0,0x0,0x0,0x0,0x0,0x0,0x0,0x0,0x0,0x0,0x0,0x0,0x0,0x0,0x0,0x0,0x0,0x0,0x0,0x0,0x0,0x0,0x0,0x0,0x0,0x0,0x0,0x0,0x0,0x0,0x0,0x0,0x0,0x0,0x0,0x0,0x0,0x0,0x0,0x0,0x0,0x0,0x0,0x0,0x0,0x0,0x0,0x0,0x0,0x0,0x0,0x0,0x0,0x0,0x0,0x0,0x0,0x0,0x0,0x0,0x0,0x0,0x0,0x0,0x0,0x0,0x0,0x0,0x0,0x0,0x0,0x0,0x0,0x0,0x0,0x0,0x0,0x0,0x0,0x0,0x0,0x0,0x0,0x0,0x0,0x0,0x0,0x0,0x0,0x0,0x0,0x0,0x0,0x0,0x0,0x0,0x0,0x0,0x0,0x0,0x0,0x0,0x0,0x0,0x0,0x0,0x0,0x0,0x0,0x0,0x0,0x0,0x0,0x0,0x0,0x0,0x0,0x0,0x0,0x0,0x0,0x0,0x0,0x0,0x0,0x0,0x0,0x0,0x0,0x0,0x0,0x0,0x0,0x0,0x0,0x0,0x0,0x0,0x0,0x0,0x0,0x0,0x0,0x0,0x0,0x0,0x0,0x0,0x0,0x0,0x0,0x0,0x0,0x0,0x0,0x0,0x0,0x0,0x0,0x0,0x0,0x0,0x0,0x0,0x0,0x0,0x0,0x0,0x0,0x0,0x0,0x0,0x0,0x0,0x0,0x0,0x0,0x0,0x0,0x0,0x0,0x0,0x0,0x0,0x0,0x0,0x0,0x0,0x0,0x0,0x0,0x0,0x0,0x0,0x0,0x0,0x0,0x0,0x0,0x0,0x0,0x0,0x0,0x0,0x0,0x0,0x0,0x0,0x0,0x0,0x0,0x0,0x0,0x0,0x0,0x0,0x0,0x0,0x0,0x0,0x0,0x0,0x0,0x0,0x0,0x0,0x0,0x0,0x0,0x0,0x0,0x0,0x0,0x0,0x0,0x0,0x0,0x0,0x0,0x0,0x0,0x0,0x0,0x0,0x0,0x0,0x0,0x0,0x0,0x0,0x0,0x0,0x0,0x0,0x0,0x0,0x0,0x0,0x0,0x0,0x0,0x0,0x0,0x0,0x0,0x0,0x0,0x0,0x0,0x0,0x0,0x0,0x0,0x0,0x0,0x0,0x0,0x0,0x0,0x0,0x0,0x0,0x0,0x0,0x0,0x0,0x0,0x0,0x0,0x0,0x0,0x0,0x0,0x0,0x0,0x0,0x0,0x0,0x0,0x0,0x0,0x0,0x0,0x0,0x0,0x0,0x0,0x0,0x0,0x0,0x0,0x0,0x0,0x0,0x0,0x0,0x0,0x0,0x0,0x0,0x0,0x0,0x0,0x0,0x0,0x0,0x0,0x0,0x0,0x0,0x0,0x0,0x0,0x0,0x0,0x0,0x0,0x0,0x0,0x0,0x0,0x0,0x0,0x0,0x0,0x0,0x0,0x0,0x0,0x0,0x0,0x0,0x0,0x0,0x0,0x0,0x0,0x0,0x0,0x0,0x0,0x0,0x0,0x0,0x0,0x0,0x0,0x0,0x0,0x0,0x0,0x0,0x0,0x0,0x0,0x0,0x0,0x0,0x0,0x0,0x0,0x0,0x0,0x0,0x0,0x0,0x0,0x0,0x0,0x0,0x0,0x0,0x0,0x0,0x0,0x0,0x0,0x0,0x0,0x0,0x0,0x0,0x0,0x0,0x0,0x0,0x0,0x0,0x0,0x0,0x0,0x0,0x0,0x0,0x0,0x0,0x0,0x0,0x0,0x0,0x0,0x0,0x0,0x0,0x0,0x0,0x0,0x0,0x0,0x0,0x0,0x0,0x0,0x0,0x0,0x0,0x0,0x0,0x0,0x0,0x0,0x0,0x0,0x0,0x0,0x0,0x0,0x0,0x0,0x0,0x0,0x0,0x0,0x0,0x0,0x0,0x0,0x0,0x0,0x0,0x0,0x0,0x0,0x0,0x0,0x0,0x0,0x0,0x0,0x0,0x0,0x0,0x0,0x0,0x0,0x0,0x0,0x0,0x0,0x0,0x0,0x0,0x0,0x0,0x0,0x0,0x0,0x0,0x0,0x0,0x0,0x0,0x0,0x0,0x0,0x0,0x0,0x0,0x0,0x0,0x0,0x0,0x0,0x0,0x0,0x0,0x0,0x0,0x0,0x0,0x0,0x0,0x0,0x0,0x0,0x0,0x0,0x0,0x0,0x0,0x0,0x0,0x0,0x0,0x0,0x0,0x0,0x0,0x0,0x0,0x0,0x0,0x0,0x0,0x0,0x0,0x0,0x0,0x0,0x0,0x0,0x0,0x0,0x0,0x0,0x0,0x0,0x0,0x0,0x0,0x0,0x0,0x0,0x0,0x0,0x0,0x0,0x0,0x0,0x0,0x0,0x0,0x0,0x0,0x0,0x0,0x0,0x0,0x0,0x0,0x0,0x0,0x0,0x0,0x0,0x0,0x0,0x0,0x0,0x0,0x0,0x0,0x0,0x0,0x0,0x0,0x0,0x0,0x0,0x0,0x0,0x0,0x0,0x0,0x0,0x0,0x0,0x0,0x0,0x0,0x0,0x0,0x0,0x0,0x0,0x0,0x0,0x0,0x0,0x0,0x0,0x0,0x0,0x0,0x0,0x0,0x0,0x0,0x0,0x0,0x0,0x0,0x0,0x0,0x0,0x0,0x0,0x0,0x0,0x0,0x0,0x0,0x0,0x0,0x0,0x0,0x0,0x0,0x0,0x0,0x0,0x0,0x0,0x0,0x0,0x0,0x0,0x0,0x0,0x0,0x0,0x0,0x0,0x0,0x0,0x0,0x0,0x0,0x0,0x0,0x0,0x0,0x0,0x0,0x0,0x0,0x0,0x0,0x0,0x0,0x0,0x0,0x0,0x0,0x0,0x0,0x0,0x0,0x0,0x0,0x0,0x0,0x0,0x0,0x0,0x0,0x0,0x0,0x0,0x0,0x0,0x0,0x0,0x0,0x0,0x0,0x0,0x0,0x0,0x0,0x0,0x0,0x0,0x0,0x0,0x0,0x0,0x0,0x0,0x0,0x0,0x0,0x0,0x0,0x0,0x0,0x0,0x0,0x0,0x0,0x0,0x0,0x0,0x0,0x0,0x0,0x0,0x0,0x0,0x0,0x0,0x0,0x0,0x0,0x0,0x0,0x0,0x0,0x0,0x0,0x0,0x0,0x0,0x0,0x0,0x0,0x0,0x0,0x0,0x0,0x0,0x0,0x0,0x0,0x0,0x0,0x0,0x0,0x0,0x0,0x0,0x0,0x0,0x0,0x0,0x0,0x0,0x0,0x0,0x0,0x0,0x0,0x0,0x0,0x0,0x0,0x0,0x0,0x0,0x0,0x0,0x0,0x0,0x0,0x0,0x0,0x0,0x0,0x0,0x0,0x0,0x0,0x0,0x0,0x0,0x0,0x0,0x0,0x0,0x0,0x0,0x0,0x0,0x0,0x0,0x0,0x0,0x0,0x0,0x0,0x0,0x0,0x0,0x0,0x0,0x0,0x0,0x0,0x0,0x0,0x0,0x0,0x0,0x0,0x0,0x0,0x0,0x0,0x0,0x0,0x0,0x0,0x0,0x0,0x0,0x0,0x0,0x0,0x0,0x0,0x0,0x0,0x0,0x0,0x0,0x0,0x0,0x0,0x0,0x0,0x0,0x0,0x0,0x0,0x0,0x0,0x0,0x0,0x0,0x0,0x0,0x0,0x0,0x0,0x0,0x0,0x0,0x0,0x0,0x0,0x0,0x0,0x0,0x0,0x0,0x0,0x0,0x0,0x0,0x0,0x0,0x0,0x0,0x0,0x0,0x0,0x0,0x0,0x0,0x0,0x0,0x0,0x0,0x0,]

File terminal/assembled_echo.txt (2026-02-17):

[0x0,0xf,0x28,0xe2,0xfe,0x0,0xf,0x28,0xe3,0xfe,0x0,0x0,0x28,0xe1,0xfe,0x0,0x0,0x28,0x0,0x8,0x0,0xfc,0x28,0x1,0x8,0x0,0x0,0x28,0x2,0x8,0x36,0x53,0x0,0x36,0x33,0x0,0x2f,0x10,0xf,0x2e,0x3c,0x21,0x0,0x2f,0x36,0x87,0x0,0x2e,0x3b,0x21,0x0,0x31,0x33,0x0,0x0,0xb,0x28,0xe0,0xfe,0x11,0xe0,0xfe,0x3d,0x4d,0x0,0xa,0x10,0xf,0x3c,0x4d,0x0,0xa,0xc,0x1,0x3b,0x37,0x0,0x1,0xe0,0xfe,0x32,0x30,0x37,0x2f,0x33,0x31,0x0,0x0,0x28,0x0,0x8,0x0,0xfc,0x28,0x1,0x8,0x0,0xff,0x2f,0x36,0x87,0x0,0x1,0x2,0x8,0x1c,0x1,0x3c,0x63,0x0,0x0,0x0,0x28,0xe1,0xfe,0x0,0x0,0x28,0x0,0x8,0x0,0xfc,0x28,0x1,0x8,0x0,0x0,0x28,0x2,0x8,0x2e,0x30,0x32,0x2e,0x37,0x2f,0x31,0x33,0x4,0x6,0x34,0x29,0x0,0x8,0x1,0x0,0x8,0xc,0x1,0x28,0x0,0x8,0x1,0x0,0x8,0x1c,0x1f,0x10,0x19,0x3d,0xe0,0x0,0x1,0x2,0x8,0x20,0x2,0x28,0x2,0x8,0x1,0x0,0x8,0x1c,0xe0,0xc,0x20,0x28,0x0,0x8,0x1,0x1,0x8,0x14,0x0,0x28,0x1,0x8,0x2f,0x1,0x2,0x8,0x1c,0x1,0x2e,0x3c,0xc6,0x0,0x10,0xfe,0x3d,0xe0,0x0,0x0,0xfc,0x28,0x1,0x8,0x1,0x0,0x8,0x1c,0x1f,0x28,0x0,0x8,0x1,0x2,0x8,0x20,0x1,0x28,0x2,0x8,0x32,0x30,0x2e,0x37,0x0,0x0,0x0,0x0,0x0,0x0,0x0,0x0,0x0,0x0,0x0,0x0,0x0,0x0,0x0,0x0,0x0,0x0,0x0,0x0,0x0,0x0,0x0,0x0,0x0,0x0,0x0,0x0,0x0,0x0,0x0,0x0,0x0,0x0,0x0,0x0,0x0,0x0,0x0,0x0,0x0,0x0,0x0,0x0,0x0,0x0,0x0,0x0,0x0,0x0,0x0,0x0,0x0,0x0,0x0,0x0,0x0,0x0,0x0,0x0,0x0,0x0,0x0,0x0,0x0,0x0,0x0,0x0,0x0,0x0,0x0,0x0,0x0,0x0,0x0,0x0,0x0,0x0,0x0,0x0,0x0,0x0,0x0,0x0,0x0,0x0,0x0,0x0,0x0,0x0,0x0,0x0,0x0,0x0,0x0,0x0,0x0,0x0,0x0,0x0,0x0,0x0,0x0,0x0,0x0,0x0,0x0,0x0,0x0,0x0,0x0,0x0,0x0,0x0,0x0,0x0,0x0,0x0,0x0,0x0,0x0,0x0,0x0,0x0,0x0,0x0,0x0,0x0,0x0,0x0,0x0,0x0,0x0,0x0,0x0,0x0,0x0,0x0,0x0,0x0,0x0,0x0,0x0,0x0,0x0,0x0,0x0,0x0,0x0,0x0,0x0,0x0,0x0,0x0,0x0,0x0,0x0,0x0,0x0,0x0,0x0,0x0,0x0,0x0,0x0,0x0,0x0,0x0,0x0,0x0,0x0,0x0,0x0,0x0,0x0,0x0,0x0,0x0,0x0,0x0,0x0,0x0,0x0,0x0,0x0,0x0,0x0,0x0,0x0,0x0,0x0,0x0,0x0,0x0,0x0,0x0,0x0,0x0,0x0,0x0,0x0,0x0,0x0,0x0,0x0,0x0,0x0,0x0,0x0,0x0,0x0,0x0,0x0,0x0,0x0,0x0,0x0,0x0,0x0,0x0,0x0,0x0,0x0,0x0,0x0,0x0,0x0,0x0,0x0,0x0,0x0,0x0,0x0,0x0,0x0,0x0,0x0,0x0,0x0,0x0,0x0,0x0,0x0,0x0,0x0,0x0,0x0,0x0,0x0,0x0,0x0,0x0,0x0,0x0,0x0,0x0,0x0,0x0,0x0,0x0,0x0,0x0,0x0,0x0,0x0,0x0,0x0,0x0,0x0,0x0,0x0,0x0,0x0,0x0,0x0,0x0,0x0,0x0,0x0,0x0,0x0,0x0,0x0,0x0,0x0,0x0,0x0,0x0,0x0,0x0,0x0,0x0,0x0,0x0,0x0,0x0,0x0,0x0,0x0,0x0,0x0,0x0,0x0,0x0,0x0,0x0,0x0,0x0,0x0,0x0,0x0,0x0,0x0,0x0,0x0,0x0,0x0,0x0,0x0,0x0,0x0,0x0,0x0,0x0,0x0,0x0,0x0,0x0,0x0,0x0,0x0,0x0,0x0,0x0,0x0,0x0,0x0,0x0,0x0,0x0,0x0,0x0,0x0,0x0,0x0,0x0,0x0,0x0,0x0,0x0,0x0,0x0,0x0,0x0,0x0,0x0,0x0,0x0,0x0,0x0,0x0,0x0,0x0,0x0,0x0,0x0,0x0,0x0,0x0,0x0,0x0,0x0,0x0,0x0,0x0,0x0,0x0,0x0,0x0,0x0,0x0,0x0,0x0,0x0,0x0,0x0,0x0,0x0,0x0,0x0,0x0,0x0,0x0,0x0,0x0,0x0,0x0,0x0,0x0,0x0,0x0,0x0,0x0,0x0,0x0,0x0,0x0,0x0,0x0,0x0,0x0,0x0,0x0,0x0,0x0,0x0,0x0,0x0,0x0,0x0,0x0,0x0,0x0,0x0,0x0,0x0,0x0,0x0,0x0,0x0,0x0,0x0,0x0,0x0,0x0,0x0,0x0,0x0,0x0,0x0,0x0,0x0,0x0,0x0,0x0,0x0,0x0,0x0,0x0,0x0,0x0,0x0,0x0,0x0,0x0,0x0,0x0,0x0,0x0,0x0,0x0,0x0,0x0,0x0,0x0,0x0,0x0,0x0,0x0,0x0,0x0,0x0,0x0,0x0,0x0,0x0,0x0,0x0,0x0,0x0,0x0,0x0,0x0,0x0,0x0,0x0,0x0,0x0,0x0,0x0,0x0,0x0,0x0,0x0,0x0,0x0,0x0,0x0,0x0,0x0,0x0,0x0,0x0,0x0,0x0,0x0,0x0,0x0,0x0,0x0,0x0,0x0,0x0,0x0,0x0,0x0,0x0,0x0,0x0,0x0,0x0,0x0,0x0,0x0,0x0,0x0,0x0,0x0,0x0,0x0,0x0,0x0,0x0,0x0,0x0,0x0,0x0,0x0,0x0,0x0,0x0,0x0,0x0,0x0,0x0,0x0,0x0,0x0,0x0,0x0,0x0,0x0,0x0,0x0,0x0,0x0,0x0,0x0,0x0,0x0,0x0,0x0,0x0,0x0,0x0,0x0,0x0,0x0,0x0,0x0,0x0,0x0,0x0,0x0,0x0,0x0,0x0,0x0,0x0,0x0,0x0,0x0,0x0,0x0,0x0,0x0,0x0,0x0,0x0,0x0,0x0,0x0,0x0,0x0,0x0,0x0,0x0,0x0,0x0,0x0,0x0,0x0,0x0,0x0,0x0,0x0,0x0,0x0,0x0,0x0,0x0,0x0,0x0,0x0,0x0,0x0,0x0,0x0,0x0,0x0,0x0,0x0,0x0,0x0,0x0,0x0,0x0,0x0,0x0,0x0,0x0,0x0,0x0,0x0,0x0,0x0,0x0,0x0,0x0,0x0,0x0,0x0,0x0,0x0,0x0,0x0,0x0,0x0,0x0,0x0,0x0,0x0,0x0,0x0,0x0,0x0,0x0,0x0,0x0,0x0,0x0,0x0,0x0,0x0,0x0,0x0,0x0,0x0,0x0,0x0,0x0,0x0,0x0,0x0,0x0,0x0,0x0,0x0,0x0,0x0,0x0,0x0,0x0,0x0,0x0,0x0,0x0,0x0,0x0,0x0,0x0,0x0,0x0,0x0,0x0,0x0,0x0,0x0,0x0,0x0,0x0,0x0,0x0,0x0,0x0,0x0,0x0,0x0,0x0,0x0,0x0,0x0,0x0,0x0,0x0,0x0,0x0,0x0,0x0,0x0,0x0,0x0,0x0,0x0,0x0,0x0,0x0,0x0,0x0,0x0,0x0,0x0,0x0,0x0,0x0,0x0,0x0,0x0,0x0,0x0,0x0,0x0,0x0,0x0,0x0,0x0,0x0,0x0,0x0,0x0,0x0,0x0,0x0,0x0,0x0,0x0,0x0,0x0,0x0,0x0,0x0,0x0,0x0,0x0,0x0,0x0,0x0,0x0,0x0,0x0,0x0,0x0,0x0,0x0,0x0,0x0,0x0,0x0,0x0,0x0,0x0,0x0,0x0,0x0,0x0,0x0,0x0,0x0,0x0,0x0,0x0,0x0,0x0,0x0,0x0,0x0,0x0,0x0,0x0,0x0,0x0,0x0,0x0,0x0,0x0,0x0,0x0,0x0,0x0,0x0,0x0,0x0,0x0,0x0,0x0,0x0,0x0,0x0,0x0,0x0,0x0,0x0,0x0,0x0,0x0,0x0,0x0,0x0,0x0,0x0,0x0,0x0,0x0,0x0,0x0,0x0,0x0,0x0,0x0,0x0,0x0,0x0,0x0,0x0,0x0,0x0,0x0,0x0,0x0,0x0,0x0,0x0,0x0,0x0,0x0,0x0,0x0,0x0,0x0,0x0,0x0,0x0,0x0,0x0,0x0,0x0,0x0,0x0,0x0,0x0,0x0,0x0,0x0,0x0,0x0,0x0,0x0,0x0,0x0,0x0,0x0,0x0,0x0,0x0,0x0,0x0,0x0,0x0,0x0,0x0,0x0,0x0,0x0,0x0,0x0,0x0,0x0,0x0,0x0,0x0,0x0,0x0,0x0,0x0,0x0,0x0,0x0,0x0,0x0,0x0,0x0,0x0,0x0,0x0,0x0,0x0,0x0,0x0,0x0,0x0,0x0,0x0,0x0,0x0,0x0,0x0,0x0,0x0,0x0,0x0,0x0,0x0,0x0,0x0,0x0,0x0,0x0,0x0,0x0,0x0,0x0,0x0,0x0,0x0,0x0,0x0,0x0,0x0,0x0,0x0,0x0,0x0,0x0,0x0,0x0,0x0,0x0,0x0,0x0,0x0,0x0,0x0,0x0,0x0,0x0,0x0,0x0,0x0,0x0,0x0,0x0,0x0,0x0,0x0,0x0,0x0,0x0,0x0,0x0,0x0,0x0,0x0,0x0,0x0,0x0,0x0,0x0,0x0,0x0,0x0,0x0,0x0,0x0,0x0,0x0,0x0,0x0,0x0,0x0,0x0,0x0,0x0,0x0,0x0,0x0,0x0,0x0,0x0,0x0,0x0,0x0,0x0,0x0,0x0,0x0,0x0,0x0,0x0,0x0,0x0,0x0,0x0,0x0,0x0,0x0,0x0,0x0,0x0,0x0,0x0,0x0,0x0,0x0,0x0,0x0,0x0,0x0,0x0,0x0,0x0,0x0,0x0,0x0,0x0,0x0,0x0,0x0,0x0,0x0,0x0,0x0,0x0,0x0,0x0,0x0,0x0,0x0,0x0,0x0,0x0,0x0,0x0,0x0,0x0,0x0,0x0,0x0,0x0,0x0,0x0,0x0,0x0,0x0,0x0,0x0,0x0,0x0,0x0,0x0,0x0,0x0,0x0,0x0,0x0,0x0,0x0,0x0,0x0,0x0,0x0,0x0,0x0,0x0,0x0,0x0,0x0,0x0,0x0,0x0,0x0,0x0,0x0,0x0,0x0,0x0,0x0,0x0,0x0,0x0,0x0,0x0,0x0,0x0,0x0,0x0,0x0,0x0,0x0,0x0,0x0,0x0,0x0,0x0,0x0,0x0,0x0,0x0,0x0,0x0,0x0,0x0,0x0,0x0,0x0,0x0,0x0,0x0,0x0,0x0,0x0,0x0,0x0,0x0,0x0,0x0,0x0,0x0,0x0,0x0,0x0,0x0,0x0,0x0,0x0,0x0,0x0,0x0,0x0,0x0,0x0,0x0,0x0,0x0,0x0,0x0,0x0,0x0,0x0,0x0,0x0,0x0,0x0,0x0,0x0,0x0,0x0,0x0,0x0,0x0,0x0,0x0,0x0,0x0,0x0,0x0,0x0,0x0,0x0,0x0,0x0,0x0,0x0,0x0,0x0,0x0,0x0,0x0,0x0,0x0,0x0,0x0,0x0,0x0,0x0,0x0,0x0,0x0,0x0,0x0,0x0,0x0,0x0,0x0,0x0,0x0,0x0,0x0,0x0,0x0,0x0,0x0,0x0,0x0,0x0,0x0,0x0,0x0,0x0,0x0,0x0,0x0,0x0,0x0,0x0,0x0,0x0,0x0,0x0,0x0,0x0,0x0,0x0,0x0,0x0,0x0,0x0,0x0,0x0,0x0,0x0,0x0,0x0,0x0,0x0,0x0,0x0,0x0,0x0,0x0,0x0,0x0,0x0,0x0,0x0,0x0,0x0,0x0,0x0,0x0,0x0,0x0,0x0,0x0,0x0,0x0,0x0,0x0,0x0,0x0,0x0,0x0,0x0,0x0,0x0,0x0,0x0,0x0,0x0,0x0,0x0,0x0,0x0,0x0,0x0,0x0,0x0,0x0,0x0,0x0,0x0,0x0,0x0,0x0,0x0,0x0,0x0,0x0,0x0,0x0,0x0,0x0,0x0,0x0,0x0,0x0,0x0,0x0,0x0,0x0,0x0,0x0,0x0,0x0,0x0,0x0,0x0,0x0,0x0,0x0,0x0,0x0,0x0,0x0,0x0,0x0,0x0,0x0,0x0,0x0,0x0,0x0,0x0,0x0,0x0,0x0,0x0,0x0,0x0,0x0,0x0,0x0,0x0,0x0,0x0,0x0,0x0,0x0,0x0,0x0,0x0,0x0,0x0,0x0,0x0,0x0,0x0,0x0,0x0,0x0,0x0,0x0,0x0,0x0,0x0,0x0,0x0,0x0,0x0,0x0,0x0,0x0,0x0,0x0,0x0,0x0,0x0,0x0,0x0,0x0,0x0,0x0,0x0,0x0,0x0,0x0,0x0,0x0,0x0,0x0,0x0,0x0,0x0,0x0,0x0,0x0,0x0,0x0,0x0,0x0,0x0,0x0,0x0,0x0,0x0,0x0,0x0,0x0,0x0,0x0,0x0,0x0,0x0,0x0,0x0,0x0,0x0,0x0,0x0,0x0,0x0,0x0,0x0,0x0,0x0,0x0,0x0,0x0,0x0,0x0,0x0,0x0,0x0,0x0,0x0,0x0,0x0,0x0,0x0,0x0,0x0,0x0,0x0,0x0,0x0,0x0,0x0,0x0,0x0,0x0,0x0,0x0,0x0,0x0,0x0,0x0,0x0,0x0,0x0,0x0,0x0,0x0,0x0,0x0,0x0,0x0,0x0,0x0,0x0,0x0,0x0,0x0,0x0,0x0,0x0,0x0,0x0,0x0,0x0,0x0,0x0,0x0,0x0,0x0,0x0,0x0,0x0,0x0,0x0,0x0,0x0,0x0,0x0,0x0,0x0,0x0,0x0,0x0,0x0,0x0,0x0,0x0,0x0,0x0,0x0,0x0,0x0,0x0,0x0,0x0,0x0,0x0,0x0,0x0,0x0,0x0,0x0,0x0,0x0,0x0,0x0,0x0,0x0,0x0,0x0,0x0,0x0,0x0,0x0,0x0,0x0,0x0,0x0,0x0,0x0,0x0,0x0,0x0,0x0,0x0,0x0,0x0,0x0,0x0,0x0,0x0,0x0,0x0,0x0,0x0,0x0,0x0,0x0,0x0,0x0,0x0,0x0,0x0,0x0,0x0,0x0,0x0,0x0,0x0,0x0,0x0,0x0,0x0,0x0,0x0,0x0,0x0,0x0,0x0,0x0,0x0,0x0,0x0,0x0,0x0,0x0,0x0,0x0,0x0,0x0,0x0,0x0,0x0,0x0,0x0,0x0,0x0,0x0,0x0,0x0,0x0,0x0,0x0,0x0,0x0,0x0,0x0,0x0,0x0,0x0,0x0,0x0,0x0,0x0,0x0,0x0,0x0,0x0,0x0,0x0,0x0,0x0,0x0,0x0,0x0,0x0,0x0,0x0,0x0,0x0,0x0,0x0,0x0,0x0,0x0,0x0,0x0,0x0,0x0,0x0,0x0,0x0,0x0,0x0,0x0,0x0,0x0,0x0,0x0,0x0,0x0,0x0,0x0,0x0,0x0,0x0,0x0,0x0,0x0,0x0,0x0,0x0,0x0,0x0,0x0,0x0,0x0,0x0,0x0,0x0,0x0,0x0,0x0,0x0,0x0,0x0,0x0,0x0,0x0,0x0,0x0,0x0,0x0,0x0,0x0,0x0,0x0,0x0,0x0,0x0,0x0,0x0,0x0,0x0,0x0,0x0,0x0,0x0,0x0,0x0,0x0,0x0,0x0,0x0,0x0,0x0,0x0,0x0,0x0,0x0,0x0,0x0,0x0,0x0,0x0,0x0,0x0,0x0,0x0,0x0,0x0,0x0,0x0,0x0,0x0,0x0,0x0,0x0,0x0,0x0,0x0,0x0,0x0,0x0,0x0,0x0,0x0,0x0,0x0,0x0,0x0,0x0,0x0,0x0,0x0,0x0,0x0,0x0,0x0,0x0,0x0,0x0,0x0,0x0,0x0,0x0,0x0,0x0,0x0,0x0,0x0,0x0,0x0,0x0,0x0,0x0,0x0,0x0,0x0,0x0,0x0,0x0,0x0,0x0,0x0,0x0,0x0,0x0,0x0,0x0,0x0,0x0,0x0,0x0,0x0,0x0,0x0,0x0,0x0,0x0,0x0,0x0,0x0,0x0,0x0,0x0,0x0,0x0,0x0,0x0,0x0,0x0,0x0,0x0,0x0,0x0,0x0,0x0,0x0,0x0,0x0,0x0,0x0,0x0,0x0,0x0,]

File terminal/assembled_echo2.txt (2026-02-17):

[0x0,0xf,0x28,0xe2,0xfe,0x0,0xf,0x28,0xe3,0xfe,0x0,0x0,0x28,0xe1,0xfe,0x0,0xff,0x28,0xf2,0xfe,0x28,0xf3,0xfe,0x0,0xf,0x28,0x2,0x8,0x28,0x3,0x8,0x36,0xe8,0x0,0x2,0x0,0x8,0x28,0x4,0x8,0x0,0xf,0x29,0x0,0x8,0x36,0x7e,0x0,0x1,0x3,0x8,0x10,0xf,0x3c,0x69,0x0,0x1,0x3,0x8,0x11,0x2,0x8,0x3c,0x69,0x0,0x1,0x3,0x8,0x10,0x89,0x3d,0x63,0x0,0x1,0x4,0x8,0x29,0x0,0x8,0x36,0xd9,0x0,0x36,0x42,0x1,0x2,0x0,0x8,0x28,0x4,0x8,0x0,0xf,0x29,0x0,0x8,0x3b,0x69,0x0,0x1,0x3,0x8,0x36,0xa4,0x0,0x1,0x3,0x8,0x28,0x2,0x8,0x1,0x0,0x8,0x28,0xf0,0xfe,0x1,0x1,0x8,0x28,0xf1,0xfe,0x3b,0x2d,0x0,0x31,0x33,0x2f,0x0,0x0,0xb,0x28,0xe0,0xfe,0x1,0xe0,0xfe,0x28,0x3,0x8,0xa,0x11,0x3,0x8,0x3d,0xa0,0x0,0xa,0x10,0xf,0x3c,0xa0,0x0,0xa,0xc,0x1,0x3b,0x83,0x0,0x2e,0x32,0x30,0x37,0x31,0x33,0x2f,0x29,0x0,0x8,0x1,0x0,0x8,0xc,0x1,0x28,0x0,0x8,0x1,0x1,0x8,0x14,0x0,0x28,0x1,0x8,0x1,0x0,0x8,0x1c,0x1f,0x10,0x19,0x3d,0xca,0x0,0x36,0xd9,0x0,0x36,0x42,0x1,0x2,0x0,0x8,0x28,0x4,0x8,0x0,0xf,0x29,0x0,0x8,0x2e,0x32,0x30,0x37,0x33,0x31,0x2f,0x1,0x0,0x8,0x1c,0xe0,0x28,0x0,0x8,0x2e,0x30,0x32,0x37,0x33,0x31,0x2f,0x0,0x0,0x28,0x0,0x8,0x0,0xfc,0x28,0x1,0x8,0x0,0x17,0x29,0x0,0x8,0x1,0x0,0x8,0xc,0x1,0x28,0x0,0x8,0x1,0x1,0x8,0x14,0x0,0x28,0x1,0x8,0x1,0x0,0x8,0x1c,0x1f,0x10,0x19,0x3d,0xf5,0x0,0x36,0xd9,0x0,0x1,0x0,0x8,0xc,0x20,0x28,0x0,0x8,0x1,0x1,0x8,0x14,0x0,0x28,0x1,0x8,0x1,0x1,0x8,0x10,0xfe,0x3d,0xf5,0x0,0x0,0x0,0x28,0x0,0x8,0x0,0xfc,0x28,0x1,0x8,0x0,0x0,0x28,0x5,0x8,0x2e,0x30,0x32,0x37,0x2f,0x33,0x31,0x1,0x0,0x8,0xc,0x20,0x28,0x0,0x8,0x1,0x1,0x8,0x14,0x0,0x28,0x1,0x8,0x1,0x1,0x8,0x10,0xfe,0x3d,0x6c,0x1,0x0,0x0,0x28,0x0,0x8,0x0,0xfc,0x28,0x1,0x8,0x0,0x1,0x28,0x5,0x8,0x36,0x73,0x1,0x30,0x32,0x2e,0x37,0x2f,0x33,0x31,0x1,0x5,0x8,0x10,0x1,0x3d,0xa7,0x1,0x5,0xe1,0xfe,0x8,0x2b,0xe1,0xfe,0x0,0x17,0x29,0x0,0x8,0x1,0x0,0x8,0xc,0x1,0x28,0x0,0x8,0x1,0x1,0x8,0x14,0x0,0x28,0x1,0x8,0x1,0x0,0x8,0x1c,0x1f,0x10,0x19,0x3d,0x85,0x1,0x36,0xd9,0x0,0x30,0x32,0x2e,0x37,0x0,0x0,0x0,0x0,0x0,0x0,0x0,0x0,0x0,0x0,0x0,0x0,0x0,0x0,0x0,0x0,0x0,0x0,0x0,0x0,0x0,0x0,0x0,0x0,0x0,0x0,0x0,0x0,0x0,0x0,0x0,0x0,0x0,0x0,0x0,0x0,0x0,0x0,0x0,0x0,0x0,0x0,0x0,0x0,0x0,0x0,0x0,0x0,0x0,0x0,0x0,0x0,0x0,0x0,0x0,0x0,0x0,0x0,0x0,0x0,0x0,0x0,0x0,0x0,0x0,0x0,0x0,0x0,0x0,0x0,0x0,0x0,0x0,0x0,0x0,0x0,0x0,0x0,0x0,0x0,0x0,0x0,0x0,0x0,0x0,0x0,0x0,0x0,0x0,0x0,0x0,0x0,0x0,0x0,0x0,0x0,0x0,0x0,0x0,0x0,0x0,0x0,0x0,0x0,0x0,0x0,0x0,0x0,0x0,0x0,0x0,0x0,0x0,0x0,0x0,0x0,0x0,0x0,0x0,0x0,0x0,0x0,0x0,0x0,0x0,0x0,0x0,0x0,0x0,0x0,0x0,0x0,0x0,0x0,0x0,0x0,0x0,0x0,0x0,0x0,0x0,0x0,0x0,0x0,0x0,0x0,0x0,0x0,0x0,0x0,0x0,0x0,0x0,0x0,0x0,0x0,0x0,0x0,0x0,0x0,0x0,0x0,0x0,0x0,0x0,0x0,0x0,0x0,0x0,0x0,0x0,0x0,0x0,0x0,0x0,0x0,0x0,0x0,0x0,0x0,0x0,0x0,0x0,0x0,0x0,0x0,0x0,0x0,0x0,0x0,0x0,0x0,0x0,0x0,0x0,0x0,0x0,0x0,0x0,0x0,0x0,0x0,0x0,0x0,0x0,0x0,0x0,0x0,0x0,0x0,0x0,0x0,0x0,0x0,0x0,0x0,0x0,0x0,0x0,0x0,0x0,0x0,0x0,0x0,0x0,0x0,0x0,0x0,0x0,0x0,0x0,0x0,0x0,0x0,0x0,0x0,0x0,0x0,0x0,0x0,0x0,0x0,0x0,0x0,0x0,0x0,0x0,0x0,0x0,0x0,0x0,0x0,0x0,0x0,0x0,0x0,0x0,0x0,0x0,0x0,0x0,0x0,0x0,0x0,0x0,0x0,0x0,0x0,0x0,0x0,0x0,0x0,0x0,0x0,0x0,0x0,0x0,0x0,0x0,0x0,0x0,0x0,0x0,0x0,0x0,0x0,0x0,0x0,0x0,0x0,0x0,0x0,0x0,0x0,0x0,0x0,0x0,0x0,0x0,0x0,0x0,0x0,0x0,0x0,0x0,0x0,0x0,0x0,0x0,0x0,0x0,0x0,0x0,0x0,0x0,0x0,0x0,0x0,0x0,0x0,0x0,0x0,0x0,0x0,0x0,0x0,0x0,0x0,0x0,0x0,0x0,0x0,0x0,0x0,0x0,0x0,0x0,0x0,0x0,0x0,0x0,0x0,0x0,0x0,0x0,0x0,0x0,0x0,0x0,0x0,0x0,0x0,0x0,0x0,0x0,0x0,0x0,0x0,0x0,0x0,0x0,0x0,0x0,0x0,0x0,0x0,0x0,0x0,0x0,0x0,0x0,0x0,0x0,0x0,0x0,0x0,0x0,0x0,0x0,0x0,0x0,0x0,0x0,0x0,0x0,0x0,0x0,0x0,0x0,0x0,0x0,0x0,0x0,0x0,0x0,0x0,0x0,0x0,0x0,0x0,0x0,0x0,0x0,0x0,0x0,0x0,0x0,0x0,0x0,0x0,0x0,0x0,0x0,0x0,0x0,0x0,0x0,0x0,0x0,0x0,0x0,0x0,0x0,0x0,0x0,0x0,0x0,0x0,0x0,0x0,0x0,0x0,0x0,0x0,0x0,0x0,0x0,0x0,0x0,0x0,0x0,0x0,0x0,0x0,0x0,0x0,0x0,0x0,0x0,0x0,0x0,0x0,0x0,0x0,0x0,0x0,0x0,0x0,0x0,0x0,0x0,0x0,0x0,0x0,0x0,0x0,0x0,0x0,0x0,0x0,0x0,0x0,0x0,0x0,0x0,0x0,0x0,0x0,0x0,0x0,0x0,0x0,0x0,0x0,0x0,0x0,0x0,0x0,0x0,0x0,0x0,0x0,0x0,0x0,0x0,0x0,0x0,0x0,0x0,0x0,0x0,0x0,0x0,0x0,0x0,0x0,0x0,0x0,0x0,0x0,0x0,0x0,0x0,0x0,0x0,0x0,0x0,0x0,0x0,0x0,0x0,0x0,0x0,0x0,0x0,0x0,0x0,0x0,0x0,0x0,0x0,0x0,0x0,0x0,0x0,0x0,0x0,0x0,0x0,0x0,0x0,0x0,0x0,0x0,0x0,0x0,0x0,0x0,0x0,0x0,0x0,0x0,0x0,0x0,0x0,0x0,0x0,0x0,0x0,0x0,0x0,0x0,0x0,0x0,0x0,0x0,0x0,0x0,0x0,0x0,0x0,0x0,0x0,0x0,0x0,0x0,0x0,0x0,0x0,0x0,0x0,0x0,0x0,0x0,0x0,0x0,0x0,0x0,0x0,0x0,0x0,0x0,0x0,0x0,0x0,0x0,0x0,0x0,0x0,0x0,0x0,0x0,0x0,0x0,0x0,0x0,0x0,0x0,0x0,0x0,0x0,0x0,0x0,0x0,0x0,0x0,0x0,0x0,0x0,0x0,0x0,0x0,0x0,0x0,0x0,0x0,0x0,0x0,0x0,0x0,0x0,0x0,0x0,0x0,0x0,0x0,0x0,0x0,0x0,0x0,0x0,0x0,0x0,0x0,0x0,0x0,0x0,0x0,0x0,0x0,0x0,0x0,0x0,0x0,0x0,0x0,0x0,0x0,0x0,0x0,0x0,0x0,0x0,0x0,0x0,0x0,0x0,0x0,0x0,0x0,0x0,0x0,0x0,0x0,0x0,0x0,0x0,0x0,0x0,0x0,0x0,0x0,0x0,0x0,0x0,0x0,0x0,0x0,0x0,0x0,0x0,0x0,0x0,0x0,0x0,0x0,0x0,0x0,0x0,0x0,0x0,0x0,0x0,0x0,0x0,0x0,0x0,0x0,0x0,0x0,0x0,0x0,0x0,0x0,0x0,0x0,0x0,0x0,0x0,0x0,0x0,0x0,0x0,0x0,0x0,0x0,0x0,0x0,0x0,0x0,0x0,0x0,0x0,0x0,0x0,0x0,0x0,0x0,0x0,0x0,0x0,0x0,0x0,0x0,0x0,0x0,0x0,0x0,0x0,0x0,0x0,0x0,0x0,0x0,0x0,0x0,0x0,0x0,0x0,0x0,0x0,0x0,0x0,0x0,0x0,0x0,0x0,0x0,0x0,0x0,0x0,0x0,0x0,0x0,0x0,0x0,0x0,0x0,0x0,0x0,0x0,0x0,0x0,0x0,0x0,0x0,0x0,0x0,0x0,0x0,0x0,0x0,0x0,0x0,0x0,0x0,0x0,0x0,0x0,0x0,0x0,0x0,0x0,0x0,0x0,0x0,0x0,0x0,0x0,0x0,0x0,0x0,0x0,0x0,0x0,0x0,0x0,0x0,0x0,0x0,0x0,0x0,0x0,0x0,0x0,0x0,0x0,0x0,0x0,0x0,0x0,0x0,0x0,0x0,0x0,0x0,0x0,0x0,0x0,0x0,0x0,0x0,0x0,0x0,0x0,0x0,0x0,0x0,0x0,0x0,0x0,0x0,0x0,0x0,0x0,0x0,0x0,0x0,0x0,0x0,0x0,0x0,0x0,0x0,0x0,0x0,0x0,0x0,0x0,0x0,0x0,0x0,0x0,0x0,0x0,0x0,0x0,0x0,0x0,0x0,0x0,0x0,0x0,0x0,0x0,0x0,0x0,0x0,0x0,0x0,0x0,0x0,0x0,0x0,0x0,0x0,0x0,0x0,0x0,0x0,0x0,0x0,0x0,0x0,0x0,0x0,0x0,0x0,0x0,0x0,0x0,0x0,0x0,0x0,0x0,0x0,0x0,0x0,0x0,0x0,0x0,0x0,0x0,0x0,0x0,0x0,0x0,0x0,0x0,0x0,0x0,0x0,0x0,0x0,0x0,0x0,0x0,0x0,0x0,0x0,0x0,0x0,0x0,0x0,0x0,0x0,0x0,0x0,0x0,0x0,0x0,0x0,0x0,0x0,0x0,0x0,0x0,0x0,0x0,0x0,0x0,0x0,0x0,0x0,0x0,0x0,0x0,0x0,0x0,0x0,0x0,0x0,0x0,0x0,0x0,0x0,0x0,0x0,0x0,0x0,0x0,0x0,0x0,0x0,0x0,0x0,0x0,0x0,0x0,0x0,0x0,0x0,0x0,0x0,0x0,0x0,0x0,0x0,0x0,0x0,0x0,0x0,0x0,0x0,0x0,0x0,0x0,0x0,0x0,0x0,0x0,0x0,0x0,0x0,0x0,0x0,0x0,0x0,0x0,0x0,0x0,0x0,0x0,0x0,0x0,0x0,0x0,0x0,0x0,0x0,0x0,0x0,0x0,0x0,0x0,0x0,0x0,0x0,0x0,0x0,0x0,0x0,0x0,0x0,0x0,0x0,0x0,0x0,0x0,0x0,0x0,0x0,0x0,0x0,0x0,0x0,0x0,0x0,0x0,0x0,0x0,0x0,0x0,0x0,0x0,0x0,0x0,0x0,0x0,0x0,0x0,0x0,0x0,0x0,0x0,0x0,0x0,0x0,0x0,0x0,0x0,0x0,0x0,0x0,0x0,0x0,0x0,0x0,0x0,0x0,0x0,0x0,0x0,0x0,0x0,0x0,0x0,0x0,0x0,0x0,0x0,0x0,0x0,0x0,0x0,0x0,0x0,0x0,0x0,0x0,0x0,0x0,0x0,0x0,0x0,0x0,0x0,0x0,0x0,0x0,0x0,0x0,0x0,0x0,0x0,0x0,0x0,0x0,0x0,0x0,0x0,0x0,0x0,0x0,0x0,0x0,0x0,0x0,0x0,0x0,0x0,0x0,0x0,0x0,0x0,0x0,0x0,0x0,0x0,0x0,0x0,0x0,0x0,0x0,0x0,0x0,0x0,0x0,0x0,0x0,0x0,0x0,0x0,0x0,0x0,0x0,0x0,0x0,0x0,0x0,0x0,0x0,0x0,0x0,0x0,0x0,0x0,0x0,0x0,0x0,0x0,0x0,0x0,0x0,0x0,0x0,0x0,0x0,0x0,0x0,0x0,0x0,0x0,0x0,0x0,0x0,0x0,0x0,0x0,0x0,0x0,0x0,0x0,0x0,0x0,0x0,0x0,0x0,0x0,0x0,0x0,0x0,0x0,0x0,0x0,0x0,0x0,0x0,0x0,0x0,0x0,0x0,0x0,0x0,0x0,0x0,0x0,0x0,0x0,0x0,0x0,0x0,0x0,0x0,0x0,0x0,0x0,0x0,0x0,0x0,0x0,0x0,0x0,0x0,0x0,0x0,0x0,0x0,0x0,0x0,0x0,0x0,0x0,0x0,0x0,0x0,0x0,0x0,0x0,0x0,0x0,0x0,0x0,0x0,0x0,0x0,0x0,0x0,0x0,0x0,0x0,0x0,0x0,0x0,0x0,0x0,0x0,0x0,0x0,0x0,0x0,0x0,0x0,0x0,0x0,0x0,0x0,0x0,0x0,0x0,0x0,0x0,0x0,0x0,0x0,0x0,0x0,0x0,0x0,0x0,0x0,0x0,0x0,0x0,0x0,0x0,0x0,0x0,0x0,0x0,0x0,0x0,0x0,0x0,0x0,0x0,0x0,0x0,0x0,0x0,0x0,0x0,0x0,0x0,0x0,0x0,0x0,0x0,0x0,0x0,0x0,0x0,0x0,0x0,0x0,0x0,0x0,0x0,0x0,0x0,0x0,0x0,0x0,0x0,0x0,0x0,0x0,0x0,0x0,0x0,0x0,0x0,0x0,0x0,0x0,0x0,0x0,0x0,0x0,0x0,0x0,0x0,0x0,0x0,0x0,0x0,0x0,0x0,0x0,0x0,0x0,0x0,0x0,0x0,0x0,0x0,0x0,0x0,0x0,0x0,0x0,0x0,0x0,0x0,0x0,0x0,0x0,0x0,0x0,0x0,0x0,0x0,0x0,0x0,0x0,0x0,0x0,0x0,0x0,0x0,0x0,0x0,0x0,0x0,0x0,0x0,0x0,0x0,0x0,0x0,0x0,0x0,0x0,0x0,0x0,0x0,0x0,0x0,0x0,0x0,0x0,0x0,0x0,0x0,0x0,0x0,0x0,0x0,0x0,0x0,0x0,0x0,0x0,0x0,0x0,0x0,0x0,0x0,0x0,0x0,0x0,0x0,0x0,0x0,0x0,0x0,0x0,0x0,0x0,0x0,0x0,0x0,0x0,0x0,0x0,0x0,0x0,0x0,0x0,0x0,0x0,0x0,0x0,0x0,0x0,0x0,0x0,0x0,0x0,0x0,0x0,0x0,0x0,0x0,0x0,0x0,0x0,0x0,0x0,0x0,0x0,0x0,0x0,0x0,0x0,0x0,0x0,0x0,0x0,0x0,0x0,0x0,0x0,0x0,0x0,0x0,0x0,0x0,0x0,0x0,0x0,0x0,0x0,0x0,0x0,0x0,0x0,0x0,0x0,0x0,0x0,0x0,0x0,0x0,0x0,0x0,0x0,0x0,0x0,0x0,0x0,0x0,0x0,0x0,0x0,0x0,0x0,0x0,0x0,0x0,0x0,0x0,0x0,0x0,0x0,0x0,0x0,0x0,0x0,0x0,0x0,0x0,0x0,0x0,0x0,0x0,0x0,0x0,0x0,0x0,0x0,0x0,0x0,0x0,0x0,0x0,0x0,0x0,0x0,0x0,0x0,0x0,0x0,0x0,0x0,0x0,0x0,0x0,0x0,0x0,0x0,0x0,0x0,0x0,0x0,0x0,0x0,0x0,0x0,0x0,0x0,0x0,0x0,0x0,0x0,0x0,0x0,0x0,0x0,0x0,0x0,0x0,0x0,0x0,0x0,0x0,0x0,0x0,0x0,0x0,0x0,0x0,0x0,0x0,0x0,0x0,0x0,0x0,0x0,0x0,0x0,0x0,0x0,0x0,0x0,0x0,0x0,0x0,0x0,0x0,0x0,]

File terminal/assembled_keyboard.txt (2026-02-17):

[0x0,0xf,0x28,0xe2,0xfe,0x0,0xff,0x28,0xe3,0xfe,0x36,0x16,0x0,0x36,0x36,0x0,0x28,0xe1,0xfe,0x3b,0xa,0x0,0x31,0x33,0x0,0x0,0xb,0x28,0xe0,0xfe,0x11,0xe0,0xfe,0x3d,0x30,0x0,0xa,0x10,0xf,0x3c,0x30,0x0,0xa,0xc,0x1,0x3b,0x1a,0x0,0x1,0xe0,0xfe,0x32,0x30,0x37,0x31,0x33,0x4,0x0,0x2f,0x13,0x4f,0x0,0x2e,0x3c,0x4b,0x0,0x2f,0x8,0xa,0x10,0x1a,0x2e,0x3d,0x3a,0x0,0xa,0x32,0x30,0x37,17,22,66,65,64,129,21,37,132,69,133,25,70,38,24,40,16,128,33,20,68,130,32,34,36,18,255,0x0,0x0,0x0,0x0,0x0,0x0,0x0,0x0,0x0,0x0,0x0,0x0,0x0,0x0,0x0,0x0,0x0,0x0,0x0,0x0,0x0,0x0,0x0,0x0,0x0,0x0,0x0,0x0,0x0,0x0,0x0,0x0,0x0,0x0,0x0,0x0,0x0,0x0,0x0,0x0,0x0,0x0,0x0,0x0,0x0,0x0,0x0,0x0,0x0,0x0,0x0,0x0,0x0,0x0,0x0,0x0,0x0,0x0,0x0,0x0,0x0,0x0,0x0,0x0,0x0,0x0,0x0,0x0,0x0,0x0,0x0,0x0,0x0,0x0,0x0,0x0,0x0,0x0,0x0,0x0,0x0,0x0,0x0,0x0,0x0,0x0,0x0,0x0,0x0,0x0,0x0,0x0,0x0,0x0,0x0,0x0,0x0,0x0,0x0,0x0,0x0,0x0,0x0,0x0,0x0,0x0,0x0,0x0,0x0,0x0,0x0,0x0,0x0,0x0,0x0,0x0,0x0,0x0,0x0,0x0,0x0,0x0,0x0,0x0,0x0,0x0,0x0,0x0,0x0,0x0,0x0,0x0,0x0,0x0,0x0,0x0,0x0,0x0,0x0,0x0,0x0,0x0,0x0,0x0,0x0,0x0,0x0,0x0,0x0,0x0,0x0,0x0,0x0,0x0,0x0,0x0,0x0,0x0,0x0,0x0,0x0,0x0,0x0,0x0,0x0,0x0,0x0,0x0,0x0,0x0,0x0,0x0,0x0,0x0,0x0,0x0,0x0,0x0,0x0,0x0,0x0,0x0,0x0,0x0,0x0,0x0,0x0,0x0,0x0,0x0,0x0,0x0,0x0,0x0,0x0,0x0,0x0,0x0,0x0,0x0,0x0,0x0,0x0,0x0,0x0,0x0,0x0,0x0,0x0,0x0,0x0,0x0,0x0,0x0,0x0,0x0,0x0,0x0,0x0,0x0,0x0,0x0,0x0,0x0,0x0,0x0,0x0,0x0,0x0,0x0,0x0,0x0,0x0,0x0,0x0,0x0,0x0,0x0,0x0,0x0,0x0,0x0,0x0,0x0,0x0,0x0,0x0,0x0,0x0,0x0,0x0,0x0,0x0,0x0,0x0,0x0,0x0,0x0,0x0,0x0,0x0,0x0,0x0,0x0,0x0,0x0,0x0,0x0,0x0,0x0,0x0,0x0,0x0,0x0,0x0,0x0,0x0,0x0,0x0,0x0,0x0,0x0,0x0,0x0,0x0,0x0,0x0,0x0,0x0,0x0,0x0,0x0,0x0,0x0,0x0,0x0,0x0,0x0,0x0,0x0,0x0,0x0,0x0,0x0,0x0,0x0,0x0,0x0,0x0,0x0,0x0,0x0,0x0,0x0,0x0,0x0,0x0,0x0,0x0,0x0,0x0,0x0,0x0,0x0,0x0,0x0,0x0,0x0,0x0,0x0,0x0,0x0,0x0,0x0,0x0,0x0,0x0,0x0,0x0,0x0,0x0,0x0,0x0,0x0,0x0,0x0,0x0,0x0,0x0,0x0,0x0,0x0,0x0,0x0,0x0,0x0,0x0,0x0,0x0,0x0,0x0,0x0,0x0,0x0,0x0,0x0,0x0,0x0,0x0,0x0,0x0,0x0,0x0,0x0,0x0,0x0,0x0,0x0,0x0,0x0,0x0,0x0,0x0,0x0,0x0,0x0,0x0,0x0,0x0,0x0,0x0,0x0,0x0,0x0,0x0,0x0,0x0,0x0,0x0,0x0,0x0,0x0,0x0,0x0,0x0,0x0,0x0,0x0,0x0,0x0,0x0,0x0,0x0,0x0,0x0,0x0,0x0,0x0,0x0,0x0,0x0,0x0,0x0,0x0,0x0,0x0,0x0,0x0,0x0,0x0,0x0,0x0,0x0,0x0,0x0,0x0,0x0,0x0,0x0,0x0,0x0,0x0,0x0,0x0,0x0,0x0,0x0,0x0,0x0,0x0,0x0,0x0,0x0,0x0,0x0,0x0,0x0,0x0,0x0,0x0,0x0,0x0,0x0,0x0,0x0,0x0,0x0,0x0,0x0,0x0,0x0,0x0,0x0,0x0,0x0,0x0,0x0,0x0,0x0,0x0,0x0,0x0,0x0,0x0,0x0,0x0,0x0,0x0,0x0,0x0,0x0,0x0,0x0,0x0,0x0,0x0,0x0,0x0,0x0,0x0,0x0,0x0,0x0,0x0,0x0,0x0,0x0,0x0,0x0,0x0,0x0,0x0,0x0,0x0,0x0,0x0,0x0,0x0,0x0,0x0,0x0,0x0,0x0,0x0,0x0,0x0,0x0,0x0,0x0,0x0,0x0,0x0,0x0,0x0,0x0,0x0,0x0,0x0,0x0,0x0,0x0,0x0,0x0,0x0,0x0,0x0,0x0,0x0,0x0,0x0,0x0,0x0,0x0,0x0,0x0,0x0,0x0,0x0,0x0,0x0,0x0,0x0,0x0,0x0,0x0,0x0,0x0,0x0,0x0,0x0,0x0,0x0,0x0,0x0,0x0,0x0,0x0,0x0,0x0,0x0,0x0,0x0,0x0,0x0,0x0,0x0,0x0,0x0,0x0,0x0,0x0,0x0,0x0,0x0,0x0,0x0,0x0,0x0,0x0,0x0,0x0,0x0,0x0,0x0,0x0,0x0,0x0,0x0,0x0,0x0,0x0,0x0,0x0,0x0,0x0,0x0,0x0,0x0,0x0,0x0,0x0,0x0,0x0,0x0,0x0,0x0,0x0,0x0,0x0,0x0,0x0,0x0,0x0,0x0,0x0,0x0,0x0,0x0,0x0,0x0,0x0,0x0,0x0,0x0,0x0,0x0,0x0,0x0,0x0,0x0,0x0,0x0,0x0,0x0,0x0,0x0,0x0,0x0,0x0,0x0,0x0,0x0,0x0,0x0,0x0,0x0,0x0,0x0,0x0,0x0,0x0,0x0,0x0,0x0,0x0,0x0,0x0,0x0,0x0,0x0,0x0,0x0,0x0,0x0,0x0,0x0,0x0,0x0,0x0,0x0,0x0,0x0,0x0,0x0,0x0,0x0,0x0,0x0,0x0,0x0,0x0,0x0,0x0,0x0,0x0,0x0,0x0,0x0,0x0,0x0,0x0,0x0,0x0,0x0,0x0,0x0,0x0,0x0,0x0,0x0,0x0,0x0,0x0,0x0,0x0,0x0,0x0,0x0,0x0,0x0,0x0,0x0,0x0,0x0,0x0,0x0,0x0,0x0,0x0,0x0,0x0,0x0,0x0,0x0,0x0,0x0,0x0,0x0,0x0,0x0,0x0,0x0,0x0,0x0,0x0,0x0,0x0,0x0,0x0,0x0,0x0,0x0,0x0,0x0,0x0,0x0,0x0,0x0,0x0,0x0,0x0,0x0,0x0,0x0,0x0,0x0,0x0,0x0,0x0,0x0,0x0,0x0,0x0,0x0,0x0,0x0,0x0,0x0,0x0,0x0,0x0,0x0,0x0,0x0,0x0,0x0,0x0,0x0,0x0,0x0,0x0,0x0,0x0,0x0,0x0,0x0,0x0,0x0,0x0,0x0,0x0,0x0,0x0,0x0,0x0,0x0,0x0,0x0,0x0,0x0,0x0,0x0,0x0,0x0,0x0,0x0,0x0,0x0,0x0,0x0,0x0,0x0,0x0,0x0,0x0,0x0,0x0,0x0,0x0,0x0,0x0,0x0,0x0,0x0,0x0,0x0,0x0,0x0,0x0,0x0,0x0,0x0,0x0,0x0,0x0,0x0,0x0,0x0,0x0,0x0,0x0,0x0,0x0,0x0,0x0,0x0,0x0,0x0,0x0,0x0,0x0,0x0,0x0,0x0,0x0,0x0,0x0,0x0,0x0,0x0,0x0,0x0,0x0,0x0,0x0,0x0,0x0,0x0,0x0,0x0,0x0,0x0,0x0,0x0,0x0,0x0,0x0,0x0,0x0,0x0,0x0,0x0,0x0,0x0,0x0,0x0,0x0,0x0,0x0,0x0,0x0,0x0,0x0,0x0,0x0,0x0,0x0,0x0,0x0,0x0,0x0,0x0,0x0,0x0,0x0,0x0,0x0,0x0,0x0,0x0,0x0,0x0,0x0,0x0,0x0,0x0,0x0,0x0,0x0,0x0,0x0,0x0,0x0,0x0,0x0,0x0,0x0,0x0,0x0,0x0,0x0,0x0,0x0,0x0,0x0,0x0,0x0,0x0,0x0,0x0,0x0,0x0,0x0,0x0,0x0,0x0,0x0,0x0,0x0,0x0,0x0,0x0,0x0,0x0,0x0,0x0,0x0,0x0,0x0,0x0,0x0,0x0,0x0,0x0,0x0,0x0,0x0,0x0,0x0,0x0,0x0,0x0,0x0,0x0,0x0,0x0,0x0,0x0,0x0,0x0,0x0,0x0,0x0,0x0,0x0,0x0,0x0,0x0,0x0,0x0,0x0,0x0,0x0,0x0,0x0,0x0,0x0,0x0,0x0,0x0,0x0,0x0,0x0,0x0,0x0,0x0,0x0,0x0,0x0,0x0,0x0,0x0,0x0,0x0,0x0,0x0,0x0,0x0,0x0,0x0,0x0,0x0,0x0,0x0,0x0,0x0,0x0,0x0,0x0,0x0,0x0,0x0,0x0,0x0,0x0,0x0,0x0,0x0,0x0,0x0,0x0,0x0,0x0,0x0,0x0,0x0,0x0,0x0,0x0,0x0,0x0,0x0,0x0,0x0,0x0,0x0,0x0,0x0,0x0,0x0,0x0,0x0,0x0,0x0,0x0,0x0,0x0,0x0,0x0,0x0,0x0,0x0,0x0,0x0,0x0,0x0,0x0,0x0,0x0,0x0,0x0,0x0,0x0,0x0,0x0,0x0,0x0,0x0,0x0,0x0,0x0,0x0,0x0,0x0,0x0,0x0,0x0,0x0,0x0,0x0,0x0,0x0,0x0,0x0,0x0,0x0,0x0,0x0,0x0,0x0,0x0,0x0,0x0,0x0,0x0,0x0,0x0,0x0,0x0,0x0,0x0,0x0,0x0,0x0,0x0,0x0,0x0,0x0,0x0,0x0,0x0,0x0,0x0,0x0,0x0,0x0,0x0,0x0,0x0,0x0,0x0,0x0,0x0,0x0,0x0,0x0,0x0,0x0,0x0,0x0,0x0,0x0,0x0,0x0,0x0,0x0,0x0,0x0,0x0,0x0,0x0,0x0,0x0,0x0,0x0,0x0,0x0,0x0,0x0,0x0,0x0,0x0,0x0,0x0,0x0,0x0,0x0,0x0,0x0,0x0,0x0,0x0,0x0,0x0,0x0,0x0,0x0,0x0,0x0,0x0,0x0,0x0,0x0,0x0,0x0,0x0,0x0,0x0,0x0,0x0,0x0,0x0,0x0,0x0,0x0,0x0,0x0,0x0,0x0,0x0,0x0,0x0,0x0,0x0,0x0,0x0,0x0,0x0,0x0,0x0,0x0,0x0,0x0,0x0,0x0,0x0,0x0,0x0,0x0,0x0,0x0,0x0,0x0,0x0,0x0,0x0,0x0,0x0,0x0,0x0,0x0,0x0,0x0,0x0,0x0,0x0,0x0,0x0,0x0,0x0,0x0,0x0,0x0,0x0,0x0,0x0,0x0,0x0,0x0,0x0,0x0,0x0,0x0,0x0,0x0,0x0,0x0,0x0,0x0,0x0,0x0,0x0,0x0,0x0,0x0,0x0,0x0,0x0,0x0,0x0,0x0,0x0,0x0,0x0,0x0,0x0,0x0,0x0,0x0,0x0,0x0,0x0,0x0,0x0,0x0,0x0,0x0,0x0,0x0,0x0,0x0,0x0,0x0,0x0,0x0,0x0,0x0,0x0,0x0,0x0,0x0,0x0,0x0,0x0,0x0,0x0,0x0,0x0,0x0,0x0,0x0,0x0,0x0,0x0,0x0,0x0,0x0,0x0,0x0,0x0,0x0,0x0,0x0,0x0,0x0,0x0,0x0,0x0,0x0,0x0,0x0,0x0,0x0,0x0,0x0,0x0,0x0,0x0,0x0,0x0,0x0,0x0,0x0,0x0,0x0,0x0,0x0,0x0,0x0,0x0,0x0,0x0,0x0,0x0,0x0,0x0,0x0,0x0,0x0,0x0,0x0,0x0,0x0,0x0,0x0,0x0,0x0,0x0,0x0,0x0,0x0,0x0,0x0,0x0,0x0,0x0,0x0,0x0,0x0,0x0,0x0,0x0,0x0,0x0,0x0,0x0,0x0,0x0,0x0,0x0,0x0,0x0,0x0,0x0,0x0,0x0,0x0,0x0,0x0,0x0,0x0,0x0,0x0,0x0,0x0,0x0,0x0,0x0,0x0,0x0,0x0,0x0,0x0,0x0,0x0,0x0,0x0,0x0,0x0,0x0,0x0,0x0,0x0,0x0,0x0,0x0,0x0,0x0,0x0,0x0,0x0,0x0,0x0,0x0,0x0,0x0,0x0,0x0,0x0,0x0,0x0,0x0,0x0,0x0,0x0,0x0,0x0,0x0,0x0,0x0,0x0,0x0,0x0,0x0,0x0,0x0,0x0,0x0,0x0,0x0,0x0,0x0,0x0,0x0,0x0,0x0,0x0,0x0,0x0,0x0,0x0,0x0,0x0,0x0,0x0,0x0,0x0,0x0,0x0,0x0,0x0,0x0,0x0,0x0,0x0,0x0,0x0,0x0,0x0,0x0,0x0,0x0,0x0,0x0,0x0,0x0,0x0,0x0,0x0,0x0,0x0,0x0,0x0,0x0,0x0,0x0,0x0,0x0,0x0,0x0,0x0,0x0,0x0,0x0,0x0,0x0,0x0,0x0,0x0,0x0,0x0,0x0,0x0,0x0,0x0,0x0,0x0,0x0,0x0,0x0,0x0,0x0,0x0,0x0,0x0,0x0,0x0,0x0,0x0,0x0,0x0,0x0,0x0,0x0,0x0,0x0,0x0,0x0,0x0,0x0,0x0,0x0,0x0,0x0,0x0,0x0,0x0,0x0,0x0,0x0,0x0,0x0,0x0,0x0,0x0,0x0,0x0,0x0,0x0,0x0,0x0,0x0,0x0,0x0,0x0,0x0,0x0,0x0,0x0,0x0,0x0,0x0,0x0,0x0,0x0,0x0,0x0,0x0,0x0,0x0,0x0,0x0,0x0,0x0,0x0,0x0,0x0,0x0,0x0,0x0,0x0,0x0,0x0,0x0,0x0,0x0,0x0,0x0,0x0,0x0,0x0,0x0,0x0,0x0,0x0,0x0,0x0,0x0,0x0,0x0,0x0,0x0,0x0,0x0,0x0,0x0,0x0,0x0,0x0,0x0,0x0,0x0,0x0,0x0,0x0,0x0,0x0,0x0,0x0,0x0,0x0,0x0,0x0,0x0,0x0,0x0,0x0,0x0,0x0,0x0,0x0,0x0,0x0,0x0,0x0,0x0,0x0,0x0,0x0,0x0,0x0,0x0,0x0,0x0,0x0,0x0,0x0,0x0,0x0,0x0,0x0,0x0,0x0,0x0,0x0,0x0,0x0,0x0,0x0,0x0,0x0,0x0,0x0,0x0,0x0,0x0,0x0,0x0,0x0,0x0,0x0,0x0,0x0,0x0,0x0,0x0,0x0,0x0,0x0,0x0,0x0,0x0,0x0,0x0,0x0,0x0,0x0,0x0,0x0,0x0,0x0,0x0,0x0,0x0,0x0,0x0,0x0,0x0,0x0,0x0,0x0,0x0,0x0,0x0,0x0,0x0,0x0,0x0,0x0,0x0,0x0,0x0,0x0,0x0,0x0,0x0,0x0,0x0,0x0,0x0,0x0,0x0,0x0,0x0,0x0,0x0,0x0,0x0,0x0,0x0,0x0,0x0,0x0,0x0,0x0,0x0,0x0,0x0,0x0,0x0,0x0,0x0,0x0,0x0,0x0,0x0,0x0,0x0,0x0,0x0,0x0,0x0,0x0,0x0,0x0,0x0,0x0,0x0,0x0,0x0,0x0,0x0,0x0,0x0,0x0,0x0,0x0,0x0,0x0,0x0,0x0,0x0,0x0,0x0,0x0,0x0,0x0,0x0,0x0,0x0,0x0,0x0,0x0,0x0,0x0,0x0,0x0,0x0,0x0,0x0,0x0,0x0,0x0,0x0,0x0,0x0,0x0,0x0,0x0,0x0,0x0,0x0,0x0,0x0,0x0,0x0,0x0,0x0,0x0,0x0,0x0,0x0,0x0,0x0,0x0,0x0,0x0,0x0,0x0,0x0,0x0,0x0,0x0,0x0,0x0,0x0,0x0,0x0,0x0,0x0,0x0,0x0,0x0,0x0,0x0,0x0,0x0,0x0,0x0,0x0,0x0,0x0,0x0,0x0,0x0,0x0,0x0,0x0,0x0,0x0,0x0,0x0,0x0,0x0,0x0,0x0,0x0,0x0,0x0,0x0,0x0,0x0,0x0,0x0,0x0,0x0,0x0,0x0,0x0,0x0,0x0,0x0,0x0,0x0,0x0,0x0,0x0,0x0,0x0,0x0,0x0,0x0,0x0,0x0,0x0,0x0,0x0,0x0,0x0,0x0,0x0,0x0,]

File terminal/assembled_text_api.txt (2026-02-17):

[0x0,0xf,0x28,0xe3,0xfe,0x0,0x0,0x28,0xe1,0xfe,0x0,0x0,0x28,0x0,0x8,0x0,0xfc,0x28,0x1,0x8,0x0,0x0,0x28,0x2,0x8,0x36,0x42,0x0,0x0,0x0,0x2f,0x36,0x67,0x0,0x2e,0x0,0x11,0x2f,0x36,0x67,0x0,0x2e,0x0,0x9,0x2f,0x36,0x67,0x0,0x2e,0x0,0x14,0x2f,0x36,0x67,0x0,0x2e,0x0,0xd,0x2f,0x36,0x67,0x0,0x2e,0x3b,0x1c,0x0,0x2f,0x33,0x31,0x0,0x0,0x28,0x0,0x8,0x0,0xfc,0x28,0x1,0x8,0x0,0xff,0x2f,0x36,0x67,0x0,0x1,0x2,0x8,0x1c,0x1,0x3c,0x52,0x0,0x0,0x0,0x28,0xe1,0xfe,0x2e,0x30,0x32,0x2e,0x37,0x2f,0x31,0x33,0x4,0x6,0x34,0x29,0x0,0x8,0x1,0x0,0x8,0xc,0x1,0x28,0x0,0x8,0x1,0x0,0x8,0x1c,0x1f,0x10,0x19,0x3d,0xca,0x0,0x1,0x2,0x8,0x20,0x2,0x28,0x2,0x8,0x1,0x0,0x8,0x1c,0xe0,0xc,0x20,0x28,0x0,0x8,0x1,0x1,0x8,0x14,0x0,0x28,0x1,0x8,0x2f,0x1,0x2,0x8,0x1c,0x1,0x2e,0x3c,0xb0,0x0,0x2f,0x1,0xe1,0xfe,0x10,0x1,0x28,0xe1,0xfe,0x2e,0x10,0xfe,0x3d,0xca,0x0,0x0,0xfc,0x28,0x1,0x8,0x1,0x0,0x8,0x1c,0x1f,0x28,0x0,0x8,0x1,0x2,0x8,0x20,0x1,0x28,0x2,0x8,0x32,0x30,0x2e,0x37,0x3b,0xce,0x0,0x0,0x0,0x0,0x0,0x0,0x0,0x0,0x0,0x0,0x0,0x0,0x0,0x0,0x0,0x0,0x0,0x0,0x0,0x0,0x0,0x0,0x0,0x0,0x0,0x0,0x0,0x0,0x0,0x0,0x0,0x0,0x0,0x0,0x0,0x0,0x0,0x0,0x0,0x0,0x0,0x0,0x0,0x0,0x0,0x0,0x0,0x0,0x0,0x0,0x0,0x0,0x0,0x0,0x0,0x0,0x0,0x0,0x0,0x0,0x0,0x0,0x0,0x0,0x0,0x0,0x0,0x0,0x0,0x0,0x0,0x0,0x0,0x0,0x0,0x0,0x0,0x0,0x0,0x0,0x0,0x0,0x0,0x0,0x0,0x0,0x0,0x0,0x0,0x0,0x0,0x0,0x0,0x0,0x0,0x0,0x0,0x0,0x0,0x0,0x0,0x0,0x0,0x0,0x0,0x0,0x0,0x0,0x0,0x0,0x0,0x0,0x0,0x0,0x0,0x0,0x0,0x0,0x0,0x0,0x0,0x0,0x0,0x0,0x0,0x0,0x0,0x0,0x0,0x0,0x0,0x0,0x0,0x0,0x0,0x0,0x0,0x0,0x0,0x0,0x0,0x0,0x0,0x0,0x0,0x0,0x0,0x0,0x0,0x0,0x0,0x0,0x0,0x0,0x0,0x0,0x0,0x0,0x0,0x0,0x0,0x0,0x0,0x0,0x0,0x0,0x0,0x0,0x0,0x0,0x0,0x0,0x0,0x0,0x0,0x0,0x0,0x0,0x0,0x0,0x0,0x0,0x0,0x0,0x0,0x0,0x0,0x0,0x0,0x0,0x0,0x0,0x0,0x0,0x0,0x0,0x0,0x0,0x0,0x0,0x0,0x0,0x0,0x0,0x0,0x0,0x0,0x0,0x0,0x0,0x0,0x0,0x0,0x0,0x0,0x0,0x0,0x0,0x0,0x0,0x0,0x0,0x0,0x0,0x0,0x0,0x0,0x0,0x0,0x0,0x0,0x0,0x0,0x0,0x0,0x0,0x0,0x0,0x0,0x0,0x0,0x0,0x0,0x0,0x0,0x0,0x0,0x0,0x0,0x0,0x0,0x0,0x0,0x0,0x0,0x0,0x0,0x0,0x0,0x0,0x0,0x0,0x0,0x0,0x0,0x0,0x0,0x0,0x0,0x0,0x0,0x0,0x0,0x0,0x0,0x0,0x0,0x0,0x0,0x0,0x0,0x0,0x0,0x0,0x0,0x0,0x0,0x0,0x0,0x0,0x0,0x0,0x0,0x0,0x0,0x0,0x0,0x0,0x0,0x0,0x0,0x0,0x0,0x0,0x0,0x0,0x0,0x0,0x0,0x0,0x0,0x0,0x0,0x0,0x0,0x0,0x0,0x0,0x0,0x0,0x0,0x0,0x0,0x0,0x0,0x0,0x0,0x0,0x0,0x0,0x0,0x0,0x0,0x0,0x0,0x0,0x0,0x0,0x0,0x0,0x0,0x0,0x0,0x0,0x0,0x0,0x0,0x0,0x0,0x0,0x0,0x0,0x0,0x0,0x0,0x0,0x0,0x0,0x0,0x0,0x0,0x0,0x0,0x0,0x0,0x0,0x0,0x0,0x0,0x0,0x0,0x0,0x0,0x0,0x0,0x0,0x0,0x0,0x0,0x0,0x0,0x0,0x0,0x0,0x0,0x0,0x0,0x0,0x0,0x0,0x0,0x0,0x0,0x0,0x0,0x0,0x0,0x0,0x0,0x0,0x0,0x0,0x0,0x0,0x0,0x0,0x0,0x0,0x0,0x0,0x0,0x0,0x0,0x0,0x0,0x0,0x0,0x0,0x0,0x0,0x0,0x0,0x0,0x0,0x0,0x0,0x0,0x0,0x0,0x0,0x0,0x0,0x0,0x0,0x0,0x0,0x0,0x0,0x0,0x0,0x0,0x0,0x0,0x0,0x0,0x0,0x0,0x0,0x0,0x0,0x0,0x0,0x0,0x0,0x0,0x0,0x0,0x0,0x0,0x0,0x0,0x0,0x0,0x0,0x0,0x0,0x0,0x0,0x0,0x0,0x0,0x0,0x0,0x0,0x0,0x0,0x0,0x0,0x0,0x0,0x0,0x0,0x0,0x0,0x0,0x0,0x0,0x0,0x0,0x0,0x0,0x0,0x0,0x0,0x0,0x0,0x0,0x0,0x0,0x0,0x0,0x0,0x0,0x0,0x0,0x0,0x0,0x0,0x0,0x0,0x0,0x0,0x0,0x0,0x0,0x0,0x0,0x0,0x0,0x0,0x0,0x0,0x0,0x0,0x0,0x0,0x0,0x0,0x0,0x0,0x0,0x0,0x0,0x0,0x0,0x0,0x0,0x0,0x0,0x0,0x0,0x0,0x0,0x0,0x0,0x0,0x0,0x0,0x0,0x0,0x0,0x0,0x0,0x0,0x0,0x0,0x0,0x0,0x0,0x0,0x0,0x0,0x0,0x0,0x0,0x0,0x0,0x0,0x0,0x0,0x0,0x0,0x0,0x0,0x0,0x0,0x0,0x0,0x0,0x0,0x0,0x0,0x0,0x0,0x0,0x0,0x0,0x0,0x0,0x0,0x0,0x0,0x0,0x0,0x0,0x0,0x0,0x0,0x0,0x0,0x0,0x0,0x0,0x0,0x0,0x0,0x0,0x0,0x0,0x0,0x0,0x0,0x0,0x0,0x0,0x0,0x0,0x0,0x0,0x0,0x0,0x0,0x0,0x0,0x0,0x0,0x0,0x0,0x0,0x0,0x0,0x0,0x0,0x0,0x0,0x0,0x0,0x0,0x0,0x0,0x0,0x0,0x0,0x0,0x0,0x0,0x0,0x0,0x0,0x0,0x0,0x0,0x0,0x0,0x0,0x0,0x0,0x0,0x0,0x0,0x0,0x0,0x0,0x0,0x0,0x0,0x0,0x0,0x0,0x0,0x0,0x0,0x0,0x0,0x0,0x0,0x0,0x0,0x0,0x0,0x0,0x0,0x0,0x0,0x0,0x0,0x0,0x0,0x0,0x0,0x0,0x0,0x0,0x0,0x0,0x0,0x0,0x0,0x0,0x0,0x0,0x0,0x0,0x0,0x0,0x0,0x0,0x0,0x0,0x0,0x0,0x0,0x0,0x0,0x0,0x0,0x0,0x0,0x0,0x0,0x0,0x0,0x0,0x0,0x0,0x0,0x0,0x0,0x0,0x0,0x0,0x0,0x0,0x0,0x0,0x0,0x0,0x0,0x0,0x0,0x0,0x0,0x0,0x0,0x0,0x0,0x0,0x0,0x0,0x0,0x0,0x0,0x0,0x0,0x0,0x0,0x0,0x0,0x0,0x0,0x0,0x0,0x0,0x0,0x0,0x0,0x0,0x0,0x0,0x0,0x0,0x0,0x0,0x0,0x0,0x0,0x0,0x0,0x0,0x0,0x0,0x0,0x0,0x0,0x0,0x0,0x0,0x0,0x0,0x0,0x0,0x0,0x0,0x0,0x0,0x0,0x0,0x0,0x0,0x0,0x0,0x0,0x0,0x0,0x0,0x0,0x0,0x0,0x0,0x0,0x0,0x0,0x0,0x0,0x0,0x0,0x0,0x0,0x0,0x0,0x0,0x0,0x0,0x0,0x0,0x0,0x0,0x0,0x0,0x0,0x0,0x0,0x0,0x0,0x0,0x0,0x0,0x0,0x0,0x0,0x0,0x0,0x0,0x0,0x0,0x0,0x0,0x0,0x0,0x0,0x0,0x0,0x0,0x0,0x0,0x0,0x0,0x0,0x0,0x0,0x0,0x0,0x0,0x0,0x0,0x0,0x0,0x0,0x0,0x0,0x0,0x0,0x0,0x0,0x0,0x0,0x0,0x0,0x0,0x0,0x0,0x0,0x0,0x0,0x0,0x0,0x0,0x0,0x0,0x0,0x0,0x0,0x0,0x0,0x0,0x0,0x0,0x0,0x0,0x0,0x0,0x0,0x0,0x0,0x0,0x0,0x0,0x0,0x0,0x0,0x0,0x0,0x0,0x0,0x0,0x0,0x0,0x0,0x0,0x0,0x0,0x0,0x0,0x0,0x0,0x0,0x0,0x0,0x0,0x0,0x0,0x0,0x0,0x0,0x0,0x0,0x0,0x0,0x0,0x0,0x0,0x0,0x0,0x0,0x0,0x0,0x0,0x0,0x0,0x0,0x0,0x0,0x0,0x0,0x0,0x0,0x0,0x0,0x0,0x0,0x0,0x0,0x0,0x0,0x0,0x0,0x0,0x0,0x0,0x0,0x0,0x0,0x0,0x0,0x0,0x0,0x0,0x0,0x0,0x0,0x0,0x0,0x0,0x0,0x0,0x0,0x0,0x0,0x0,0x0,0x0,0x0,0x0,0x0,0x0,0x0,0x0,0x0,0x0,0x0,0x0,0x0,0x0,0x0,0x0,0x0,0x0,0x0,0x0,0x0,0x0,0x0,0x0,0x0,0x0,0x0,0x0,0x0,0x0,0x0,0x0,0x0,0x0,0x0,0x0,0x0,0x0,0x0,0x0,0x0,0x0,0x0,0x0,0x0,0x0,0x0,0x0,0x0,0x0,0x0,0x0,0x0,0x0,0x0,0x0,0x0,0x0,0x0,0x0,0x0,0x0,0x0,0x0,0x0,0x0,0x0,0x0,0x0,0x0,0x0,0x0,0x0,0x0,0x0,0x0,0x0,0x0,0x0,0x0,0x0,0x0,0x0,0x0,0x0,0x0,0x0,0x0,0x0,0x0,0x0,0x0,0x0,0x0,0x0,0x0,0x0,0x0,0x0,0x0,0x0,0x0,0x0,0x0,0x0,0x0,0x0,0x0,0x0,0x0,0x0,0x0,0x0,0x0,0x0,0x0,0x0,0x0,0x0,0x0,0x0,0x0,0x0,0x0,0x0,0x0,0x0,0x0,0x0,0x0,0x0,0x0,0x0,0x0,0x0,0x0,0x0,0x0,0x0,0x0,0x0,0x0,0x0,0x0,0x0,0x0,0x0,0x0,0x0,0x0,0x0,0x0,0x0,0x0,0x0,0x0,0x0,0x0,0x0,0x0,0x0,0x0,0x0,0x0,0x0,0x0,0x0,0x0,0x0,0x0,0x0,0x0,0x0,0x0,0x0,0x0,0x0,0x0,0x0,0x0,0x0,0x0,0x0,0x0,0x0,0x0,0x0,0x0,0x0,0x0,0x0,0x0,0x0,0x0,0x0,0x0,0x0,0x0,0x0,0x0,0x0,0x0,0x0,0x0,0x0,0x0,0x0,0x0,0x0,0x0,0x0,0x0,0x0,0x0,0x0,0x0,0x0,0x0,0x0,0x0,0x0,0x0,0x0,0x0,0x0,0x0,0x0,0x0,0x0,0x0,0x0,0x0,0x0,0x0,0x0,0x0,0x0,0x0,0x0,0x0,0x0,0x0,0x0,0x0,0x0,0x0,0x0,0x0,0x0,0x0,0x0,0x0,0x0,0x0,0x0,0x0,0x0,0x0,0x0,0x0,0x0,0x0,0x0,0x0,0x0,0x0,0x0,0x0,0x0,0x0,0x0,0x0,0x0,0x0,0x0,0x0,0x0,0x0,0x0,0x0,0x0,0x0,0x0,0x0,0x0,0x0,0x0,0x0,0x0,0x0,0x0,0x0,0x0,0x0,0x0,0x0,0x0,0x0,0x0,0x0,0x0,0x0,0x0,0x0,0x0,0x0,0x0,0x0,0x0,0x0,0x0,0x0,0x0,0x0,0x0,0x0,0x0,0x0,0x0,0x0,0x0,0x0,0x0,0x0,0x0,0x0,0x0,0x0,0x0,0x0,0x0,0x0,0x0,0x0,0x0,0x0,0x0,0x0,0x0,0x0,0x0,0x0,0x0,0x0,0x0,0x0,0x0,0x0,0x0,0x0,0x0,0x0,0x0,0x0,0x0,0x0,0x0,0x0,0x0,0x0,0x0,0x0,0x0,0x0,0x0,0x0,0x0,0x0,0x0,0x0,0x0,0x0,0x0,0x0,0x0,0x0,0x0,0x0,0x0,0x0,0x0,0x0,0x0,0x0,0x0,0x0,0x0,0x0,0x0,0x0,0x0,0x0,0x0,0x0,0x0,0x0,0x0,0x0,0x0,0x0,0x0,0x0,0x0,0x0,0x0,0x0,0x0,0x0,0x0,0x0,0x0,0x0,0x0,0x0,0x0,0x0,0x0,0x0,0x0,0x0,0x0,0x0,0x0,0x0,0x0,0x0,0x0,0x0,0x0,0x0,0x0,0x0,0x0,0x0,0x0,0x0,0x0,0x0,0x0,0x0,0x0,0x0,0x0,0x0,0x0,0x0,0x0,0x0,0x0,0x0,0x0,0x0,0x0,0x0,0x0,0x0,0x0,0x0,0x0,0x0,0x0,0x0,0x0,0x0,0x0,0x0,0x0,0x0,0x0,0x0,0x0,0x0,0x0,0x0,0x0,0x0,0x0,0x0,0x0,0x0,0x0,0x0,0x0,0x0,0x0,0x0,0x0,0x0,0x0,0x0,0x0,0x0,0x0,0x0,0x0,0x0,0x0,0x0,0x0,0x0,0x0,0x0,0x0,0x0,0x0,0x0,0x0,0x0,0x0,0x0,0x0,0x0,0x0,0x0,0x0,0x0,0x0,0x0,0x0,0x0,0x0,0x0,0x0,0x0,0x0,0x0,0x0,0x0,0x0,0x0,0x0,0x0,0x0,0x0,0x0,0x0,0x0,0x0,0x0,0x0,0x0,0x0,0x0,0x0,0x0,0x0,0x0,0x0,0x0,0x0,0x0,0x0,0x0,0x0,0x0,0x0,0x0,0x0,0x0,0x0,0x0,0x0,0x0,0x0,0x0,0x0,0x0,0x0,0x0,0x0,0x0,0x0,0x0,0x0,0x0,0x0,0x0,0x0,0x0,0x0,0x0,0x0,0x0,0x0,0x0,0x0,0x0,0x0,0x0,0x0,0x0,0x0,0x0,0x0,0x0,0x0,0x0,0x0,0x0,0x0,0x0,0x0,0x0,0x0,0x0,0x0,0x0,0x0,0x0,0x0,0x0,0x0,0x0,0x0,0x0,0x0,0x0,0x0,0x0,0x0,0x0,0x0,0x0,0x0,0x0,0x0,0x0,0x0,0x0,0x0,0x0,0x0,0x0,0x0,0x0,0x0,0x0,0x0,0x0,0x0,0x0,0x0,0x0,0x0,0x0,0x0,0x0,0x0,0x0,0x0,0x0,0x0,0x0,0x0,0x0,0x0,0x0,0x0,0x0,0x0,0x0,0x0,0x0,0x0,0x0,0x0,0x0,0x0,0x0,0x0,0x0,0x0,0x0,0x0,0x0,0x0,0x0,0x0,0x0,0x0,0x0,0x0,0x0,0x0,0x0,0x0,0x0,0x0,0x0,0x0,0x0,0x0,0x0,0x0,0x0,0x0,0x0,0x0,0x0,0x0,0x0,0x0,0x0,0x0,0x0,0x0,0x0,0x0,0x0,0x0,0x0,0x0,0x0,0x0,0x0,0x0,0x0,0x0,0x0,0x0,0x0,0x0,0x0,0x0,0x0,0x0,0x0,0x0,0x0,0x0,0x0,0x0,0x0,0x0,0x0,0x0,0x0,0x0,0x0,0x0,0x0,0x0,0x0,0x0,0x0,0x0,0x0,0x0,0x0,0x0,0x0,0x0,0x0,0x0,0x0,0x0,0x0,0x0,0x0,0x0,0x0,0x0,0x0,0x0,0x0,0x0,0x0,0x0,0x0,0x0,0x0,0x0,0x0,0x0,0x0,0x0,0x0,0x0,0x0,0x0,0x0,0x0,0x0,0x0,0x0,0x0,0x0,0x0,0x0,0x0,0x0,0x0,0x0,0x0,0x0,0x0,0x0,0x0,0x0,0x0,0x0,0x0,0x0,0x0,0x0,0x0,0x0,0x0,0x0,0x0,0x0,0x0,0x0,0x0,0x0,0x0,0x0,0x0,0x0,0x0,0x0,0x0,0x0,0x0,0x0,0x0,0x0,0x0,0x0,0x0,0x0,0x0,0x0,0x0,0x0,0x0,0x0,0x0,0x0,0x0,0x0,0x0,0x0,0x0,0x0,0x0,0x0,0x0,0x0,0x0,0x0,]

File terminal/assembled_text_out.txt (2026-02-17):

[0x0,0x0,0x28,0x0,0x8,0x0,0xfc,0x28,0x1,0x8,0x0,0xff,0x29,0x0,0x8,0x1,0x0,0x8,0xc,0x1,0x28,0x0,0x8,0x1,0x0,0x8,0x1c,0x1f,0x10,0x19,0x3d,0xa,0x0,0x1,0x0,0x8,0x1c,0xe0,0xc,0x20,0x28,0x0,0x8,0x1,0x1,0x8,0x14,0x0,0x28,0x1,0x8,0x10,0xfe,0x3d,0xa,0x0,0x0,0xfc,0x28,0x1,0x8,0x1,0x0,0x8,0x1c,0x1f,0x28,0x0,0x8,0x3b,0x48,0x0,0x0,0x0,0x28,0x0,0xfc,0x0,0x11,0x28,0x1,0xfc,0x0,0x9,0x28,0x2,0xfc,0x0,0x14,0x28,0x3,0xfc,0x0,0xd,0x28,0x4,0xfc,0x3b,0x61,0x0,0x0,0x0,0x0,0x0,0x0,0x0,0x0,0x0,0x0,0x0,0x0,0x0,0x0,0x0,0x0,0x0,0x0,0x0,0x0,0x0,0x0,0x0,0x0,0x0,0x0,0x0,0x0,0x0,0x0,0x0,0x0,0x0,0x0,0x0,0x0,0x0,0x0,0x0,0x0,0x0,0x0,0x0,0x0,0x0,0x0,0x0,0x0,0x0,0x0,0x0,0x0,0x0,0x0,0x0,0x0,0x0,0x0,0x0,0x0,0x0,0x0,0x0,0x0,0x0,0x0,0x0,0x0,0x0,0x0,0x0,0x0,0x0,0x0,0x0,0x0,0x0,0x0,0x0,0x0,0x0,0x0,0x0,0x0,0x0,0x0,0x0,0x0,0x0,0x0,0x0,0x0,0x0,0x0,0x0,0x0,0x0,0x0,0x0,0x0,0x0,0x0,0x0,0x0,0x0,0x0,0x0,0x0,0x0,0x0,0x0,0x0,0x0,0x0,0x0,0x0,0x0,0x0,0x0,0x0,0x0,0x0,0x0,0x0,0x0,0x0,0x0,0x0,0x0,0x0,0x0,0x0,0x0,0x0,0x0,0x0,0x0,0x0,0x0,0x0,0x0,0x0,0x0,0x0,0x0,0x0,0x0,0x0,0x0,0x0,0x0,0x0,0x0,0x0,0x0,0x0,0x0,0x0,0x0,0x0,0x0,0x0,0x0,0x0,0x0,0x0,0x0,0x0,0x0,0x0,0x0,0x0,0x0,0x0,0x0,0x0,0x0,0x0,0x0,0x0,0x0,0x0,0x0,0x0,0x0,0x0,0x0,0x0,0x0,0x0,0x0,0x0,0x0,0x0,0x0,0x0,0x0,0x0,0x0,0x0,0x0,0x0,0x0,0x0,0x0,0x0,0x0,0x0,0x0,0x0,0x0,0x0,0x0,0x0,0x0,0x0,0x0,0x0,0x0,0x0,0x0,0x0,0x0,0x0,0x0,0x0,0x0,0x0,0x0,0x0,0x0,0x0,0x0,0x0,0x0,0x0,0x0,0x0,0x0,0x0,0x0,0x0,0x0,0x0,0x0,0x0,0x0,0x0,0x0,0x0,0x0,0x0,0x0,0x0,0x0,0x0,0x0,0x0,0x0,0x0,0x0,0x0,0x0,0x0,0x0,0x0,0x0,0x0,0x0,0x0,0x0,0x0,0x0,0x0,0x0,0x0,0x0,0x0,0x0,0x0,0x0,0x0,0x0,0x0,0x0,0x0,0x0,0x0,0x0,0x0,0x0,0x0,0x0,0x0,0x0,0x0,0x0,0x0,0x0,0x0,0x0,0x0,0x0,0x0,0x0,0x0,0x0,0x0,0x0,0x0,0x0,0x0,0x0,0x0,0x0,0x0,0x0,0x0,0x0,0x0,0x0,0x0,0x0,0x0,0x0,0x0,0x0,0x0,0x0,0x0,0x0,0x0,0x0,0x0,0x0,0x0,0x0,0x0,0x0,0x0,0x0,0x0,0x0,0x0,0x0,0x0,0x0,0x0,0x0,0x0,0x0,0x0,0x0,0x0,0x0,0x0,0x0,0x0,0x0,0x0,0x0,0x0,0x0,0x0,0x0,0x0,0x0,0x0,0x0,0x0,0x0,0x0,0x0,0x0,0x0,0x0,0x0,0x0,0x0,0x0,0x0,0x0,0x0,0x0,0x0,0x0,0x0,0x0,0x0,0x0,0x0,0x0,0x0,0x0,0x0,0x0,0x0,0x0,0x0,0x0,0x0,0x0,0x0,0x0,0x0,0x0,0x0,0x0,0x0,0x0,0x0,0x0,0x0,0x0,0x0,0x0,0x0,0x0,0x0,0x0,0x0,0x0,0x0,0x0,0x0,0x0,0x0,0x0,0x0,0x0,0x0,0x0,0x0,0x0,0x0,0x0,0x0,0x0,0x0,0x0,0x0,0x0,0x0,0x0,0x0,0x0,0x0,0x0,0x0,0x0,0x0,0x0,0x0,0x0,0x0,0x0,0x0,0x0,0x0,0x0,0x0,0x0,0x0,0x0,0x0,0x0,0x0,0x0,0x0,0x0,0x0,0x0,0x0,0x0,0x0,0x0,0x0,0x0,0x0,0x0,0x0,0x0,0x0,0x0,0x0,0x0,0x0,0x0,0x0,0x0,0x0,0x0,0x0,0x0,0x0,0x0,0x0,0x0,0x0,0x0,0x0,0x0,0x0,0x0,0x0,0x0,0x0,0x0,0x0,0x0,0x0,0x0,0x0,0x0,0x0,0x0,0x0,0x0,0x0,0x0,0x0,0x0,0x0,0x0,0x0,0x0,0x0,0x0,0x0,0x0,0x0,0x0,0x0,0x0,0x0,0x0,0x0,0x0,0x0,0x0,0x0,0x0,0x0,0x0,0x0,0x0,0x0,0x0,0x0,0x0,0x0,0x0,0x0,0x0,0x0,0x0,0x0,0x0,0x0,0x0,0x0,0x0,0x0,0x0,0x0,0x0,0x0,0x0,0x0,0x0,0x0,0x0,0x0,0x0,0x0,0x0,0x0,0x0,0x0,0x0,0x0,0x0,0x0,0x0,0x0,0x0,0x0,0x0,0x0,0x0,0x0,0x0,0x0,0x0,0x0,0x0,0x0,0x0,0x0,0x0,0x0,0x0,0x0,0x0,0x0,0x0,0x0,0x0,0x0,0x0,0x0,0x0,0x0,0x0,0x0,0x0,0x0,0x0,0x0,0x0,0x0,0x0,0x0,0x0,0x0,0x0,0x0,0x0,0x0,0x0,0x0,0x0,0x0,0x0,0x0,0x0,0x0,0x0,0x0,0x0,0x0,0x0,0x0,0x0,0x0,0x0,0x0,0x0,0x0,0x0,0x0,0x0,0x0,0x0,0x0,0x0,0x0,0x0,0x0,0x0,0x0,0x0,0x0,0x0,0x0,0x0,0x0,0x0,0x0,0x0,0x0,0x0,0x0,0x0,0x0,0x0,0x0,0x0,0x0,0x0,0x0,0x0,0x0,0x0,0x0,0x0,0x0,0x0,0x0,0x0,0x0,0x0,0x0,0x0,0x0,0x0,0x0,0x0,0x0,0x0,0x0,0x0,0x0,0x0,0x0,0x0,0x0,0x0,0x0,0x0,0x0,0x0,0x0,0x0,0x0,0x0,0x0,0x0,0x0,0x0,0x0,0x0,0x0,0x0,0x0,0x0,0x0,0x0,0x0,0x0,0x0,0x0,0x0,0x0,0x0,0x0,0x0,0x0,0x0,0x0,0x0,0x0,0x0,0x0,0x0,0x0,0x0,0x0,0x0,0x0,0x0,0x0,0x0,0x0,0x0,0x0,0x0,0x0,0x0,0x0,0x0,0x0,0x0,0x0,0x0,0x0,0x0,0x0,0x0,0x0,0x0,0x0,0x0,0x0,0x0,0x0,0x0,0x0,0x0,0x0,0x0,0x0,0x0,0x0,0x0,0x0,0x0,0x0,0x0,0x0,0x0,0x0,0x0,0x0,0x0,0x0,0x0,0x0,0x0,0x0,0x0,0x0,0x0,0x0,0x0,0x0,0x0,0x0,0x0,0x0,0x0,0x0,0x0,0x0,0x0,0x0,0x0,0x0,0x0,0x0,0x0,0x0,0x0,0x0,0x0,0x0,0x0,0x0,0x0,0x0,0x0,0x0,0x0,0x0,0x0,0x0,0x0,0x0,0x0,0x0,0x0,0x0,0x0,0x0,0x0,0x0,0x0,0x0,0x0,0x0,0x0,0x0,0x0,0x0,0x0,0x0,0x0,0x0,0x0,0x0,0x0,0x0,0x0,0x0,0x0,0x0,0x0,0x0,0x0,0x0,0x0,0x0,0x0,0x0,0x0,0x0,0x0,0x0,0x0,0x0,0x0,0x0,0x0,0x0,0x0,0x0,0x0,0x0,0x0,0x0,0x0,0x0,0x0,0x0,0x0,0x0,0x0,0x0,0x0,0x0,0x0,0x0,0x0,0x0,0x0,0x0,0x0,0x0,0x0,0x0,0x0,0x0,0x0,0x0,0x0,0x0,0x0,0x0,0x0,0x0,0x0,0x0,0x0,0x0,0x0,0x0,0x0,0x0,0x0,0x0,0x0,0x0,0x0,0x0,0x0,0x0,0x0,0x0,0x0,0x0,0x0,0x0,0x0,0x0,0x0,0x0,0x0,0x0,0x0,0x0,0x0,0x0,0x0,0x0,0x0,0x0,0x0,0x0,0x0,0x0,0x0,0x0,0x0,0x0,0x0,0x0,0x0,0x0,0x0,0x0,0x0,0x0,0x0,0x0,0x0,0x0,0x0,0x0,0x0,0x0,0x0,0x0,0x0,0x0,0x0,0x0,0x0,0x0,0x0,0x0,0x0,0x0,0x0,0x0,0x0,0x0,0x0,0x0,0x0,0x0,0x0,0x0,0x0,0x0,0x0,0x0,0x0,0x0,0x0,0x0,0x0,0x0,0x0,0x0,0x0,0x0,0x0,0x0,0x0,0x0,0x0,0x0,0x0,0x0,0x0,0x0,0x0,0x0,0x0,0x0,0x0,0x0,0x0,0x0,0x0,0x0,0x0,0x0,0x0,0x0,0x0,0x0,0x0,0x0,0x0,0x0,0x0,0x0,0x0,0x0,0x0,0x0,0x0,0x0,0x0,0x0,0x0,0x0,0x0,0x0,0x0,0x0,0x0,0x0,0x0,0x0,0x0,0x0,0x0,0x0,0x0,0x0,0x0,0x0,0x0,0x0,0x0,0x0,0x0,0x0,0x0,0x0,0x0,0x0,0x0,0x0,0x0,0x0,0x0,0x0,0x0,0x0,0x0,0x0,0x0,0x0,0x0,0x0,0x0,0x0,0x0,0x0,0x0,0x0,0x0,0x0,0x0,0x0,0x0,0x0,0x0,0x0,0x0,0x0,0x0,0x0,0x0,0x0,0x0,0x0,0x0,0x0,0x0,0x0,0x0,0x0,0x0,0x0,0x0,0x0,0x0,0x0,0x0,0x0,0x0,0x0,0x0,0x0,0x0,0x0,0x0,0x0,0x0,0x0,0x0,0x0,0x0,0x0,0x0,0x0,0x0,0x0,0x0,0x0,0x0,0x0,0x0,0x0,0x0,0x0,0x0,0x0,0x0,0x0,0x0,0x0,0x0,0x0,0x0,0x0,0x0,0x0,0x0,0x0,0x0,0x0,0x0,0x0,0x0,0x0,0x0,0x0,0x0,0x0,0x0,0x0,0x0,0x0,0x0,0x0,0x0,0x0,0x0,0x0,0x0,0x0,0x0,0x0,0x0,0x0,0x0,0x0,0x0,0x0,0x0,0x0,0x0,0x0,0x0,0x0,0x0,0x0,0x0,0x0,0x0,0x0,0x0,0x0,0x0,0x0,0x0,0x0,0x0,0x0,0x0,0x0,0x0,0x0,0x0,0x0,0x0,0x0,0x0,0x0,0x0,0x0,0x0,0x0,0x0,0x0,0x0,0x0,0x0,0x0,0x0,0x0,0x0,0x0,0x0,0x0,0x0,0x0,0x0,0x0,0x0,0x0,0x0,0x0,0x0,0x0,0x0,0x0,0x0,0x0,0x0,0x0,0x0,0x0,0x0,0x0,0x0,0x0,0x0,0x0,0x0,0x0,0x0,0x0,0x0,0x0,0x0,0x0,0x0,0x0,0x0,0x0,0x0,0x0,0x0,0x0,0x0,0x0,0x0,0x0,0x0,0x0,0x0,0x0,0x0,0x0,0x0,0x0,0x0,0x0,0x0,0x0,0x0,0x0,0x0,0x0,0x0,0x0,0x0,0x0,0x0,0x0,0x0,0x0,0x0,0x0,0x0,0x0,0x0,0x0,0x0,0x0,0x0,0x0,0x0,0x0,0x0,0x0,0x0,0x0,0x0,0x0,0x0,0x0,0x0,0x0,0x0,0x0,0x0,0x0,0x0,0x0,0x0,0x0,0x0,0x0,0x0,0x0,0x0,0x0,0x0,0x0,0x0,0x0,0x0,0x0,0x0,0x0,0x0,0x0,0x0,0x0,0x0,0x0,0x0,0x0,0x0,0x0,0x0,0x0,0x0,0x0,0x0,0x0,0x0,0x0,0x0,0x0,0x0,0x0,0x0,0x0,0x0,0x0,0x0,0x0,0x0,0x0,0x0,0x0,0x0,0x0,0x0,0x0,0x0,0x0,0x0,0x0,0x0,0x0,0x0,0x0,0x0,0x0,0x0,0x0,0x0,0x0,0x0,0x0,0x0,0x0,0x0,0x0,0x0,0x0,0x0,0x0,0x0,0x0,0x0,0x0,0x0,0x0,0x0,0x0,0x0,0x0,0x0,0x0,0x0,0x0,0x0,0x0,0x0,0x0,0x0,0x0,0x0,0x0,0x0,0x0,0x0,0x0,0x0,0x0,0x0,0x0,0x0,0x0,0x0,0x0,0x0,0x0,0x0,0x0,0x0,0x0,0x0,0x0,0x0,0x0,0x0,0x0,0x0,0x0,0x0,0x0,0x0,0x0,0x0,0x0,0x0,0x0,0x0,0x0,0x0,0x0,0x0,0x0,0x0,0x0,0x0,0x0,0x0,0x0,0x0,0x0,0x0,0x0,0x0,0x0,0x0,0x0,0x0,0x0,0x0,0x0,0x0,0x0,0x0,0x0,0x0,0x0,0x0,0x0,0x0,0x0,0x0,0x0,0x0,0x0,0x0,0x0,0x0,0x0,0x0,0x0,0x0,0x0,0x0,0x0,0x0,0x0,0x0,0x0,0x0,0x0,0x0,0x0,0x0,0x0,0x0,0x0,0x0,0x0,0x0,0x0,0x0,0x0,0x0,0x0,0x0,0x0,0x0,0x0,0x0,0x0,0x0,0x0,0x0,0x0,0x0,0x0,0x0,0x0,0x0,0x0,0x0,0x0,0x0,0x0,0x0,0x0,0x0,0x0,0x0,0x0,0x0,0x0,0x0,0x0,0x0,0x0,0x0,0x0,0x0,0x0,0x0,0x0,0x0,0x0,0x0,0x0,0x0,0x0,0x0,0x0,0x0,0x0,0x0,0x0,0x0,0x0,0x0,0x0,0x0,0x0,0x0,0x0,0x0,0x0,0x0,0x0,0x0,0x0,0x0,0x0,0x0,0x0,0x0,0x0,0x0,0x0,0x0,0x0,0x0,0x0,0x0,0x0,0x0,0x0,0x0,0x0,0x0,0x0,0x0,0x0,0x0,0x0,0x0,0x0,0x0,0x0,0x0,0x0,0x0,0x0,0x0,0x0,0x0,0x0,0x0,0x0,0x0,0x0,0x0,0x0,0x0,0x0,0x0,0x0,0x0,0x0,0x0,0x0,0x0,0x0,0x0,0x0,0x0,0x0,0x0,0x0,0x0,0x0,0x0,0x0,0x0,0x0,0x0,0x0,0x0,0x0,0x0,0x0,0x0,0x0,0x0,0x0,0x0,0x0,0x0,0x0,0x0,0x0,0x0,0x0,0x0,0x0,0x0,0x0,0x0,0x0,0x0,0x0,0x0,0x0,0x0,0x0,0x0,0x0,0x0,0x0,0x0,0x0,0x0,0x0,0x0,0x0,0x0,0x0,0x0,0x0,0x0,0x0,0x0,0x0,0x0,0x0,0x0,0x0,0x0,0x0,0x0,0x0,0x0,0x0,0x0,0x0,0x0,0x0,0x0,0x0,0x0,0x0,0x0,0x0,0x0,0x0,0x0,0x0,0x0,0x0,0x0,0x0,0x0,0x0,0x0,0x0,0x0,0x0,0x0,0x0,0x0,0x0,0x0,0x0,0x0,0x0,0x0,0x0,0x0,0x0,0x0,0x0,0x0,0x0,0x0,0x0,0x0,0x0,0x0,0x0,0x0,0x0,0x0,0x0,0x0,0x0,0x0,0x0,0x0,0x0,0x0,0x0,0x0,0x0,0x0,0x0,0x0,0x0,0x0,0x0,0x0,0x0,0x0,0x0,0x0,0x0,0x0,0x0,0x0,0x0,0x0,0x0,0x0,0x0,0x0,0x0,0x0,0x0,0x0,0x0,0x0,0x0,0x0,0x0,0x0,0x0,0x0,0x0,0x0,0x0,0x0,0x0,0x0,0x0,0x0,0x0,0x0,0x0,0x0,0x0,0x0,0x0,0x0,0x0,0x0,0x0,0x0,0x0,0x0,0x0,0x0,0x0,0x0,0x0,0x0,0x0,0x0,0x0,0x0,0x0,0x0,0x0,0x0,0x0,0x0,0x0,0x0,0x0,0x0,0x0,0x0,0x0,0x0,0x0,0x0,0x0,0x0,0x0,0x0,0x0,0x0,0x0,0x0,0x0,0x0,0x0,0x0,0x0,0x0,0x0,0x0,0x0,0x0,0x0,0x0,0x0,0x0,0x0,0x0,0x0,0x0,0x0,0x0,0x0,0x0,0x0,0x0,0x0,0x0,0x0,0x0,0x0,0x0,0x0,0x0,0x0,0x0,0x0,0x0,0x0,0x0,0x0,0x0,0x0,0x0,0x0,0x0,0x0,0x0,0x0,0x0,0x0,0x0,0x0,0x0,0x0,0x0,0x0,0x0,0x0,0x0,0x0,0x0,0x0,0x0,0x0,0x0,0x0,0x0,0x0,0x0,]

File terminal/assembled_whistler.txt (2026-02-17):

[0x0,0xf,0x28,0xe2,0xfe,0x0,0xf,0x28,0xe3,0xfe,0x0,0x0,0x28,0xe1,0xfe,0x0,0xff,0x28,0xf2,0xfe,0x28,0xf3,0xfe,0x0,0xf,0x28,0x2,0x8,0x28,0x3,0x8,0x36,0xe7,0x0,0x2,0x0,0x8,0x28,0x4,0x8,0x0,0xf,0x29,0x0,0x8,0x0,0x0,0x28,0x6,0x8,0x36,0x7d,0x0,0x1,0x3,0x8,0x10,0xf,0x3c,0x74,0x0,0x1,0x3,0x8,0x11,0x2,0x8,0x3c,0x74,0x0,0x1,0x3,0x8,0x10,0x89,0x3d,0x6b,0x0,0x1,0x4,0x8,0x29,0x0,0x8,0x36,0xd8,0x0,0x36,0x41,0x1,0x2,0x0,0x8,0x28,0x4,0x8,0x0,0xf,0x29,0x0,0x8,0x36,0xc6,0x1,0x3b,0x74,0x0,0x1,0x3,0x8,0x36,0xaa,0x1,0x36,0xa3,0x0,0x1,0x3,0x8,0x28,0x2,0x8,0x3b,0x32,0x0,0x31,0x33,0x2f,0x0,0x0,0xb,0x28,0xe0,0xfe,0x1,0xe0,0xfe,0x28,0x3,0x8,0xa,0x11,0x3,0x8,0x3d,0x9f,0x0,0xa,0x10,0xf,0x3c,0x9f,0x0,0xa,0xc,0x1,0x3b,0x82,0x0,0x2e,0x32,0x30,0x37,0x31,0x33,0x2f,0x29,0x0,0x8,0x1,0x0,0x8,0xc,0x1,0x28,0x0,0x8,0x1,0x1,0x8,0x14,0x0,0x28,0x1,0x8,0x1,0x0,0x8,0x1c,0x1f,0x10,0x19,0x3d,0xc9,0x0,0x36,0xd8,0x0,0x36,0x41,0x1,0x2,0x0,0x8,0x28,0x4,0x8,0x0,0xf,0x29,0x0,0x8,0x2e,0x32,0x30,0x37,0x33,0x31,0x2f,0x1,0x0,0x8,0x1c,0xe0,0x28,0x0,0x8,0x2e,0x30,0x32,0x37,0x33,0x31,0x2f,0x0,0x0,0x28,0x0,0x8,0x0,0xfc,0x28,0x1,0x8,0x0,0x17,0x29,0x0,0x8,0x1,0x0,0x8,0xc,0x1,0x28,0x0,0x8,0x1,0x1,0x8,0x14,0x0,0x28,0x1,0x8,0x1,0x0,0x8,0x1c,0x1f,0x10,0x19,0x3d,0xf4,0x0,0x36,0xd8,0x0,0x1,0x0,0x8,0xc,0x20,0x28,0x0,0x8,0x1,0x1,0x8,0x14,0x0,0x28,0x1,0x8,0x1,0x1,0x8,0x10,0xfe,0x3d,0xf4,0x0,0x0,0x0,0x28,0x0,0x8,0x0,0xfc,0x28,0x1,0x8,0x0,0x0,0x28,0x5,0x8,0x2e,0x30,0x32,0x37,0x2f,0x33,0x31,0x1,0x0,0x8,0xc,0x20,0x28,0x0,0x8,0x1,0x1,0x8,0x14,0x0,0x28,0x1,0x8,0x1,0x1,0x8,0x10,0xfe,0x3d,0x6b,0x1,0x0,0x0,0x28,0x0,0x8,0x0,0xfc,0x28,0x1,0x8,0x0,0x1,0x28,0x5,0x8,0x36,0x72,0x1,0x30,0x32,0x2e,0x37,0x2f,0x33,0x31,0x1,0x5,0x8,0x10,0x1,0x3d,0xa6,0x1,0x5,0xe1,0xfe,0x8,0x2b,0xe1,0xfe,0x0,0x17,0x29,0x0,0x8,0x1,0x0,0x8,0xc,0x1,0x28,0x0,0x8,0x1,0x1,0x8,0x14,0x0,0x28,0x1,0x8,0x1,0x0,0x8,0x1c,0x1f,0x10,0x19,0x3d,0x84,0x1,0x36,0xd8,0x0,0x30,0x32,0x2e,0x37,0x33,0x31,0x2f,0x1,0x6,0x8,0xc,0x1,0x28,0x6,0x8,0x10,0x6,0x3f,0xc2,0x1,0x2e,0x2f,0x5,0x6,0x8,0x2a,0x6,0x8,0x2e,0x30,0x32,0x37,0x33,0x31,0x2f,0x1,0x6,0x8,0x10,0x5,0x3d,0x9,0x2,0x1,0x7,0x8,0x10,0x80,0x3d,0x9,0x2,0x4,0x0,0x3,0x8,0x8,0x31,0x36,0x2e,0x2,0xa,0x30,0x2a,0x8,0x8,0x28,0xf0,0xfe,0x10,0x10,0x3c,0x9,0x2,0x8,0xa,0x10,0x4,0x3c,0xf9,0x1,0x3d,0xdb,0x1,0x1,0x8,0x8,0x25,0x25,0x25,0x25,0x28,0x8,0x8,0x28,0xf0,0xfe,0x3b,0xe,0x2,0x0,0x40,0x36,0xa3,0x0,0x1,0x4,0x8,0x29,0x0,0x8,0x36,0xd8,0x0,0x36,0x41,0x1,0x2,0x0,0x8,0x28,0x4,0x8,0x0,0xf,0x29,0x0,0x8,0x0,0x0,0x28,0x6,0x8,0x2e,0x30,0x32,0x37,0x33,0x2f,0x4,0x0,0x13,0x44,0x2,0x3c,0x41,0x2,0x8,0xa,0x10,0x10,0x2e,0x2f,0x3d,0x32,0x2,0x2e,0x32,0x37,31,30,46,78,29,45,77,28,44,76,17,22,66,65,64,129,0x0,0x0,0x0,0x0,0x0,0x0,0x0,0x0,0x0,0x0,0x0,0x0,0x0,0x0,0x0,0x0,0x0,0x0,0x0,0x0,0x0,0x0,0x0,0x0,0x0,0x0,0x0,0x0,0x0,0x0,0x0,0x0,0x0,0x0,0x0,0x0,0x0,0x0,0x0,0x0,0x0,0x0,0x0,0x0,0x0,0x0,0x0,0x0,0x0,0x0,0x0,0x0,0x0,0x0,0x0,0x0,0x0,0x0,0x0,0x0,0x0,0x0,0x0,0x0,0x0,0x0,0x0,0x0,0x0,0x0,0x0,0x0,0x0,0x0,0x0,0x0,0x0,0x0,0x0,0x0,0x0,0x0,0x0,0x0,0x0,0x0,0x0,0x0,0x0,0x0,0x0,0x0,0x0,0x0,0x0,0x0,0x0,0x0,0x0,0x0,0x0,0x0,0x0,0x0,0x0,0x0,0x0,0x0,0x0,0x0,0x0,0x0,0x0,0x0,0x0,0x0,0x0,0x0,0x0,0x0,0x0,0x0,0x0,0x0,0x0,0x0,0x0,0x0,0x0,0x0,0x0,0x0,0x0,0x0,0x0,0x0,0x0,0x0,0x0,0x0,0x0,0x0,0x0,0x0,0x0,0x0,0x0,0x0,0x0,0x0,0x0,0x0,0x0,0x0,0x0,0x0,0x0,0x0,0x0,0x0,0x0,0x0,0x0,0x0,0x0,0x0,0x0,0x0,0x0,0x0,0x0,0x0,0x0,0x0,0x0,0x0,0x0,0x0,0x0,0x0,0x0,0x0,0x0,0x0,0x0,0x0,0x0,0x0,0x0,0x0,0x0,0x0,0x0,0x0,0x0,0x0,0x0,0x0,0x0,0x0,0x0,0x0,0x0,0x0,0x0,0x0,0x0,0x0,0x0,0x0,0x0,0x0,0x0,0x0,0x0,0x0,0x0,0x0,0x0,0x0,0x0,0x0,0x0,0x0,0x0,0x0,0x0,0x0,0x0,0x0,0x0,0x0,0x0,0x0,0x0,0x0,0x0,0x0,0x0,0x0,0x0,0x0,0x0,0x0,0x0,0x0,0x0,0x0,0x0,0x0,0x0,0x0,0x0,0x0,0x0,0x0,0x0,0x0,0x0,0x0,0x0,0x0,0x0,0x0,0x0,0x0,0x0,0x0,0x0,0x0,0x0,0x0,0x0,0x0,0x0,0x0,0x0,0x0,0x0,0x0,0x0,0x0,0x0,0x0,0x0,0x0,0x0,0x0,0x0,0x0,0x0,0x0,0x0,0x0,0x0,0x0,0x0,0x0,0x0,0x0,0x0,0x0,0x0,0x0,0x0,0x0,0x0,0x0,0x0,0x0,0x0,0x0,0x0,0x0,0x0,0x0,0x0,0x0,0x0,0x0,0x0,0x0,0x0,0x0,0x0,0x0,0x0,0x0,0x0,0x0,0x0,0x0,0x0,0x0,0x0,0x0,0x0,0x0,0x0,0x0,0x0,0x0,0x0,0x0,0x0,0x0,0x0,0x0,0x0,0x0,0x0,0x0,0x0,0x0,0x0,0x0,0x0,0x0,0x0,0x0,0x0,0x0,0x0,0x0,0x0,0x0,0x0,0x0,0x0,0x0,0x0,0x0,0x0,0x0,0x0,0x0,0x0,0x0,0x0,0x0,0x0,0x0,0x0,0x0,0x0,0x0,0x0,0x0,0x0,0x0,0x0,0x0,0x0,0x0,0x0,0x0,0x0,0x0,0x0,0x0,0x0,0x0,0x0,0x0,0x0,0x0,0x0,0x0,0x0,0x0,0x0,0x0,0x0,0x0,0x0,0x0,0x0,0x0,0x0,0x0,0x0,0x0,0x0,0x0,0x0,0x0,0x0,0x0,0x0,0x0,0x0,0x0,0x0,0x0,0x0,0x0,0x0,0x0,0x0,0x0,0x0,0x0,0x0,0x0,0x0,0x0,0x0,0x0,0x0,0x0,0x0,0x0,0x0,0x0,0x0,0x0,0x0,0x0,0x0,0x0,0x0,0x0,0x0,0x0,0x0,0x0,0x0,0x0,0x0,0x0,0x0,0x0,0x0,0x0,0x0,0x0,0x0,0x0,0x0,0x0,0x0,0x0,0x0,0x0,0x0,0x0,0x0,0x0,0x0,0x0,0x0,0x0,0x0,0x0,0x0,0x0,0x0,0x0,0x0,0x0,0x0,0x0,0x0,0x0,0x0,0x0,0x0,0x0,0x0,0x0,0x0,0x0,0x0,0x0,0x0,0x0,0x0,0x0,0x0,0x0,0x0,0x0,0x0,0x0,0x0,0x0,0x0,0x0,0x0,0x0,0x0,0x0,0x0,0x0,0x0,0x0,0x0,0x0,0x0,0x0,0x0,0x0,0x0,0x0,0x0,0x0,0x0,0x0,0x0,0x0,0x0,0x0,0x0,0x0,0x0,0x0,0x0,0x0,0x0,0x0,0x0,0x0,0x0,0x0,0x0,0x0,0x0,0x0,0x0,0x0,0x0,0x0,0x0,0x0,0x0,0x0,0x0,0x0,0x0,0x0,0x0,0x0,0x0,0x0,0x0,0x0,0x0,0x0,0x0,0x0,0x0,0x0,0x0,0x0,0x0,0x0,0x0,0x0,0x0,0x0,0x0,0x0,0x0,0x0,0x0,0x0,0x0,0x0,0x0,0x0,0x0,0x0,0x0,0x0,0x0,0x0,0x0,0x0,0x0,0x0,0x0,0x0,0x0,0x0,0x0,0x0,0x0,0x0,0x0,0x0,0x0,0x0,0x0,0x0,0x0,0x0,0x0,0x0,0x0,0x0,0x0,0x0,0x0,0x0,0x0,0x0,0x0,0x0,0x0,0x0,0x0,0x0,0x0,0x0,0x0,0x0,0x0,0x0,0x0,0x0,0x0,0x0,0x0,0x0,0x0,0x0,0x0,0x0,0x0,0x0,0x0,0x0,0x0,0x0,0x0,0x0,0x0,0x0,0x0,0x0,0x0,0x0,0x0,0x0,0x0,0x0,0x0,0x0,0x0,0x0,0x0,0x0,0x0,0x0,0x0,0x0,0x0,0x0,0x0,0x0,0x0,0x0,0x0,0x0,0x0,0x0,0x0,0x0,0x0,0x0,0x0,0x0,0x0,0x0,0x0,0x0,0x0,0x0,0x0,0x0,0x0,0x0,0x0,0x0,0x0,0x0,0x0,0x0,0x0,0x0,0x0,0x0,0x0,0x0,0x0,0x0,0x0,0x0,0x0,0x0,0x0,0x0,0x0,0x0,0x0,0x0,0x0,0x0,0x0,0x0,0x0,0x0,0x0,0x0,0x0,0x0,0x0,0x0,0x0,0x0,0x0,0x0,0x0,0x0,0x0,0x0,0x0,0x0,0x0,0x0,0x0,0x0,0x0,0x0,0x0,0x0,0x0,0x0,0x0,0x0,0x0,0x0,0x0,0x0,0x0,0x0,0x0,0x0,0x0,0x0,0x0,0x0,0x0,0x0,0x0,0x0,0x0,0x0,0x0,0x0,0x0,0x0,0x0,0x0,0x0,0x0,0x0,0x0,0x0,0x0,0x0,0x0,0x0,0x0,0x0,0x0,0x0,0x0,0x0,0x0,0x0,0x0,0x0,0x0,0x0,0x0,0x0,0x0,0x0,0x0,0x0,0x0,0x0,0x0,0x0,0x0,0x0,0x0,0x0,0x0,0x0,0x0,0x0,0x0,0x0,0x0,0x0,0x0,0x0,0x0,0x0,0x0,0x0,0x0,0x0,0x0,0x0,0x0,0x0,0x0,0x0,0x0,0x0,0x0,0x0,0x0,0x0,0x0,0x0,0x0,0x0,0x0,0x0,0x0,0x0,0x0,0x0,0x0,0x0,0x0,0x0,0x0,0x0,0x0,0x0,0x0,0x0,0x0,0x0,0x0,0x0,0x0,0x0,0x0,0x0,0x0,0x0,0x0,0x0,0x0,0x0,0x0,0x0,0x0,0x0,0x0,0x0,0x0,0x0,0x0,0x0,0x0,0x0,0x0,0x0,0x0,0x0,0x0,0x0,0x0,0x0,0x0,0x0,0x0,0x0,0x0,0x0,0x0,0x0,0x0,0x0,0x0,0x0,0x0,0x0,0x0,0x0,0x0,0x0,0x0,0x0,0x0,0x0,0x0,0x0,0x0,0x0,0x0,0x0,0x0,0x0,0x0,0x0,0x0,0x0,0x0,0x0,0x0,0x0,0x0,0x0,0x0,0x0,0x0,0x0,0x0,0x0,0x0,0x0,0x0,0x0,0x0,0x0,0x0,0x0,0x0,0x0,0x0,0x0,0x0,0x0,0x0,0x0,0x0,0x0,0x0,0x0,0x0,0x0,0x0,0x0,0x0,0x0,0x0,0x0,0x0,0x0,0x0,0x0,0x0,0x0,0x0,0x0,0x0,0x0,0x0,0x0,0x0,0x0,0x0,0x0,0x0,0x0,0x0,0x0,0x0,0x0,0x0,0x0,0x0,0x0,0x0,0x0,0x0,0x0,0x0,0x0,0x0,0x0,0x0,0x0,0x0,0x0,0x0,0x0,0x0,0x0,0x0,0x0,0x0,0x0,0x0,0x0,0x0,0x0,0x0,0x0,0x0,0x0,0x0,0x0,0x0,0x0,0x0,0x0,0x0,0x0,0x0,0x0,0x0,0x0,0x0,0x0,0x0,0x0,0x0,0x0,0x0,0x0,0x0,0x0,0x0,0x0,0x0,0x0,0x0,0x0,0x0,0x0,0x0,0x0,0x0,0x0,0x0,0x0,0x0,0x0,0x0,0x0,0x0,0x0,0x0,0x0,0x0,0x0,0x0,0x0,0x0,0x0,0x0,0x0,0x0,0x0,0x0,0x0,0x0,0x0,0x0,0x0,0x0,0x0,0x0,0x0,0x0,0x0,0x0,0x0,0x0,0x0,0x0,0x0,0x0,0x0,0x0,0x0,0x0,0x0,0x0,0x0,0x0,0x0,0x0,0x0,0x0,0x0,0x0,0x0,0x0,0x0,0x0,0x0,0x0,0x0,0x0,0x0,0x0,0x0,0x0,0x0,0x0,0x0,0x0,0x0,0x0,0x0,0x0,0x0,0x0,0x0,0x0,0x0,0x0,0x0,0x0,0x0,0x0,0x0,0x0,0x0,0x0,0x0,0x0,0x0,0x0,0x0,0x0,0x0,0x0,0x0,0x0,0x0,0x0,0x0,0x0,0x0,0x0,0x0,0x0,0x0,0x0,0x0,0x0,0x0,0x0,0x0,0x0,0x0,0x0,0x0,0x0,0x0,0x0,0x0,0x0,0x0,0x0,0x0,0x0,0x0,0x0,0x0,0x0,0x0,0x0,0x0,0x0,0x0,0x0,0x0,0x0,0x0,0x0,0x0,0x0,0x0,0x0,0x0,0x0,0x0,0x0,0x0,0x0,0x0,0x0,0x0,0x0,0x0,0x0,0x0,0x0,0x0,0x0,0x0,0x0,0x0,0x0,0x0,0x0,0x0,0x0,0x0,0x0,0x0,0x0,0x0,0x0,0x0,0x0,0x0,0x0,0x0,0x0,0x0,0x0,0x0,0x0,0x0,0x0,0x0,0x0,0x0,0x0,0x0,0x0,0x0,0x0,0x0,0x0,0x0,0x0,0x0,0x0,0x0,0x0,0x0,0x0,0x0,0x0,0x0,0x0,0x0,0x0,0x0,0x0,0x0,0x0,0x0,0x0,0x0,0x0,0x0,0x0,0x0,0x0,0x0,0x0,0x0,0x0,0x0,0x0,0x0,0x0,0x0,0x0,0x0,0x0,0x0,0x0,0x0,0x0,0x0,0x0,0x0,0x0,0x0,0x0,0x0,0x0,0x0,0x0,0x0,0x0,0x0,0x0,0x0,0x0,0x0,0x0,0x0,0x0,0x0,0x0,0x0,0x0,0x0,0x0,0x0,0x0,0x0,0x0,0x0,0x0,0x0,0x0,0x0,0x0,0x0,0x0,0x0,0x0,0x0,0x0,0x0,0x0,0x0,0x0,0x0,0x0,0x0,0x0,0x0,0x0,0x0,0x0,0x0,0x0,0x0,0x0,0x0,0x0,0x0,0x0,0x0,0x0,0x0,0x0,0x0,0x0,0x0,0x0,0x0,0x0,0x0,0x0,0x0,0x0,0x0,0x0,0x0,0x0,0x0,0x0,0x0,0x0,0x0,0x0,0x0,0x0,0x0,0x0,0x0,0x0,0x0,0x0,0x0,0x0,0x0,0x0,0x0,0x0,0x0,0x0,0x0,0x0,0x0,0x0,0x0,0x0,0x0,0x0,0x0,0x0,0x0,0x0,0x0,0x0,0x0,0x0,0x0,0x0,0x0,0x0,0x0,0x0,0x0,0x0,0x0,0x0,0x0,0x0,0x0,0x0,]

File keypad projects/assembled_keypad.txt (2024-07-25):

[0x0,0xf,0x28,0xf3,0xfe,0x0,0xff,0x28,0xf2,0xfe,0x36,0x16,0x0,0x36,0x35,0x0,0x28,0xf0,0xfe,0x3b,0xa,0x0,0x31,0x33,0x0,0x1,0xb,0x28,0xf1,0xfe,0x11,0xf1,0xfe,0x3d,0x2f,0x0,0xa,0x10,0x8,0x3c,0x2f,0x0,0xa,0x25,0x3b,0x1a,0x0,0x1,0xf1,0xfe,0x30,0x30,0x37,0x31,0x33,0x4,0x0,0x2f,0x13,0x4e,0x0,0x2e,0x3c,0x4a,0x0,0x2f,0x8,0xa,0x10,0x10,0x2e,0x3d,0x39,0x0,0xa,0x32,0x30,0x37,40,17,33,65,18,34,66,20,36,68,129,130,132,136,24,72,0x0,0x0,0x0,0x0,0x0,0x0,0x0,0x0,0x0,0x0,0x0,0x0,0x0,0x0,0x0,0x0,0x0,0x0,0x0,0x0,0x0,0x0,0x0,0x0,0x0,0x0,0x0,0x0,0x0,0x0,0x0,0x0,0x0,0x0,0x0,0x0,0x0,0x0,0x0,0x0,0x0,0x0,0x0,0x0,0x0,0x0,0x0,0x0,0x0,0x0,0x0,0x0,0x0,0x0,0x0,0x0,0x0,0x0,0x0,0x0,0x0,0x0,0x0,0x0,0x0,0x0,0x0,0x0,0x0,0x0,0x0,0x0,0x0,0x0,0x0,0x0,0x0,0x0,0x0,0x0,0x0,0x0,0x0,0x0,0x0,0x0,0x0,0x0,0x0,0x0,0x0,0x0,0x0,0x0,0x0,0x0,0x0,0x0,0x0,0x0,0x0,0x0,0x0,0x0,0x0,0x0,0x0,0x0,0x0,0x0,0x0,0x0,0x0,0x0,0x0,0x0,0x0,0x0,0x0,0x0,0x0,0x0,0x0,0x0,0x0,0x0,0x0,0x0,0x0,0x0,0x0,0x0,0x0,0x0,0x0,0x0,0x0,0x0,0x0,0x0,0x0,0x0,0x0,0x0,0x0,0x0,0x0,0x0,0x0,0x0,0x0,0x0,0x0,0x0,0x0,0x0,0x0,0x0,0x0,0x0,0x0,0x0,0x0,0x0,0x0,0x0,0x0,0x0,0x0,0x0,0x0,0x0,0x0,0x0,0x0,0x0,0x0,0x0,0x0,0x0,0x0,0x0,0x0,0x0,0x0,0x0,0x0,0x0,0x0,0x0,0x0,0x0,0x0,0x0,0x0,0x0,0x0,0x0,0x0,0x0,0x0,0x0,0x0,0x0,0x0,0x0,0x0,0x0,0x0,0x0,0x0,0x0,0x0,0x0,0x0,0x0,0x0,0x0,0x0,0x0,0x0,0x0,0x0,0x0,0x0,0x0,0x0,0x0,0x0,0x0,0x0,0x0,0x0,0x0,0x0,0x0,0x0,0x0,0x0,0x0,0x0,0x0,0x0,0x0,0x0,0x0,0x0,0x0,0x0,0x0,0x0,0x0,0x0,0x0,0x0,0x0,0x0,0x0,0x0,0x0,0x0,0x0,0x0,0x0,0x0,0x0,0x0,0x0,0x0,0x0,0x0,0x0,0x0,0x0,0x0,0x0,0x0,0x0,0x0,0x0,0x0,0x0,0x0,0x0,0x0,0x0,0x0,0x0,0x0,0x0,0x0,0x0,0x0,0x0,0x0,0x0,0x0,0x0,0x0,0x0,0x0,0x0,0x0,0x0,0x0,0x0,0x0,0x0,0x0,0x0,0x0,0x0,0x0,0x0,0x0,0x0,0x0,0x0,0x0,0x0,0x0,0x0,0x0,0x0,0x0,0x0,0x0,0x0,0x0,0x0,0x0,0x0,0x0,0x0,0x0,0x0,0x0,0x0,0x0,0x0,0x0,0x0,0x0,0x0,0x0,0x0,0x0,0x0,0x0,0x0,0x0,0x0,0x0,0x0,0x0,0x0,0x0,0x0,0x0,0x0,0x0,0x0,0x0,0x0,0x0,0x0,0x0,0x0,0x0,0x0,0x0,0x0,0x0,0x0,0x0,0x0,0x0,0x0,0x0,0x0,0x0,0x0,0x0,0x0,0x0,0x0,0x0,0x0,0x0,0x0,0x0,0x0,0x0,0x0,0x0,0x0,0x0,0x0,0x0,0x0,0x0,0x0,0x0,0x0,0x0,0x0,0x0,0x0,0x0,0x0,0x0,0x0,0x0,0x0,0x0,0x0,0x0,0x0,0x0,0x0,0x0,0x0,0x0,0x0,0x0,0x0,0x0,0x0,0x0,0x0,0x0,0x0,0x0,0x0,0x0,0x0,0x0,0x0,0x0,0x0,0x0,0x0,0x0,0x0,0x0,0x0,0x0,0x0,0x0,0x0,0x0,0x0,0x0,0x0,0x0,0x0,0x0,0x0,0x0,0x0,0x0,0x0,0x0,0x0,0x0,0x0,0x0,0x0,0x0,0x0,0x0,0x0,0x0,0x0,0x0,0x0,0x0,0x0,0x0,0x0,0x0,0x0,0x0,0x0,0x0,0x0,0x0,0x0,0x0,0x0,0x0,0x0,0x0,0x0,0x0,0x0,0x0,0x0,0x0,0x0,0x0,0x0,0x0,0x0,0x0,0x0,0x0,0x0,0x0,0x0,0x0,0x0,0x0,0x0,0x0,0x0,0x0,0x0,0x0,0x0,0x0,0x0,0x0,0x0,0x0,0x0,0x0,0x0,0x0,0x0,0x0,0x0,0x0,0x0,0x0,0x0,0x0,0x0,0x0,0x0,0x0,0x0,0x0,0x0,0x0,0x0,0x0,0x0,0x0,0x0,0x0,0x0,0x0,0x0,0x0,0x0,0x0,0x0,0x0,0x0,0x0,0x0,0x0,0x0,0x0,0x0,0x0,0x0,0x0,0x0,0x0,0x0,0x0,0x0,0x0,0x0,0x0,0x0,0x0,0x0,0x0,0x0,0x0,0x0,0x0,0x0,0x0,0x0,0x0,0x0,0x0,0x0,0x0,0x0,0x0,0x0,0x0,0x0,0x0,0x0,0x0,0x0,0x0,0x0,0x0,0x0,0x0,0x0,0x0,0x0,0x0,0x0,0x0,0x0,0x0,0x0,0x0,0x0,0x0,0x0,0x0,0x0,0x0,0x0,0x0,0x0,0x0,0x0,0x0,0x0,0x0,0x0,0x0,0x0,0x0,0x0,0x0,0x0,0x0,0x0,0x0,0x0,0x0,0x0,0x0,0x0,0x0,0x0,0x0,0x0,0x0,0x0,0x0,0x0,0x0,0x0,0x0,0x0,0x0,0x0,0x0,0x0,0x0,0x0,0x0,0x0,0x0,0x0,0x0,0x0,0x0,0x0,0x0,0x0,0x0,0x0,0x0,0x0,0x0,0x0,0x0,0x0,0x0,0x0,0x0,0x0,0x0,0x0,0x0,0x0,0x0,0x0,0x0,0x0,0x0,0x0,0x0,0x0,0x0,0x0,0x0,0x0,0x0,0x0,0x0,0x0,0x0,0x0,0x0,0x0,0x0,0x0,0x0,0x0,0x0,0x0,0x0,0x0,0x0,0x0,0x0,0x0,0x0,0x0,0x0,0x0,0x0,0x0,0x0,0x0,0x0,0x0,0x0,0x0,0x0,0x0,0x0,0x0,0x0,0x0,0x0,0x0,0x0,0x0,0x0,0x0,0x0,0x0,0x0,0x0,0x0,0x0,0x0,0x0,0x0,0x0,0x0,0x0,0x0,0x0,0x0,0x0,0x0,0x0,0x0,0x0,0x0,0x0,0x0,0x0,0x0,0x0,0x0,0x0,0x0,0x0,0x0,0x0,0x0,0x0,0x0,0x0,0x0,0x0,0x0,0x0,0x0,0x0,0x0,0x0,0x0,0x0,0x0,0x0,0x0,0x0,0x0,0x0,0x0,0x0,0x0,0x0,0x0,0x0,0x0,0x0,0x0,0x0,0x0,0x0,0x0,0x0,0x0,0x0,0x0,0x0,0x0,0x0,0x0,0x0,0x0,0x0,0x0,0x0,0x0,0x0,0x0,0x0,0x0,0x0,0x0,0x0,0x0,0x0,0x0,0x0,0x0,0x0,0x0,0x0,0x0,0x0,0x0,0x0,0x0,0x0,0x0,0x0,0x0,0x0,0x0,0x0,0x0,0x0,0x0,0x0,0x0,0x0,0x0,0x0,0x0,0x0,0x0,0x0,0x0,0x0,0x0,0x0,0x0,0x0,0x0,0x0,0x0,0x0,0x0,0x0,0x0,0x0,0x0,0x0,0x0,0x0,0x0,0x0,0x0,0x0,0x0,0x0,0x0,0x0,0x0,0x0,0x0,0x0,0x0,0x0,0x0,0x0,0x0,0x0,0x0,0x0,0x0,0x0,0x0,0x0,0x0,0x0,0x0,0x0,0x0,0x0,0x0,0x0,0x0,0x0,0x0,0x0,0x0,0x0,0x0,0x0,0x0,0x0,0x0,0x0,0x0,0x0,0x0,0x0,0x0,0x0,0x0,0x0,0x0,0x0,0x0,0x0,0x0,0x0,0x0,0x0,0x0,0x0,0x0,0x0,0x0,0x0,0x0,0x0,0x0,0x0,0x0,0x0,0x0,0x0,0x0,0x0,0x0,0x0,0x0,0x0,0x0,0x0,0x0,0x0,0x0,0x0,0x0,0x0,0x0,0x0,0x0,0x0,0x0,0x0,0x0,0x0,0x0,0x0,0x0,0x0,0x0,0x0,0x0,0x0,0x0,0x0,0x0,0x0,0x0,0x0,0x0,0x0,0x0,0x0,0x0,0x0,0x0,0x0,0x0,0x0,0x0,0x0,0x0,0x0,0x0,0x0,0x0,0x0,0x0,0x0,0x0,0x0,0x0,0x0,0x0,0x0,0x0,0x0,0x0,0x0,0x0,0x0,0x0,0x0,0x0,0x0,0x0,0x0,0x0,0x0,0x0,0x0,0x0,0x0,0x0,0x0,0x0,0x0,0x0,0x0,0x0,0x0,0x0,0x0,0x0,0x0,0x0,0x0,0x0,0x0,0x0,0x0,0x0,0x0,0x0,0x0,0x0,0x0,0x0,0x0,0x0,0x0,0x0,0x0,0x0,0x0,0x0,0x0,0x0,0x0,0x0,0x0,0x0,0x0,0x0,0x0,0x0,0x0,0x0,0x0,0x0,0x0,0x0,0x0,0x0,0x0,0x0,0x0,0x0,0x0,0x0,0x0,0x0,0x0,0x0,0x0,0x0,0x0,0x0,0x0,0x0,0x0,0x0,0x0,0x0,0x0,0x0,0x0,0x0,0x0,0x0,0x0,0x0,0x0,0x0,0x0,0x0,0x0,0x0,0x0,0x0,0x0,0x0,0x0,0x0,0x0,0x0,0x0,0x0,0x0,0x0,0x0,0x0,0x0,0x0,0x0,0x0,0x0,0x0,0x0,0x0,0x0,0x0,0x0,0x0,0x0,0x0,0x0,0x0,0x0,0x0,0x0,0x0,0x0,0x0,0x0,0x0,0x0,0x0,0x0,0x0,0x0,0x0,0x0,0x0,0x0,0x0,0x0,0x0,0x0,0x0,0x0,0x0,0x0,0x0,0x0,0x0,0x0,0x0,0x0,0x0,0x0,0x0,0x0,0x0,0x0,0x0,0x0,0x0,0x0,0x0,0x0,0x0,0x0,0x0,0x0,0x0,0x0,0x0,0x0,0x0,0x0,0x0,0x0,0x0,0x0,0x0,0x0,0x0,0x0,0x0,0x0,0x0,0x0,0x0,0x0,0x0,0x0,0x0,0x0,0x0,0x0,0x0,0x0,0x0,0x0,0x0,0x0,0x0,0x0,0x0,0x0,0x0,0x0,0x0,0x0,0x0,0x0,0x0,0x0,0x0,0x0,0x0,0x0,0x0,0x0,0x0,0x0,0x0,0x0,0x0,0x0,0x0,0x0,0x0,0x0,0x0,0x0,0x0,0x0,0x0,0x0,0x0,0x0,0x0,0x0,0x0,0x0,0x0,0x0,0x0,0x0,0x0,0x0,0x0,0x0,0x0,0x0,0x0,0x0,0x0,0x0,0x0,0x0,0x0,0x0,0x0,0x0,0x0,0x0,0x0,0x0,0x0,0x0,0x0,0x0,0x0,0x0,0x0,0x0,0x0,0x0,0x0,0x0,0x0,0x0,0x0,0x0,0x0,0x0,0x0,0x0,0x0,0x0,0x0,0x0,0x0,0x0,0x0,0x0,0x0,0x0,0x0,0x0,0x0,0x0,0x0,0x0,0x0,0x0,0x0,0x0,0x0,0x0,0x0,0x0,0x0,0x0,0x0,0x0,0x0,0x0,0x0,0x0,0x0,0x0,0x0,0x0,0x0,0x0,0x0,0x0,0x0,0x0,0x0,0x0,0x0,0x0,0x0,0x0,0x0,0x0,0x0,0x0,0x0,0x0,0x0,0x0,0x0,0x0,0x0,0x0,0x0,0x0,0x0,0x0,0x0,0x0,0x0,0x0,0x0,0x0,0x0,0x0,0x0,0x0,0x0,0x0,0x0,0x0,0x0,0x0,0x0,0x0,0x0,0x0,0x0,0x0,0x0,0x0,0x0,0x0,0x0,0x0,0x0,0x0,0x0,0x0,0x0,0x0,0x0,0x0,0x0,0x0,0x0,0x0,0x0,0x0,0x0,0x0,0x0,0x0,0x0,0x0,0x0,0x0,0x0,0x0,0x0,0x0,0x0,0x0,0x0,0x0,0x0,0x0,0x0,0x0,0x0,0x0,0x0,0x0,0x0,0x0,0x0,0x0,0x0,0x0,0x0,0x0,0x0,0x0,0x0,0x0,0x0,0x0,0x0,0x0,0x0,0x0,0x0,0x0,0x0,0x0,0x0,0x0,0x0,0x0,0x0,0x0,0x0,0x0,0x0,0x0,0x0,0x0,0x0,0x0,0x0,0x0,0x0,0x0,0x0,0x0,0x0,0x0,0x0,0x0,0x0,0x0,0x0,0x0,0x0,0x0,0x0,0x0,0x0,0x0,0x0,0x0,0x0,0x0,0x0,0x0,0x0,0x0,0x0,0x0,0x0,0x0,0x0,0x0,0x0,0x0,0x0,0x0,0x0,0x0,0x0,0x0,0x0,0x0,0x0,0x0,0x0,0x0,0x0,0x0,0x0,0x0,0x0,0x0,0x0,0x0,0x0,0x0,0x0,0x0,0x0,0x0,0x0,0x0,0x0,0x0,0x0,0x0,0x0,0x0,0x0,0x0,0x0,0x0,0x0,0x0,0x0,0x0,0x0,0x0,0x0,0x0,0x0,0x0,0x0,0x0,0x0,0x0,0x0,0x0,0x0,0x0,0x0,0x0,0x0,0x0,0x0,0x0,0x0,0x0,0x0,0x0,0x0,0x0,0x0,0x0,0x0,0x0,0x0,0x0,0x0,0x0,0x0,0x0,0x0,0x0,0x0,0x0,0x0,0x0,0x0,0x0,0x0,0x0,0x0,0x0,0x0,0x0,0x0,0x0,0x0,0x0,0x0,0x0,0x0,0x0,0x0,0x0,0x0,0x0,0x0,0x0,0x0,0x0,0x0,0x0,0x0,0x0,0x0,0x0,0x0,0x0,0x0,0x0,0x0,0x0,0x0,0x0,0x0,0x0,0x0,0x0,0x0,0x0,0x0,0x0,0x0,0x0,0x0,0x0,0x0,0x0,0x0,0x0,0x0,0x0,0x0,0x0,0x0,0x0,0x0,0x0,0x0,0x0,0x0,0x0,0x0,0x0,0x0,0x0,0x0,0x0,0x0,0x0,0x0,0x0,0x0,0x0,0x0,0x0,0x0,0x0,0x0,0x0,0x0,0x0,0x0,0x0,0x0,0x0,0x0,0x0,0x0,0x0,0x0,0x0,0x0,0x0,0x0,0x0,0x0,0x0,0x0,0x0,0x0,0x0,0x0,0x0,0x0,0x0,0x0,0x0,0x0,0x0,0x0,0x0,0x0,0x0,0x0,0x0,0x0,0x0,0x0,0x0,0x0,0x0,0x0,0x0,0x0,0x0,0x0,0x0,0x0,0x0,0x0,0x0,0x0,0x0,0x0,0x0,0x0,0x0,0x0,0x0,0x0,0x0,0x0,0x0,0x0,0x0,0x0,0x0,0x0,0x0,0x0,0x0,0x0,0x0,0x0,0x0,0x0,0x0,0x0,0x0,0x0,0x0,0x0,0x0,0x0,0x0,0x0,0x0,0x0,0x0,0x0,0x0,0x0,0x0,0x0,0x0,0x0,0x0,0x0,0x0,0x0,0x0,0x0,0x0,0x0,0x0,0x0,0x0,0x0,0x0,0x0,0x0,0x0,0x0,0x0,0x0,0x0,0x0,0x0,0x0,0x0,0x0,0x0,0x0,0x0,0x0,0x0,0x0,0x0,0x0,0x0,0x0,0x0,0x0,0x0,0x0,0x0,0x0,0x0,0x0,0x0,0x0,0x0,0x0,0x0,0x0,0x0,0x0,0x0,0x0,0x0,0x0,0x0,0x0,0x0,0x0,0x0,0x0,0x0,0x0,0x0,0x0,0x0,0x0,0x0,0x0,0x0,0x0,0x0,0x0,0x0,0x0,0x0,0x0,0x0,0x0,0x0,0x0,0x0,0x0,0x0,0x0,0x0,0x0,0x0,0x0,0x0,0x0,0x0,0x0,0x0,0x0,0x0,0x0,0x0,0x0,0x0,0x0,0x0,0x0,0x0,0x0,0x0,0x0,0x0,0x0,0x0,0x0,0x0,0x0,0x0,0x0,0x0,0x0,0x0,0x0,0x0,0x0,0x0,0x0,0x0,0x0,0x0,0x0,0x0,0x0,0x0,0x0,0x0,0x0,0x0,0x0,0x0,0x0,0x0,0x0,0x0,0x0,0x0,0x0,0x0,0x0,0x0,0x0,0x0,0x0,0x0,0x0,0x0,0x0,0x0,0x0,0x0,0x0,0x0,0x0,0x0,0x0,0x0,0x0,0x0,0x0,0x0,0x0,0x0,0x0,0x0,0x0,0x0,0x0,]

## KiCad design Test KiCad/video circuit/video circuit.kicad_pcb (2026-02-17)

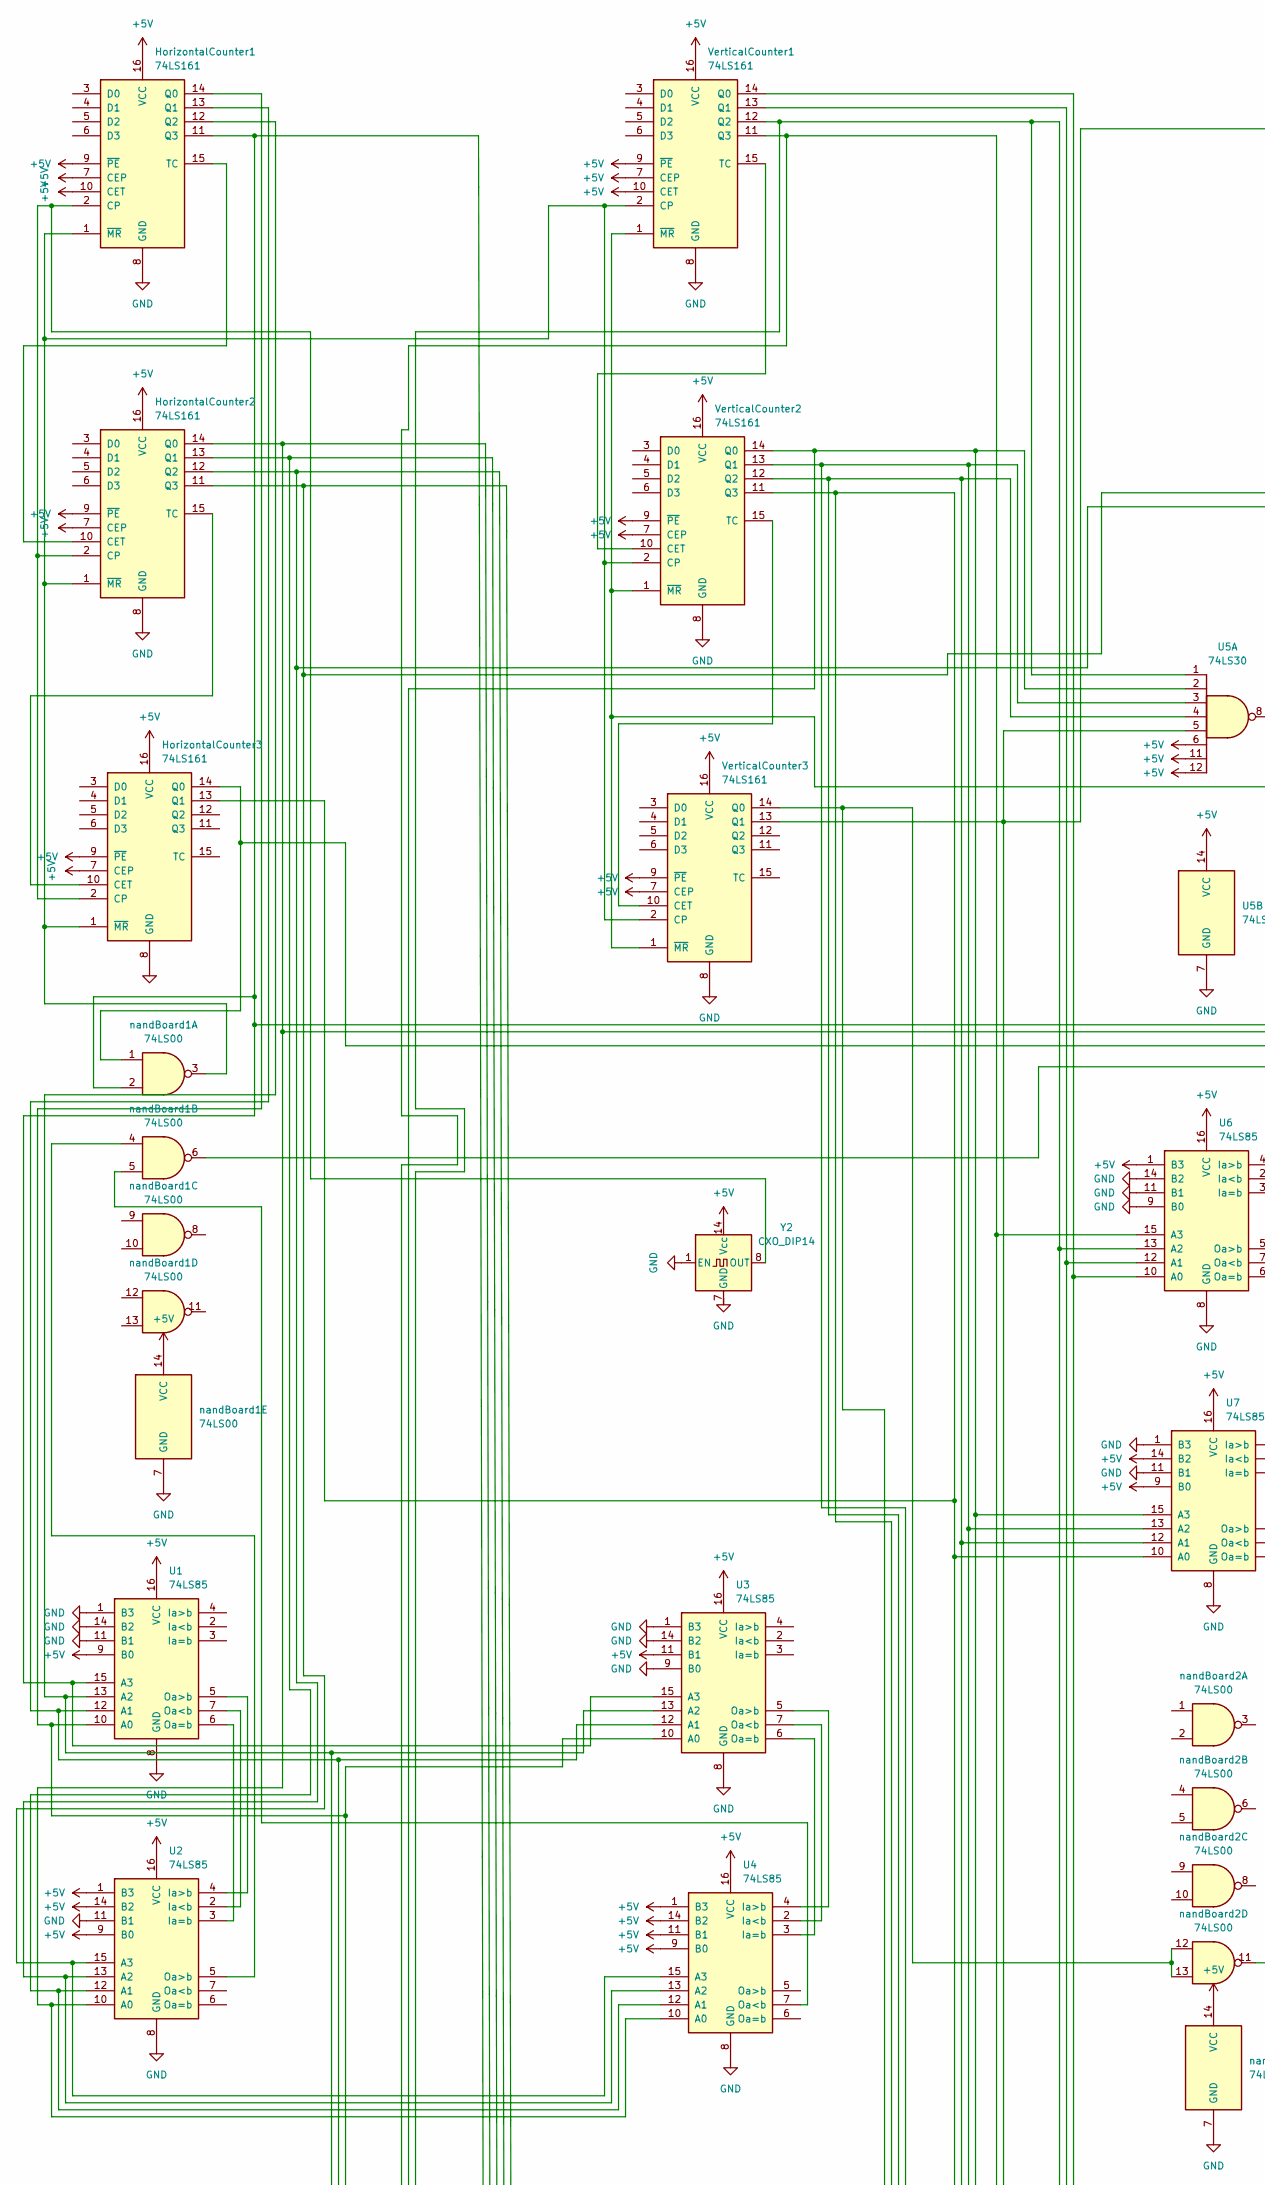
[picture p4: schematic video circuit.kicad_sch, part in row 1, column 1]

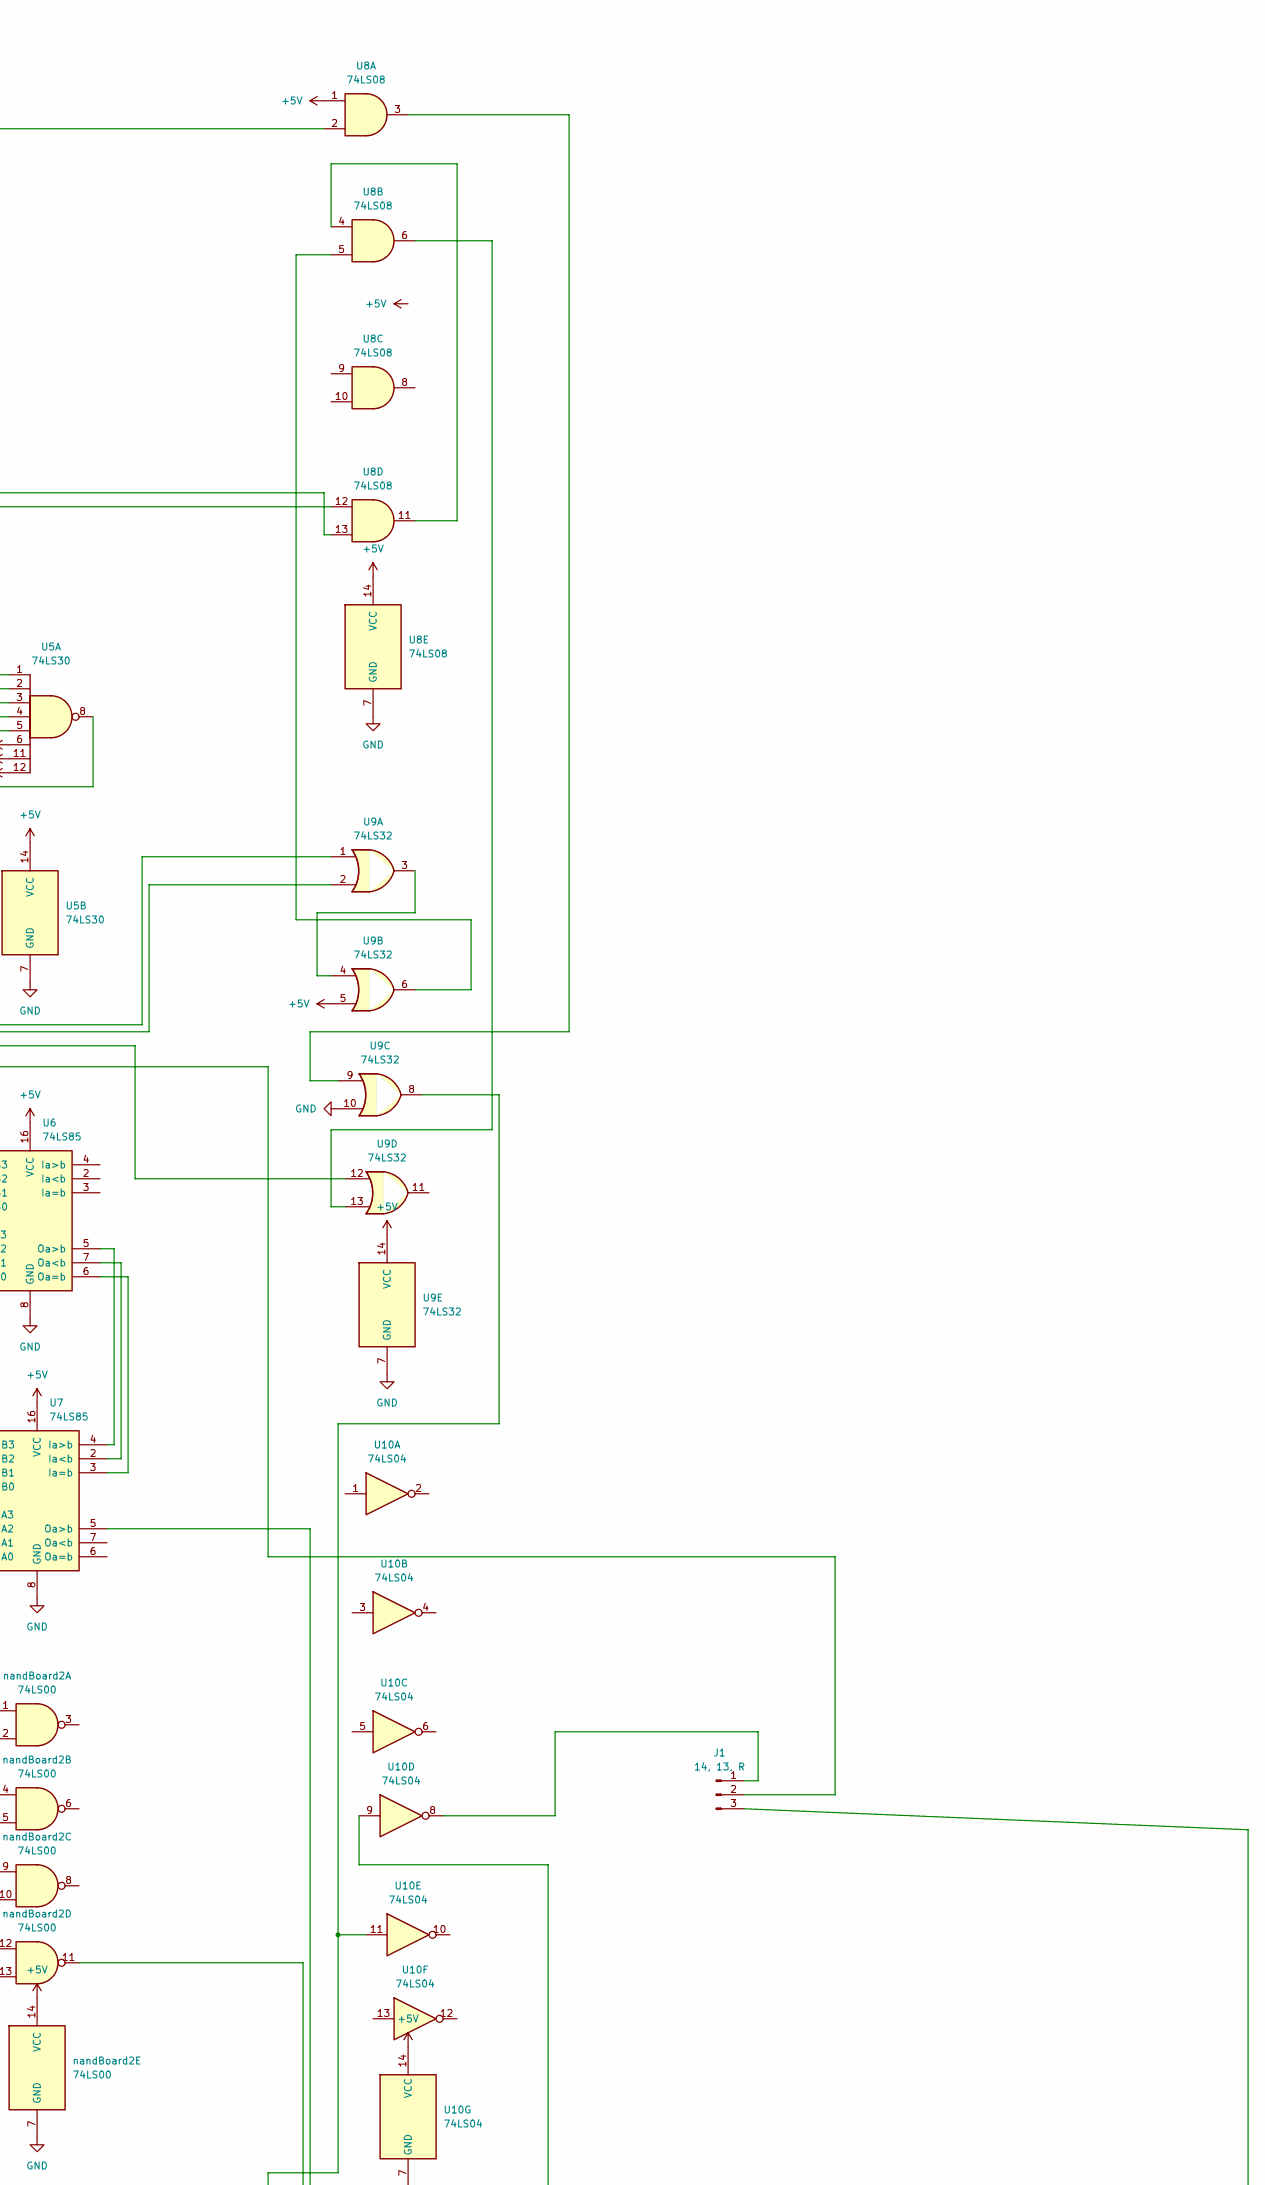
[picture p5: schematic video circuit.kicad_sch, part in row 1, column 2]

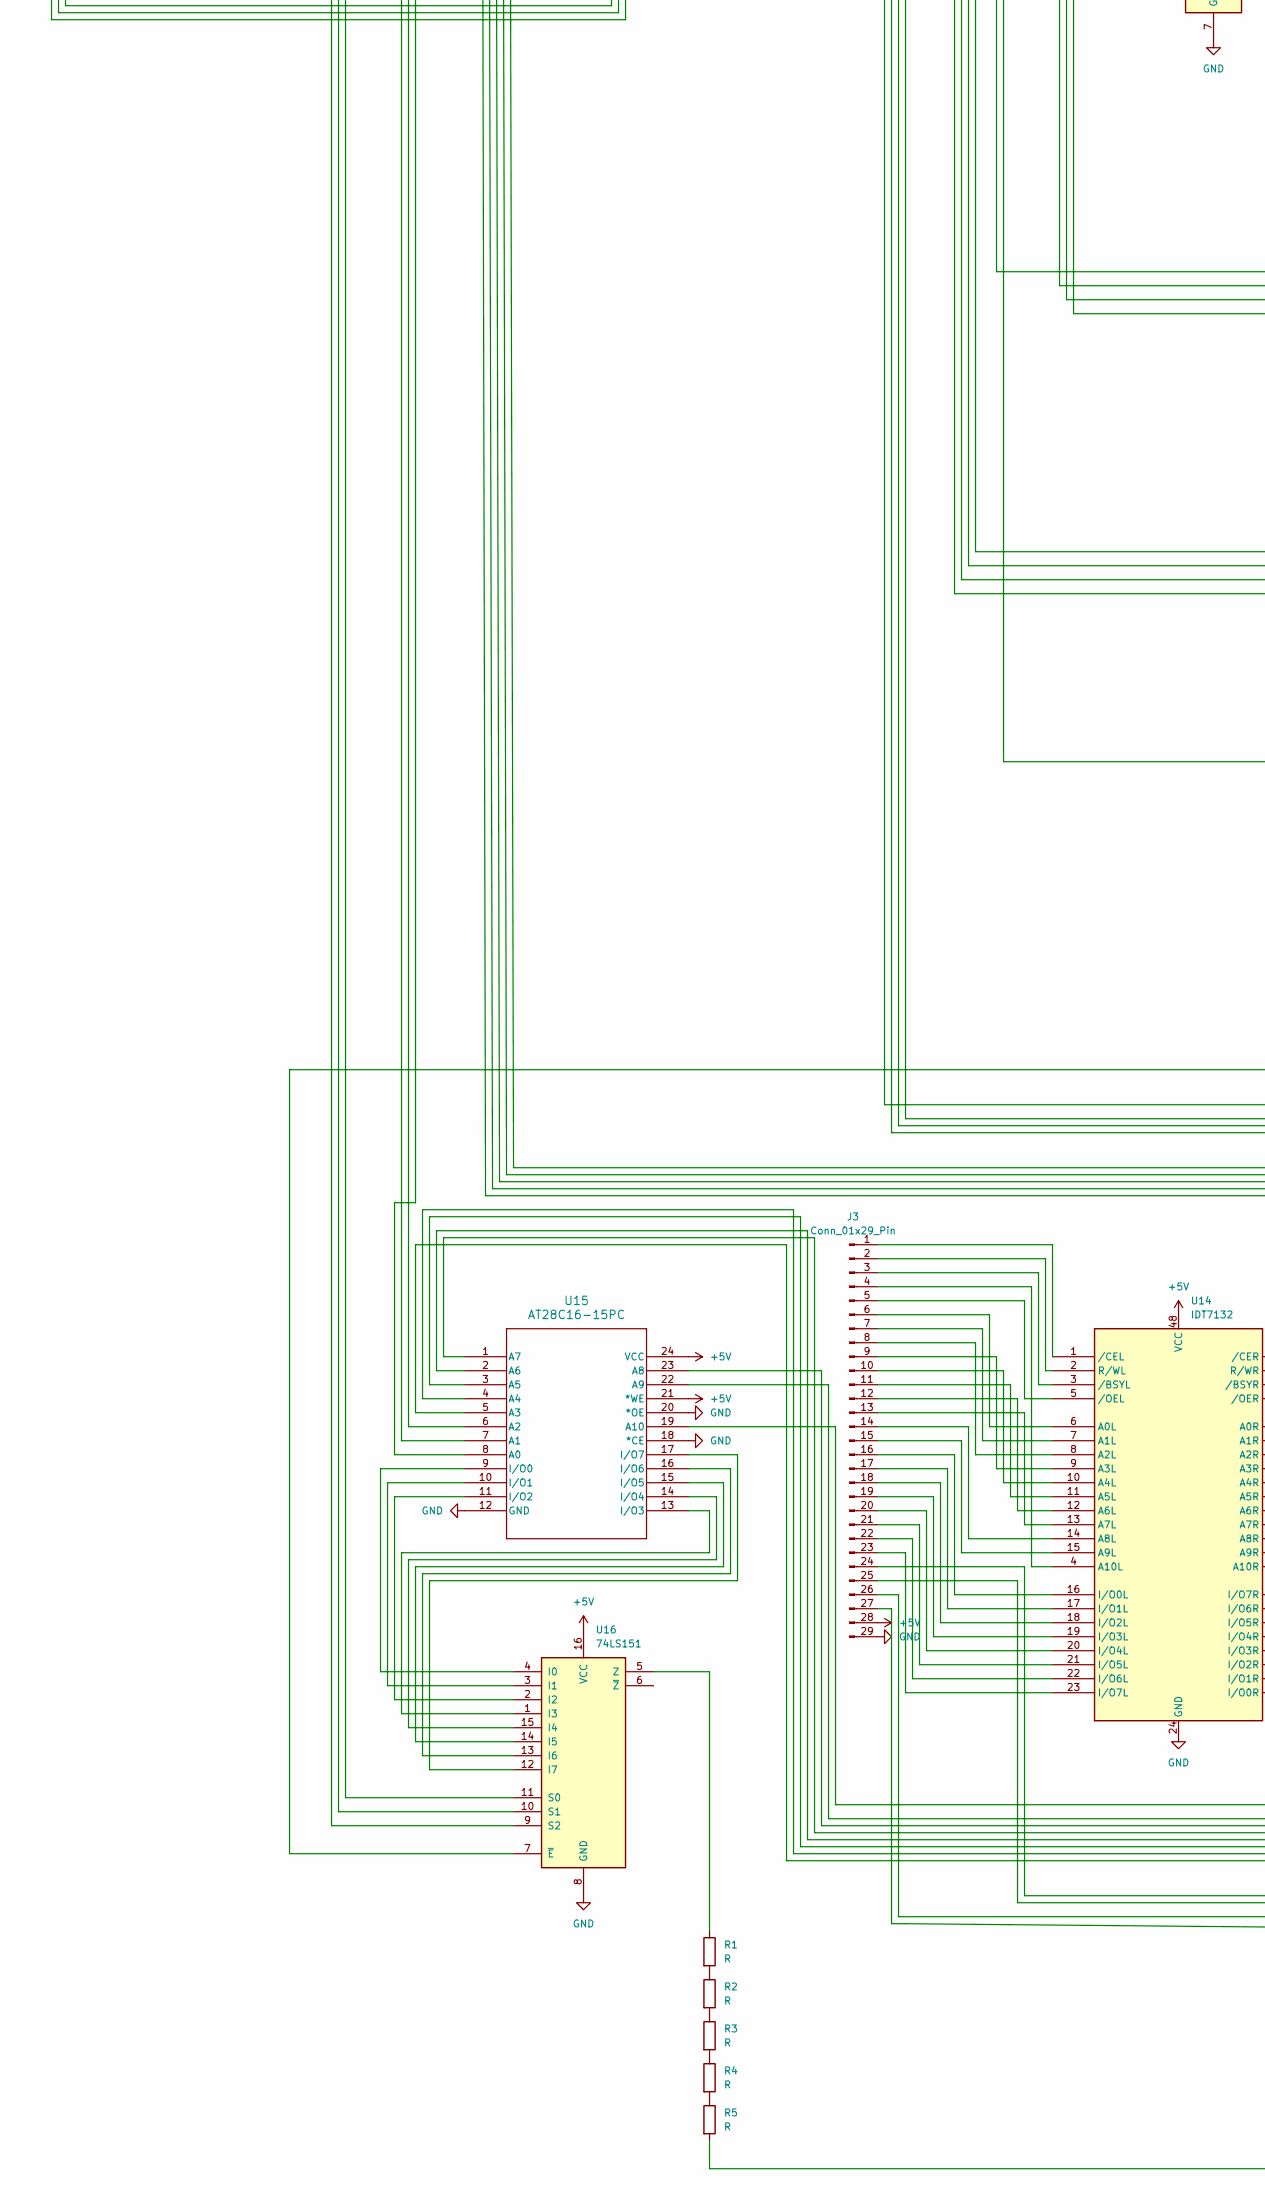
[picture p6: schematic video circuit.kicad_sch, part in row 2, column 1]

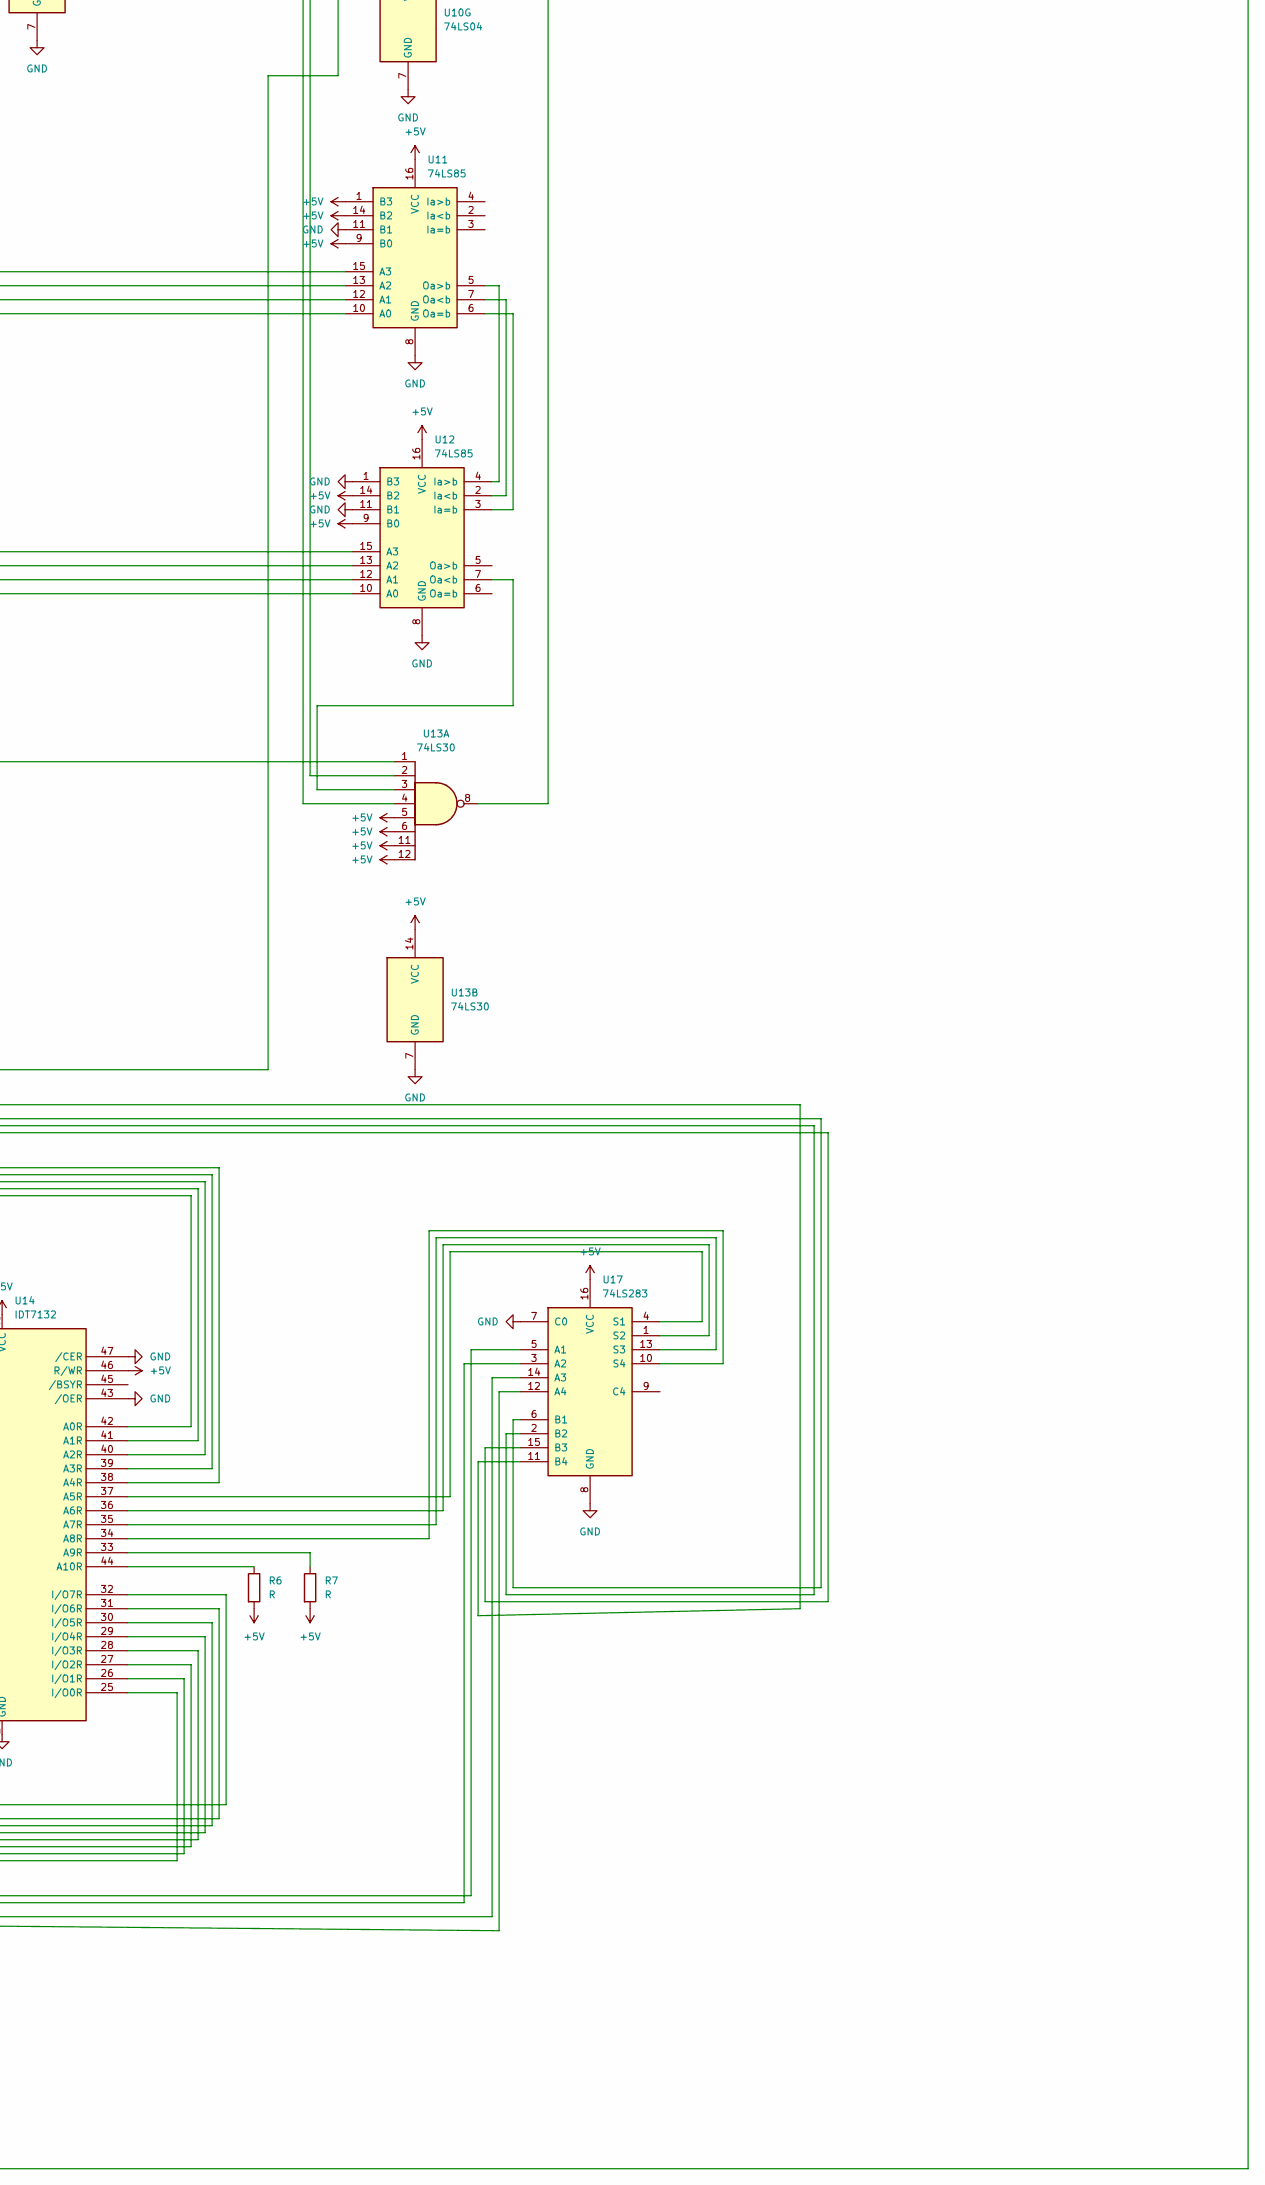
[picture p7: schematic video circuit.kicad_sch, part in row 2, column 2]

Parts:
HorizontalCounter1, HorizontalCounter2, HorizontalCounter3: 74LS161; DIP-16_W7.62mm_Socket_LongPads
J1: 14, 13, R; PinHeader_1x03_P2.54mm_Vertical
J3: Conn_01x29_Pin; PinHeader_1x29_P2.54mm_Vertical
R1, R2, R3, R4, R5, R6, R7: R; R_Axial_DIN0204_L3.6mm_D1.6mm_P5.08mm_Horizontal
U1, U2, U3, U4, U6, U7, U11, U12: 74LS85; DIP-16_W7.62mm_Socket_LongPads
U5, U13: 74LS30; DIP-14_W7.62mm_Socket_LongPads
U8: 74LS08; DIP-14_W7.62mm_Socket_LongPads
U9: 74LS32; DIP-14_W7.62mm_Socket_LongPads
U10: 74LS04; DIP-14_W7.62mm_Socket_LongPads
U14: IDT7132; DIP-48_W15.24mm_LongPads
U15: AT28C16-15PC; PDIP24_14P4X32P3_MCH
U16: 74LS151; DIP-16_W7.62mm_LongPads
U17: 74LS283; DIP-16_W7.62mm_LongPads
VerticalCounter1, VerticalCounter2, VerticalCounter3: 74LS161; DIP-16_W7.62mm_Socket_LongPads
Y2: CXO_DIP14; Oscillator_DIP-14
nandBoard1, nandBoard2: 74LS00; DIP-14_W7.62mm_Socket_LongPads

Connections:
+5V: HorizontalCounter1.7 (CEP), HorizontalCounter1.9 (~PE), HorizontalCounter1.10 (CET), HorizontalCounter1.16 (VCC), HorizontalCounter2.7 (CEP), HorizontalCounter2.9 (~PE), HorizontalCounter2.16 (VCC), HorizontalCounter3.7 (CEP), HorizontalCounter3.9 (~PE), HorizontalCounter3.16 (VCC), J3.28, R6.2, R7.2, U1.9 (B0), U1.16 (VCC), U2.1 (B3), U2.9 (B0), U2.14 (B2), U2.16 (VCC), U3.11 (B1), U3.16 (VCC), U4.1 (B3), U4.9 (B0), U4.11 (B1), U4.14 (B2), U4.16 (VCC), U5.6, U5.11, U5.12, U5.14 (VCC), U6.1 (B3), U6.16 (VCC), U7.9 (B0), U7.14 (B2), U7.16 (VCC), U8.1, U8.14 (VCC), U9.5, U9.14 (VCC), U10.14 (VCC), U11.1 (B3), U11.9 (B0), U11.14 (B2), U11.16 (VCC), U12.9 (B0), U12.14 (B2), U12.16 (VCC), U13.5, U13.6, U13.11, U13.12, U13.14 (VCC), U14.46 (R/WR), U14.48 (VCC), U15.21 (*WE), U15.24 (VCC), U16.16 (VCC), U17.16 (VCC), VerticalCounter1.7 (CEP), VerticalCounter1.9 (~PE), VerticalCounter1.10 (CET), VerticalCounter1.16 (VCC), VerticalCounter2.7 (CEP), VerticalCounter2.9 (~PE), VerticalCounter2.16 (VCC), VerticalCounter3.7 (CEP), VerticalCounter3.9 (~PE), VerticalCounter3.16 (VCC), Y2.14 (Vcc), nandBoard1.14 (VCC), nandBoard2.14 (VCC)
GND: HorizontalCounter1.8 (GND), HorizontalCounter2.8 (GND), HorizontalCounter3.8 (GND), J3.29, U1.1 (B3), U1.8 (GND), U1.11 (B1), U1.14 (B2), U2.8 (GND), U2.11 (B1), U3.1 (B3), U3.8 (GND), U3.9 (B0), U3.14 (B2), U4.8 (GND), U5.7 (GND), U6.8 (GND), U6.9 (B0), U6.11 (B1), U6.14 (B2), U7.1 (B3), U7.8 (GND), U7.11 (B1), U8.7 (GND), U9.7 (GND), U9.10, U10.7 (GND), U11.8 (GND), U11.11 (B1), U12.1 (B3), U12.8 (GND), U12.11 (B1), U13.7 (GND), U14.24 (GND), U14.43 (/OER), U14.47 (/CER), U15.12 (GND), U15.18 (*CE), U15.20 (*OE), U16.8 (GND), U17.7 (C0), U17.8 (GND), VerticalCounter1.8 (GND), VerticalCounter2.8 (GND), VerticalCounter3.8 (GND), Y2.1 (EN), nandBoard1.7 (GND), nandBoard2.7 (GND)
unnamed: HorizontalCounter1.2 (CP), HorizontalCounter2.2 (CP), HorizontalCounter3.2 (CP), Y2.8 (OUT)
unnamed: HorizontalCounter1.14 (Q0), U1.10 (A0), U3.10 (A0), U16.11 (S0)
unnamed: HorizontalCounter1.13 (Q1), U1.12 (A1), U3.12 (A1), U16.10 (S1)
unnamed: HorizontalCounter1.12 (Q2), U1.13 (A2), U3.13 (A2), U16.9 (S2)
unnamed: HorizontalCounter1.11 (Q3), U1.15 (A3), U3.15 (A3), U9.1, U14.42 (A0R), nandBoard1.2
unnamed: HorizontalCounter1.15 (TC), HorizontalCounter2.10 (CET)
unnamed: HorizontalCounter1.1 (~MR), HorizontalCounter2.1 (~MR), HorizontalCounter3.1 (~MR), VerticalCounter1.2 (CP), VerticalCounter2.2 (CP), VerticalCounter3.2 (CP), nandBoard1.3
unnamed: HorizontalCounter2.14 (Q0), U2.10 (A0), U4.10 (A0), U9.2, U14.41 (A1R)
unnamed: HorizontalCounter2.13 (Q1), U2.12 (A1), U4.12 (A1), U14.40 (A2R)
unnamed: HorizontalCounter2.12 (Q2), U2.13 (A2), U4.13 (A2), U8.12, U14.39 (A3R)
unnamed: HorizontalCounter2.11 (Q3), U2.15 (A3), U4.15 (A3), U8.13, U14.38 (A4R)
unnamed: HorizontalCounter2.15 (TC), HorizontalCounter3.10 (CET)
unnamed: HorizontalCounter3.14 (Q0), U9.12, nandBoard1.1
unnamed: HorizontalCounter3.13 (Q1), U7.10 (A0), U12.10 (A0), U17.15 (B3), VerticalCounter2.11 (Q3)
unnamed: J1.1, U10.8
unnamed: J1.2, nandBoard1.6
unnamed: J1.3, R5.2
unnamed: J3.1, U14.1 (/CEL)
unnamed: J3.2, U14.2 (R/WL)
unnamed: J3.3, U14.3 (/BSYL)
unnamed: J3.4, U14.4 (A10L)
unnamed: J3.5, U14.5 (/OEL)
unnamed: J3.6, U14.6 (A0L)
unnamed: J3.7, U14.7 (A1L)
unnamed: J3.8, U14.8 (A2L)
unnamed: J3.9, U14.9 (A3L)
unnamed: J3.10, U14.10 (A4L)
unnamed: J3.11, U14.11 (A5L)
unnamed: J3.12, U14.12 (A6L)
unnamed: J3.13, U14.13 (A7L)
unnamed: J3.14, U14.14 (A8L)
unnamed: J3.15, U14.15 (A9L)
unnamed: J3.16, U14.16 (I/O0L)
unnamed: J3.17, U14.17 (I/O1L)
unnamed: J3.18, U14.18 (I/O2L)
unnamed: J3.19, U14.19 (I/O3L)
unnamed: J3.20, U14.20 (I/O4L)
unnamed: J3.21, U14.21 (I/O5L)
unnamed: J3.22, U14.22 (I/O6L)
unnamed: J3.23, U14.23 (I/O7L)
unnamed: J3.24, U17.5 (A1)
unnamed: J3.25, U17.3 (A2)
unnamed: J3.26, U17.14 (A3)
unnamed: J3.27, U17.12 (A4)
unnamed: R1.2, R2.1
unnamed: R2.2, R3.1
unnamed: R3.2, R4.1
unnamed: R4.2, R5.1
unnamed: U1.7 (Oa<b), U2.2 (Ia<b)
unnamed: U1.6 (Oa=b), U2.3 (Ia=b)
unnamed: U1.5 (Oa>b), U2.4 (Ia>b)
unnamed: U2.5 (Oa>b), nandBoard1.4
unnamed: U3.7 (Oa<b), U4.2 (Ia<b)
unnamed: U3.6 (Oa=b), U4.3 (Ia=b)
unnamed: U3.5 (Oa>b), U4.4 (Ia>b)
unnamed: U4.7 (Oa<b), nandBoard1.5
unnamed: U6.7 (Oa<b), U7.2 (Ia<b)
unnamed: U6.6 (Oa=b), U7.3 (Ia=b)
unnamed: U6.5 (Oa>b), U7.4 (Ia>b)
unnamed: U7.5 (Oa>b), U13.2
unnamed: U8.3, U9.9
unnamed: U8.5, U9.6
unnamed: U8.6, U9.13
unnamed: U8.4, U8.11
unnamed: U9.3, U9.4
unnamed: U10.9, U13.8
unnamed: U6.10 (A0), U11.10 (A0), VerticalCounter1.14 (Q0)
unnamed: U6.12 (A1), U11.12 (A1), VerticalCounter1.13 (Q1)
unnamed: U5.1, U6.13 (A2), U11.13 (A2), U15.8 (A0), VerticalCounter1.12 (Q2)
unnamed: U6.15 (A3), U11.15 (A3), U15.7 (A1), VerticalCounter1.11 (Q3)
unnamed: U11.7 (Oa<b), U12.2 (Ia<b)
unnamed: U11.6 (Oa=b), U12.3 (Ia=b)
unnamed: U11.5 (Oa>b), U12.4 (Ia>b)
unnamed: U5.4, U7.12 (A1), U12.12 (A1), U17.2 (B2), VerticalCounter2.12 (Q2)
unnamed: U5.3, U7.13 (A2), U12.13 (A2), U17.6 (B1), VerticalCounter2.13 (Q1)
unnamed: U5.2, U7.15 (A3), U12.15 (A3), U15.6 (A2), VerticalCounter2.14 (Q0)
unnamed: U12.7 (Oa<b), U13.3
unnamed: U13.4, nandBoard2.11
unnamed: U14.37 (A5R), U17.4 (S1)
unnamed: U14.36 (A6R), U17.1 (S2)
unnamed: U14.35 (A7R), U17.13 (S3)
unnamed: U14.34 (A8R), U17.10 (S4)
unnamed: R7.1, U14.33 (A9R)
unnamed: R6.1, U14.44 (A10R)
unnamed: U14.25 (I/O0R), U15.5 (A3)
unnamed: U14.26 (I/O1R), U15.4 (A4)
unnamed: U14.27 (I/O2R), U15.3 (A5)
unnamed: U14.28 (I/O3R), U15.2 (A6)
unnamed: U14.29 (I/O4R), U15.1 (A7)
unnamed: U14.30 (I/O5R), U15.23 (A8)
unnamed: U14.31 (I/O6R), U15.22 (A9)
unnamed: U14.32 (I/O7R), U15.19 (A10)
unnamed: U15.9 (I/O0), U16.4 (I0)
unnamed: U15.10 (I/O1), U16.3 (I1)
unnamed: U15.11 (I/O2), U16.2 (I2)
unnamed: U15.13 (I/O3), U16.1 (I3)
unnamed: U15.14 (I/O4), U16.15 (I4)
unnamed: U15.15 (I/O5), U16.14 (I5)
unnamed: U15.16 (I/O6), U16.13 (I6)
unnamed: U15.17 (I/O7), U16.12 (I7)
unnamed: R1.1, U16.5 (Z)
unnamed: U9.8, U10.11, U16.7 (~E)
unnamed: U17.11 (B4), VerticalCounter3.14 (Q0), nandBoard2.12, nandBoard2.13
unnamed: VerticalCounter1.15 (TC), VerticalCounter2.10 (CET)
unnamed: U5.8, VerticalCounter1.1 (~MR), VerticalCounter2.1 (~MR), VerticalCounter3.1 (~MR)
unnamed: VerticalCounter2.15 (TC), VerticalCounter3.10 (CET)
unnamed: U5.5, U8.2, U13.1, VerticalCounter3.13 (Q1)

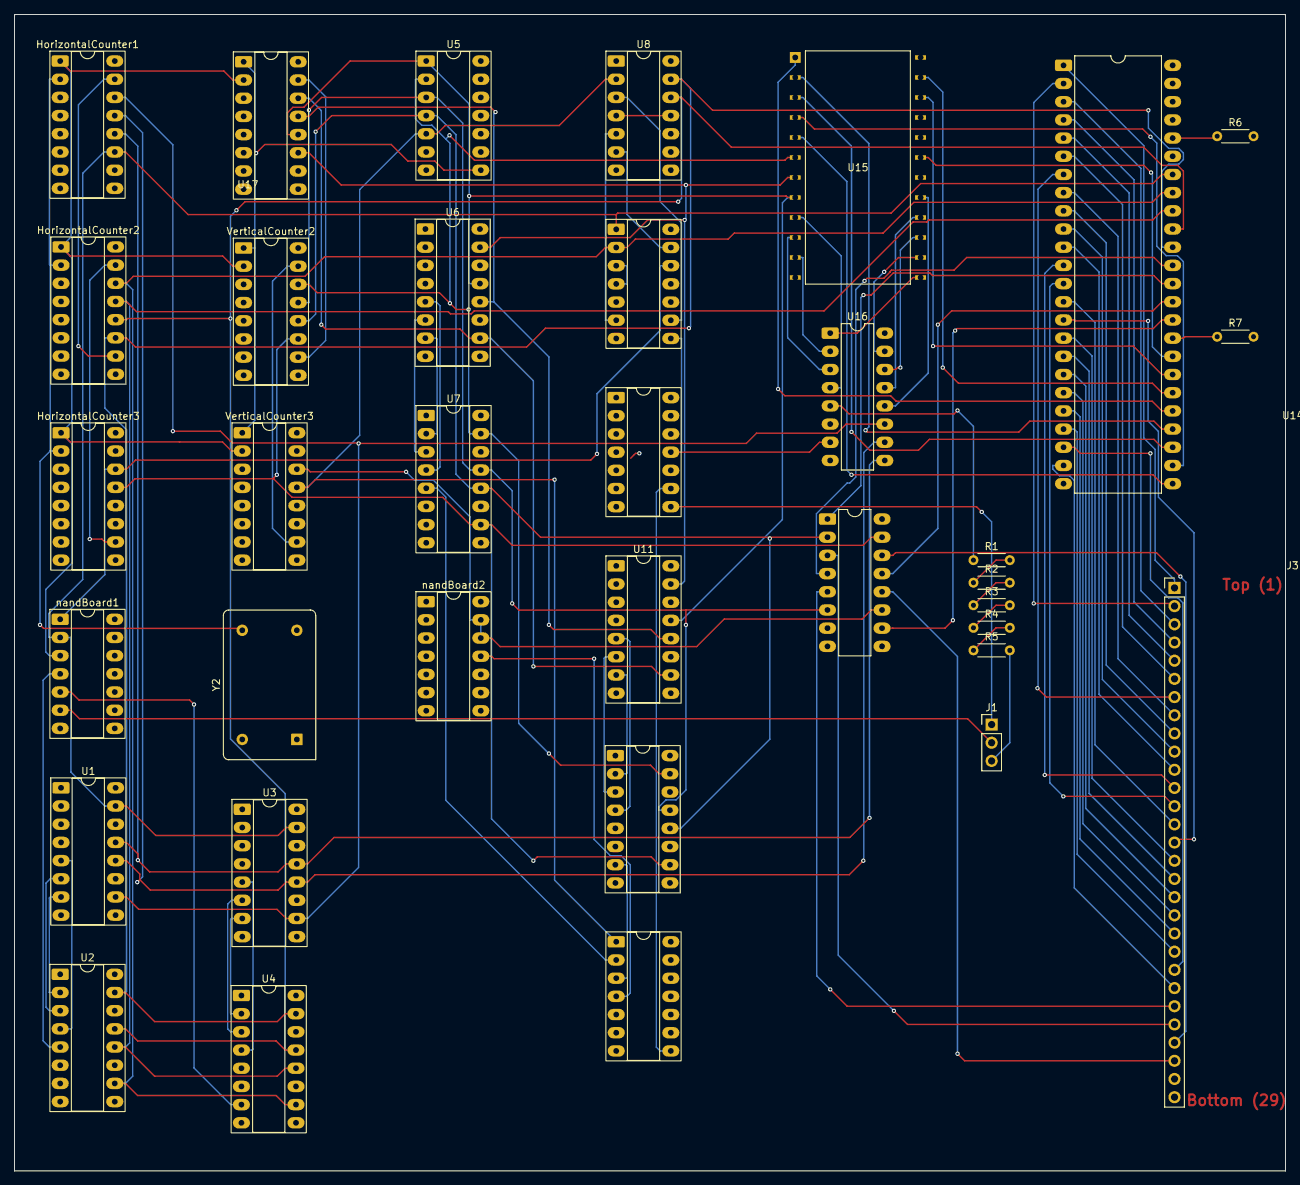
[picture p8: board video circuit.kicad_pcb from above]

Board: 2 copper layers, 177.5 x 161.5 mm, 35 parts (0 on the bottom side), 109 nets.

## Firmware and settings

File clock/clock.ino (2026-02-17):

const int CLOCK_PIN = 8;
const int DELAY_TIME = 100;
String received_char;

void setup() {
  // put your setup code here, to run once:
  pinMode(CLOCK_PIN, OUTPUT);
  Serial.begin(9600);
}

void loop() {
  // put your main code here, to run repeatedly:

      digitalWrite(CLOCK_PIN, HIGH);
      delay(DELAY_TIME);
      digitalWrite(CLOCK_PIN, LOW);
      delay(DELAY_TIME);

}
